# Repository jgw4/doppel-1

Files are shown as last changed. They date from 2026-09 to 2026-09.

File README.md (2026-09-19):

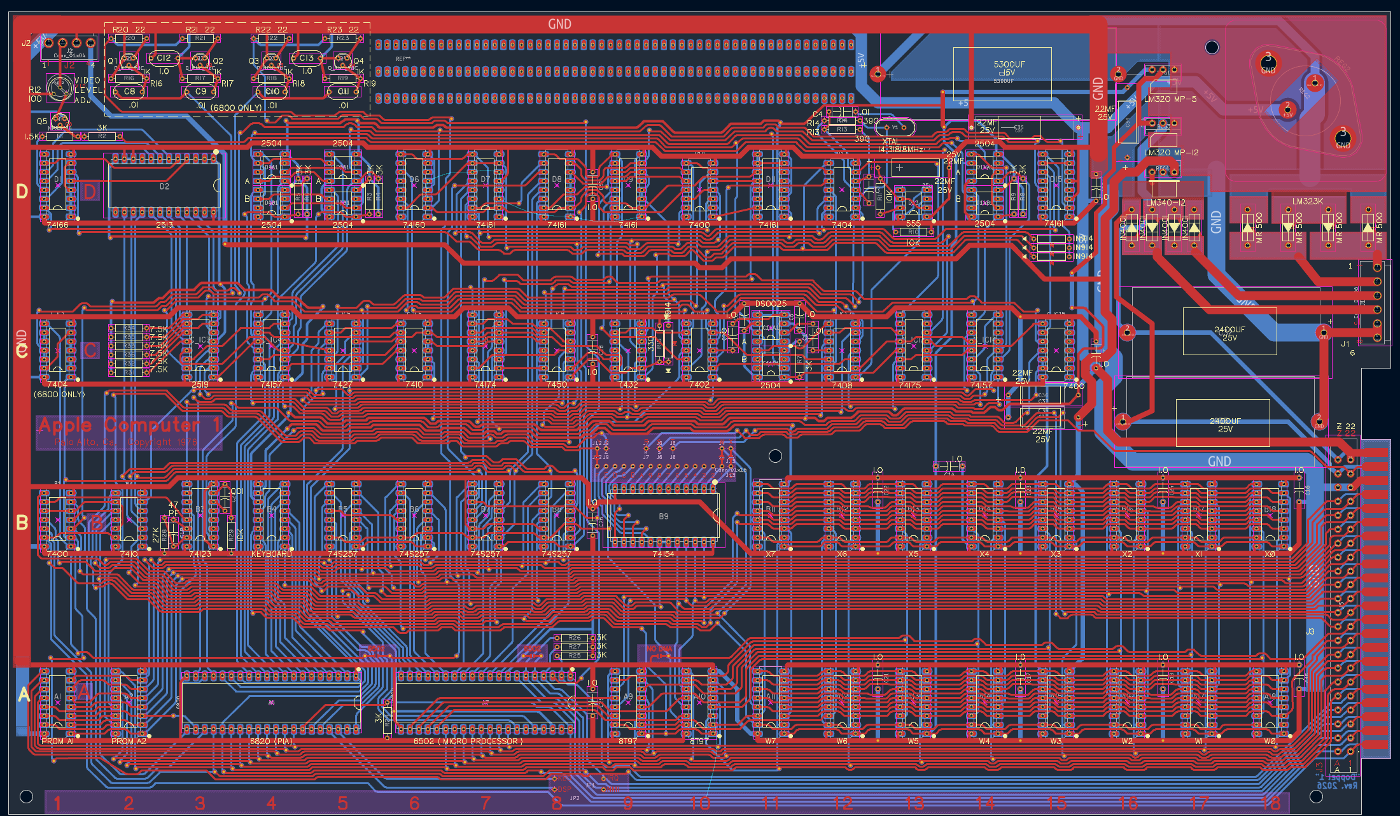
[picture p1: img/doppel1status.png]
Doppel-1 Current Status

Doppel-1 As of 2026/09/18

# About the "Doppel-1"
This repository contains the "Doppel-1", an Apple-1 Replica PCB. It is unique among clone boards in that the source design files are completely open-source, and It is built in standard EDA fashion, where each component on the board is linked to a symbol on a full schematic of the apple-1. This also allows for generating gerber files at the source, easy modification, and the ability to highlight trace sets on the board via the net selector. This makes it very useful when diagnosing build issues. It also features a near full set of 3d components, which allows an accurate step file to be exported.

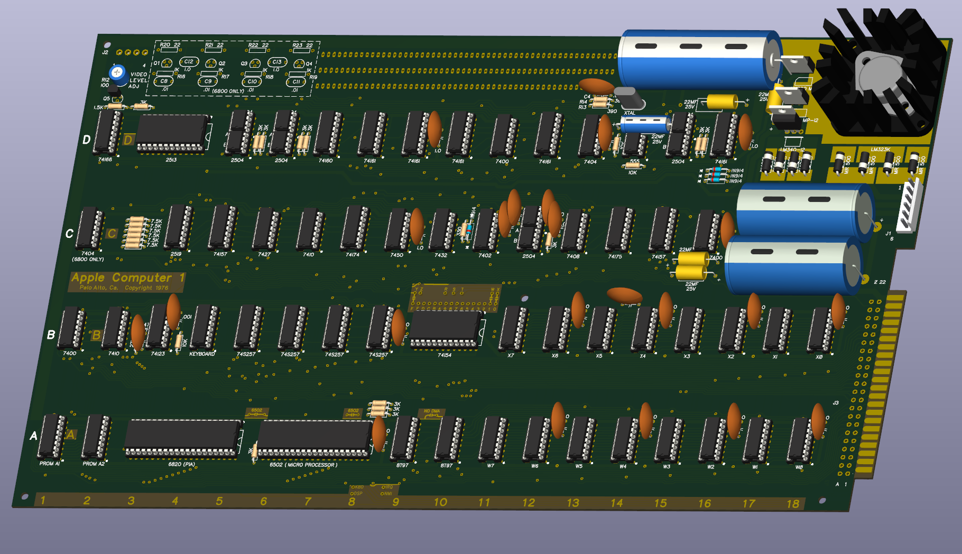
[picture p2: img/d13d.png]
Doppel-1 3D

Doppel-1 within KiCad 3D Viewer

Great care has been taken to create a custom library of footprints that match the original apple-1. In fact, every symbol on the board is custom. This preserves the aesthetics of the pads and silkscreens while allowing for pin-pin linkage from the schematic.

Clarifying remarks have been made to ensure that the PCB is being fabricated to make a reasonable replica. If you desire to make your own board from these files, please read the Manufacturing Notes below.

## History
This project started by importing the gerber files for the "PCB-11" replica that I found on [Applefritter Forums](https://www.applefritter.com/content/apple-1-replica-gerber-files), which were posted originally on a facebook group. It is the only clone board that I know of where the gerber files have been made publicly available. Little by little, I began replacing gerber features with native KiCad features, until there was almost nothing left of the original gerber (see "Open Issues..." Below). A theseus ship of sorts, but improved.

## Open Issues of the Doppel-1

* All board silkscreen text is contained within the top board layer. I have decided that there is no font matched well enough at this time to rely on a font alone. Only shapes have been redrawn at the footprint level.
* Need to fix issues with a few improper diode silkscreen arrow placements
* Proper widths and clearances still need assigned to all traces, ensuring proper spacing from all solder pads and enforcing a more rigorous Design Rules Check.
* I am still not entirely certain the board mounting holes are in the correct position. I had modified it slightly see point 7 below.
* a few remaining schematic parity errors.
* some footprints still don't have 3d models assigned. I think at this time only the molex 4-pin and 6-pin
* I would like to develop a custom font based off the text on this board, so it can be applied as text elements rather than drawn shapes.

## Design Notes And Changes
I have made some remarks about my observations so far:

1) The silkscreen text on the Apple-1 PCB is extremely difficult to reproduce. By all accounts it was hand-stenciled, and I have spent more time than I care to admit comparing uniform-stroke technical typefaces that are meant to replicate leroy lettering or other technical stencil packages that are freely available online, but none of them have quite matched what I have seen on the PCB-11 and on other clones. I have messed around with the font "Routed Gothic" and found it to be closest but kerning is not quite there, and it still does not match with the characters aforementioned. I can hack my way to passable kerning by adjusting the height-width ratio of the text boxes but it is not ideal. I believe Iwater GMaru Gothic Pro is a better match to the original, however that is a paid font that I am unwilling to obtain due to licensing. For any future work on a custom font for this computer, I have included a character "Proof Area" in the PCB file which contains every character on the board.

2) The solder pads on the DIP sockets and breadboard area on "PCB-11" are round on both front and back layers, while on original units, the solderpads were actually different on the back side vs the front. On the back they were a squashed oval (basically an obround but the end arcs share a center point with the rectangle's center point), and on the front they were smaller, tangent obrounds. This was most likely done to make it easy to solder while leaving room for trace paths on the front. This is something a lot of replicas miss.

3) The trace leading to the positive lead between B&C @16 has been adjusted to match the Mimeo-1

4) The trace between C&D @15 leeting to the via below IN914 diode at a 45 degree angle has been moved down slightly to match the Mimeo-1

5) silkscreen outlines for DIP sockets has been increased to a width of 10mils to match what is expected

6) In the original manual's schematics, as well as the ones made by Nicolas, there is an error in the pinouts listed for the TO-220 diodes (REG1,REG3,REG4/LM320 MP-5/LM320 MP-12/LM340 MP-12). LM320 has ground at pin 1, while in and out are pins 2&3, respectively.LM340 has ground at 2 and in/out at 1/3 like a more standard diode in this package. This was discovered by DRC error checking.

7) The top right mounting via has been moved right 100mils to match Mike Willegal's case dimension [here](https://www.willegal.net/appleii/apple1-enclosure.htm). My assumption is that these are truer than what were originally on the board

8) The original applefritter post had a user comment that noted the following issues. My comments are appended to the original marks:
- The original has a matte finish, this one has a sligtly brighter green - This is a fabrication preference/availability, not with the design of the board. see "Manufacturing Notes".
- The silkscreen doesn't cover the plated areas without soldermask.
- The DIP and breadboard solder pads should be wider although it only really matters in the breadboard area. - See point 2 above, much scrutiny went into the shape of the dip pads on this board.
- The video adjustment pot pads are  narrower by 0.025", making it difficult to insert the trimpot. - The 100 Ohm pot has been replaced with a standard footprint that should rectify the issue

9) the LM323 footprint has been moved slightly to the left, on the original and observed builds, the heatsink would hang slightly over the board.

## Manufacturing Notes:

If you are going to get your own replica board manufactured, read this first:

0) Boards are to be purchased at your own risk. I do not take responsibility for any defects, design or otherwise, contained within your finished boards.

1) Normally the green finish provided by PCB manufacturers is way too dark. It has become clear to me that it will be almost impossible to replicate near-exact finishes for small volume with any direct-to-customer fabricators. If the fabricator does allow for lighter green finishes and/or matte green, these colors should be selected instead of a "Standard" green.

2) Boards that are finished with an ENIG process (i.e. full-board gold plating) are unable to also accomodate silkscreening on top of non-soldermasked copper. This is extremely evident in the top-right corner of the board where diode markings are missing where the gold is plated over the copper. It is understandable to desire gold for the longevity of the board, but doing so will produce a poor replica. ENIG is also not sufficient for edge fingers; since ENIG is a softer finish, it will wear just as if it were plated like a standard PCB. Hard Gold plating (not ENIG) is best for edge fingers, and should be confined to the edge fingers only, with the rest done in HAL SnPb.

3) I request that anyone exporting their own gerbers to not remove the replica signifying text on the bottom right on the back of the board. This board contains "Doppel-1 Rev. 2026" on the back copper layer underneath a silkscreen, so it is very discrete. While I think that there are many people out there that can detect replica boards without an unambiguous stamp on the board, I request all reading to preserve the marking to avoid the perception or attempts at counterfeiting.

## Why?
I have had a strange fascination for the Apple-1 ever since I was a kid. Even though I am not a competent electronics hobbyist or electrical engineer, I've been drawn to the technical artistry of the board, and find the assembly process and case design around it a very cool method of self-expression. I suppose also there is a love of historical artifact that comes with people who love these computers too, and I am very much in that camp.

# Contributing
1) To properly view some of the pcb file's text elements, you may need to  download and install "Routed Gothic" font located in `/doc/`. This is the closest match I have found to the original PCB lettering in font form and is based on the Leroy stenciling system common with draftsman before computer fonts.

2) I have a near certain guess that the original apple-1 pcb was designed using mils. Thus, I would strongly encourage any user working on this board to set their units to mils and not mm. The original PCB-11 file was most likely not made by an American, as there are many metric dimensions scattered throughout the document. However building in nice round mil numbers should be the standard for this project

3) please submit a pull request listing in detail all changes you have made or would like to make, preferably with pictures. This can help avoid any duplicate work. I can infer many changes by inspecting the changed files as text, but a more human-readable explanation helps.

4) Issues can also be raised, which I also enthusiastically accept. If you spot issues with the design of the board, please post an issue to the repository.

5) I am looking also for some more specific input on trace clearance. Since resizing the dip solderpads, clearance has been the biggest DRC issue. I would like to know what spacing was used on the original board so I can preserve that. Current clearance is set at 5 mils.

# Other Things to check out

[Erik's Ponderings - Building an Apple-1](https://blog.bruchez.name/posts/apple-1-reproduction-part-1-components/) - Erik Bruchez documented his process of building an exceptional Apple-1 clone in great detail, including some great tips for power supply building, adding more decoupling capacitors, mechanical tips, and more. Really neat to check out, especially before you build one of your own

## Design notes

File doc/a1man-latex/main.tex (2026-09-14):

\documentclass[letterpaper]{article}

% Core packages
\usepackage[top=1in,bottom=1in,left=1in,right=1in]{geometry}
\usepackage{graphicx}
\usepackage{multicol}
\usepackage{fancyhdr}
\usepackage{eso-pic}
\usepackage[explicit]{titlesec}
\usepackage{varwidth}
\usepackage{parskip}
\usepackage{tgcursor}
\usepackage{fontspec}

% Font setup
\fontsize{10pt}{10pt}\selectfont
\setmainfont[
  Path=fonts/,
  Extension=.ttf
]{Typewriter-Executive}

% Graphics paths
\graphicspath{{pages/}}

% Page number settings
\pagestyle{fancy}
\fancyhf{}                    % Clear all headers and footers
\fancyfoot[C]{-\thepage-}     % Bottom center: -1-
\renewcommand{\headrulewidth}{0pt}
\renewcommand{\footrulewidth}{0pt}
\setlength{\footskip}{24pt}

% Body text settings
\parskip=8pt
\parindent=3em
\setcounter{secnumdepth}{0}
\setlength{\fboxsep}{6pt}

% Section styling
\titleformat{\section}[block]
  {\normalfont\large\bfseries\centering}
  {}
  {0pt}
  {\makebox[\linewidth][c]{\fbox{\begin{varwidth}{\linewidth}\centering #1\end{varwidth}}}}
\titlespacing*{\section}{0pt}{*2}{*1}
%%%%%%%%%%%%%%%%%%%%%%%%%%%%%%%%%%%%%%%%%%%%%
\begin{document}
\begin{titlepage}
\thispagestyle{empty}
\centering

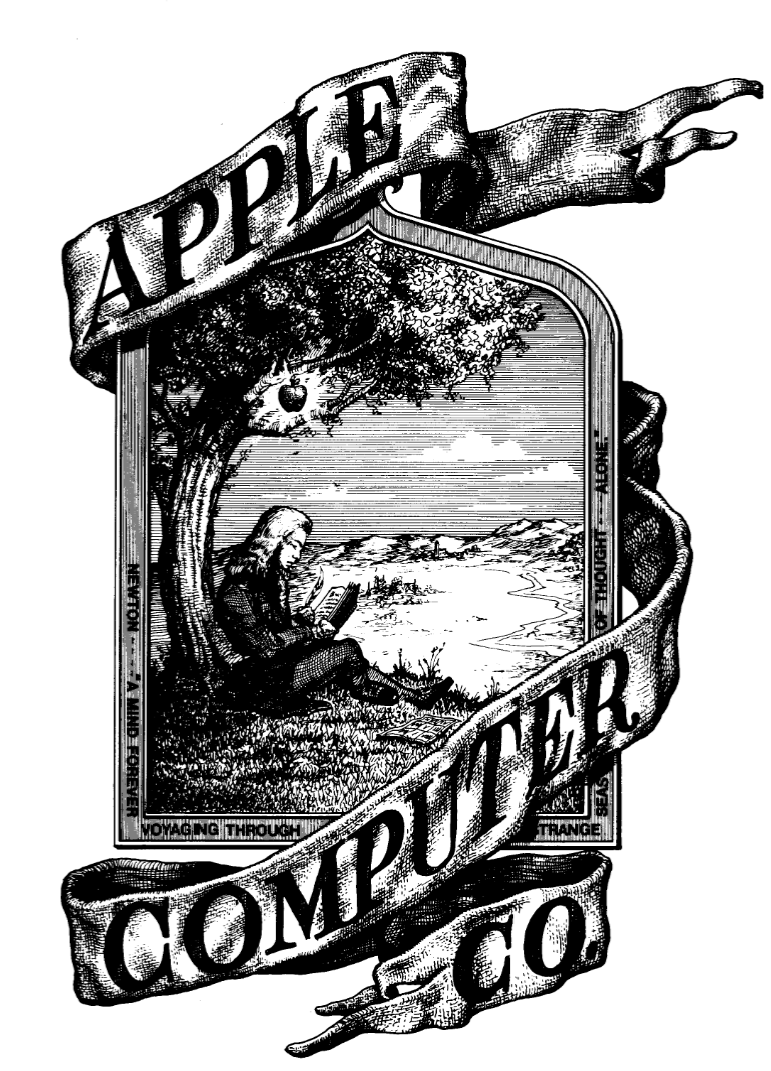
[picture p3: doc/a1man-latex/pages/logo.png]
\vspace{2.5cm}

{\bf \Huge
APPLE-1
\vspace{1cm}

OPERATION

MANUAL
}
\vspace{2cm}

{\fontspec{Helvetica}
APPLE COMPUTER COMPANY

770 Welch Road

Palo Alto, California 94304
}
\end{titlepage}
%%%%%%%%%%%%%%%%%%%%%%%%%%%%%%%%%%%%%%%%%%%%%
\begin{center}
  SPECIFICATIONS
\end{center}
\begin{tabular}{p{0.46\textwidth} p{0.46\textwidth}}
  
MICROPROCESSOR:&MOS Technology 6502\\

Microprocessor Clock Frequency:&1.023 MHz\\

Effective Cycle Frequency:&0.960 Mhz\\

(Including Refresh Waits)&\\

VIDEO OUTPUT:&Composite positive video, 75 ohms, level adjustable between zero and +5V pp.\\

Line Rate:&15734 Hz\\
Frame Rate:&60.06 Hz\\
Format&40 characters/line, 24 lines; with automatic scrolling\\
Display Memory:&Dynamic shift registers (1K x 7)\\
Character Matrix:&5 x 7\\
\end{tabular}
\clearpage
\setcounter{page}{1}
\newpage
\begin{center}
\section{INTRODUCTION}
\end{center}
\begin{multicols}{2}

The Apple Computer is a complete microprocessor system, consisting of a Mos Technology 6502 microprocessor and support hardware, integral video display electronics, dynamic memory and refresh hardware, and fully regulated power supplies. It contains resident system monitor software, enabling the user, via the keyboard and display, to write, examine, debug, and run programs efficiently; thus being an educational tool for the learning of microprocessor programming, and an aid in the development of software.

The integral video display section and the keyboard interface renders unnecessary the need for an external teletype. The display section contains its ownmemory, leaving all of RAM for user programs, and the output format is 40 characters/ line, 24 lines/page, with auto scrolling. Almost any ASCII encoded keyboard will interface directly with the Apple system.

The board has sockets for upto 8K bytes of the 16 pin, 4K type, RAM, and the system is fully expandable to 65K via the edge connector. The system uses dynamic memory (4K bytes supplied), although static memory may also be used. All refreshing of dynamic memory, including all "off-board'" expansion memory, is done automatically. The entire system timing, including the microprocessor clock and all video signals, originates in a single crystal oscillator.

Further, the printed circuit board contains a "breadboard area", in which the user can add additional "on-board" hardware (for example, extra PIA's, ACIA's, EROM's, and so on).

This manual is divided into three Sections:

\noindent Section I GETTING THE SYSTEM RUNNING

\noindent Section II USING THE SYSTEM MONITOR. (listing included)

\noindent Section III EXPANDING THE SYSTEM.

Please read Section I thoroughly, before attempting to "power-up" your system, and study Section III carefully before attempting to expand your system. In addition to this manual, Apple 'Tech Notes" are available which contain examples of expansion hardware and techniques.
\end{multicols}
\begin{center}
\section{SECTION I
\newline
GETTING THE SYSTEM RUNNING}   
\end{center}

\begin{multicols}{2}
The Apple Computer is fully assembled, tested, and burned in. The only external devices necessary for operation of the system are: An ASCII encoded keyboard, a video display monitor, and AC power sources of 8 to 10 Volts (RMS) @3 amps and 28Volts(RMS)@1 amp. The following three articles describe the attachment of these devices in detail.

\noindent Keyboard:

Any ASCII encoded keyboard, with positive DATA outputs, interfaces directly with the Apple system via a "DIP" connector, If your keyboard has negative logic DATA outputs (rare), you can install inverters (7404) in the breadboard area. The strobe can be either positive or negative, of long or short duration. The 'DIP" keyboard connector (B4) has inputs for seven DATA lines, one STROBE line, and two normally-open pushbutton switches, used for RESET (enter monitor), and CLEAR SCREEN (see schematic diagram, sheet 3 of 3, for exact circuitry). This keyboard connector also supplies three voltages, (45V, +12V, and-12V) of which one or more may be necessary to operate the keyboard. Pin 15 of the keyboard connector (B4) must be tied to +5V (pin 16) for normal operation,

\noindent NOTE: The system monitor accepts only uppercase alpha (A-F, R).

It is therefore convenient, though it's not essential, to have akeyboard equipped with uppercase alpha lock (usually in the electronics). Either of the following suggested circuits may be used to provide alpha lock capability, if needed, and can be built in the breadboard area.
\AddToShipoutPictureBG*{
  \AtPageLowerLeft{
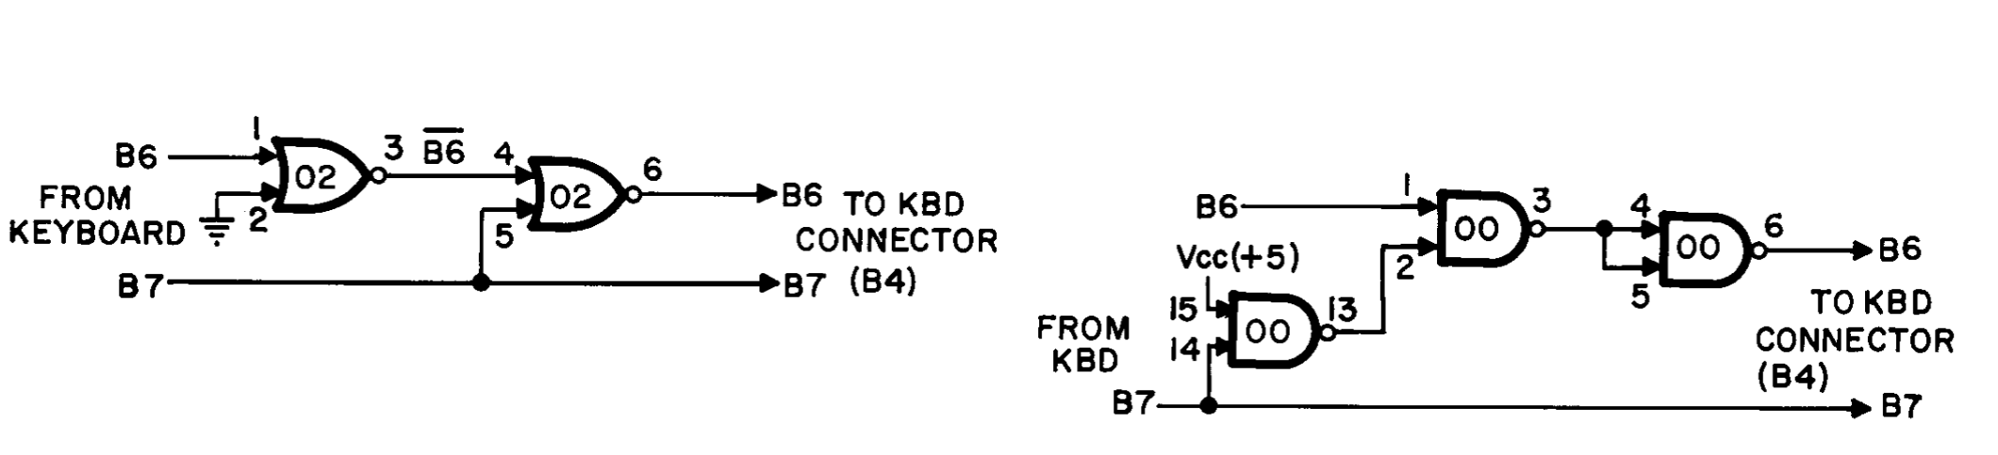
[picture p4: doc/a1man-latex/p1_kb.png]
    \makebox[\paperwidth][c]{}%
  }
}

\newpage
\noindent Display:

The Apple Computer outputs a composite video signal (composite of sync and video information) which can be applied to any standard raster-scan type video display monitor. The output level is adjustable with the potentiometer located near the video output Molex connector, J2. The additional two outside pins on the Molex connector supply +5and+l2 volts, to be used in future Apple accessories. The composite video signal can also be modulated atthe proper RF frequency, with an inexpensive commercially available device, and applied to the antenna terminals of a home television receiver. Since the character format is 40 characters /line, all television receivers will have the necessary bandwidth to display the entire 40 characters. Two large manufacturers of video display monitors, which connect directly with the Apple Computer, are Motorola and Ball. The mating four-pin Molex connector is provided.

\noindent AC Power Sources:

Two incoming AC power sources are required for operation: 8tol0 VAC (RMS) at 3 amps, and 28VAC(RMS) Center-Tapped at lamp. These AC supplies enter the system at the Molex connector, Jil. The 8tol0 volts AC provides the raw AC for the +5 volt supply, while the 28 VCT supplies the raw AC for the +12 and -12 volt supplies, and the -5V supply is derived from the -12V regulated output.

The board, as supplied, requires no more than 1.5 amps DC from the 45V supply, while the regulator is capable of supplying 3 amps. The remaining 1.5 amps DC from the 45V supply is available for user hardware expansion (provided suitable transformer ratings are employed).

A suitable source of the raw AC voltages required, are two commercially available trans— formers; Stancor P/N P-8380 or equivalent (8 to 10 volts at 3 amps), and Stancor P/N P-8667 or

equivalent (28VCT at 1 amp). Simply wire the secondaries tothe mating six~pin Molex connector supplied, and wire the primaries in parallel, as shown in the schematic diagram (power supply section, Dwg.No. 00101, sheet 3 of 3.

\noindent TEST PROGRAM

After attaching the keyboard, display, and AC power sources, you can try a simple program to test if your system and the attachments are functioning together properly. While it does not test many possible areas of the microprocessor system, the test program will test for the correct attachment of the keyboard, display, and power supplies.

FIRST:

Hit the RESET button to enter the system monitor. A backslash shouldbe displayed, andthecursor shoulddroptothe nextline,

SECOND:

Type- $\emptyset$:A9b$\emptyset$ bAAK2$\emptyset$bEFbDFF bd E8 b 8A b4C b2b$\emptyset$ (RET)

($\emptyset$ is a zero, NOT an alpha "''"O''; b means blank or space; and (RET) hit the ''return!" key on the keyboard)

THIRD:

Type- $\emptyset$.A(RET)

(This should print out, on the display, the program you have just entered,)

FOURTH: Type- R(RET) (R means run the program.)

THE PROGRAM SHOULD THEN PRINT OUT ON THE DISPLAY A CONTINUOUS STREAM OF ASCII CHARACTERS, TO STOP THE PROGRAM AND RETURNTOTHE SYSTEM MONITOR, HIT THE "RESET" BUTTON. TO RUN AGAIN, TYPE: R (RET).
\end{multicols}
\newpage
\begin{center}
\section{SECTION II
USING THE SYSTEM MONITOR}
\end{center}
\begin{multicols}{2}
The Hex Monitor is a PROM program in locations FF$\emptyset$$\emptyset$ to FFFF (hex) which uses the keyboardand display to perform the front panel functions of examining memory, and running programs. The monitor program is entered by hitting (RESET), which displays backslash-return. A backslash alone (cursor remains on same line as backslash) indicates bad page 0 RAM.

Commands are typed on a "line-at-a-time" basis with editing. Each line may consist of any number of commands (up to l28 characters). None are executed until (RETURN) is typed. The (SHIFT-0) (backarrow) backspaces and echos an underline. The (ESC) cnacels a line and echos backslash-return.

One or more hexadecimal digits (0-9, A-F) are used for address and data values. Addresses use the four least significant digits of a group, and data values, the two least significant digits. The following examples illustrate the variety of acceptable commands:
\begin{enumerate}
\item Opening a location (examining the contents of a single address).

USER TYPES/ 4F (RET)

MONITOR TYPES/ $\emptyset$$\emptyset$4F: $\emptyset$F (contents of 4F)

\item Examining a block; fromthe last examined location, to a specified one.

USER TYPES/ .5A (RET)

MONITOR TYPES/ $\emptyset$$\emptyset$5$\emptyset$: $\emptyset$$\emptyset$ $\emptyset$1 $\emptyset$2 $\emptyset$3 $\emptyset$4 $\emptyset$5 $\emptyset$6 $\emptyset$7 $\emptyset$$\emptyset$58: $\emptyset$8 $\emptyset$9 $\emptyset$A 

Note: 4F is still considered the most recently opened location.

\item Combining examples 1 and 2 to print a block of memory in a single command.

USER TYPES/ 4F,5A (RET)

MONITOR TYPES  $\emptyset$$\emptyset$5$\emptyset$: $\emptyset$$\emptyset$ $\emptyset$1 $\emptyset$2 $\emptyset$3 $\emptyset$4 $\emptyset$5 $\emptyset$6 $\emptyset$7 $\emptyset$$\emptyset$58: $\emptyset$8 $\emptyset$9 $\emptyset$A 

Note: Only the first location of the block (4F) is considered "opened!".

\item Examining several individual locations at once.

USER TYPES/ AF b 52 b 56 (RET)

MONITOR TYPES/ $\emptyset$$\emptyset$4F: $\emptyset$F $\emptyset$$\emptyset$52: $\emptyset$2 $\emptyset$$\emptyset$56: $\emptyset$6

Note:

56 is considered the most recently "opened" location. The 'b' is a blank or comma, and is a delimiter for separation purposes only. A string of delimiters has the same effect as a single one (bbb is as effective as b).

\item Examining several blocks of memory at once.

USER TYPES/ 4F. 52 b 56 b 58.5A (RET)

MONITOR TYPES/ $\emptyset$$\emptyset$4F: $\emptyset$F

$\emptyset$$\emptyset$52: $\emptyset$2

$\emptyset$$\emptyset$56: $\emptyset$6

$\emptyset$$\emptyset$58: $\emptyset$8 $\emptyset$9 $\emptyset$5A: $\emptyset$A

Note: 58is considered the most recently opened” location. Refer to example 2.

\item Examining successive blocks.

USER TYPES/ 4F.52 (RET)

MONITOR TYPES/ $\emptyset$$\emptyset$4F: $\emptyset$F $\emptyset$$\emptyset$5$\emptyset$: $\emptyset$$\emptyset$ $\emptyset$1 $\emptyset$2

USER TYPES/ .55 (RET)

MONITOR TYPES/ $\emptyset$$\emptyset$53: $\emptyset$3 $\emptyset$4 $\emptyset$5

USER TYPES/ .5A (RET)

MONITOR TYPES/ $\emptyset$$\emptyset$56: $\emptyset$6 $\emptyset$7

$\emptyset$$\emptyset$58: $\emptyset$8 $\emptyset$9 $\emptyset$A

\item Depositing data in a single location.

USER TYPES/ 3$\emptyset$: A$\emptyset$ (RET)

MONITOR TYPES/ $\emptyset$$\emptyset$3$\emptyset$: FF (prior contents)

Location 39 is considered opened and now contains 39.

\item Depositing data in successive locations from that last used in a deposit command.

USER TYPES/ : Al b A2 b A3 b A4

b A5 (RET)

(This deposits Al in location 31, A2 in 32, and so on.)

\item Combining examples 7 and 8 in a single command.

USER TYPES/ 3$\emptyset$: A$\emptyset$ b Al b A2 b

A3 b A4 b A5 (RET)

MONITOR TYPES/

$\emptyset$$\emptyset$3$\emptyset$: FF (prior contents of location 3$\emptyset$)

\item Depositing data in successive locations with separate commands.

USER TYPES/ 3$\emptyset$: A$\emptyset$ b A1 (RET)
MONITOR TYPES/ $\emptyset$$\emptyset$3$\emptyset$: FF
USER TYPES/ :A2 b A3 (RET)
USER TYPES/ :A4 b A5 (RET)
\newpage

Note: A colon in a command means "start depositing data from the most recently deposited location, or if none, then from the most recently opened one.

\item Examining a block, then depositing into it. 

USER TYPES/ 30.35 (RET)

MONITOR TYPES/ 

$\emptyset$$\emptyset$3$\emptyset$: A$\emptyset$ Al A2 A3 A4 A5 A6

USER TYPES/

:B0 b B1 b B2 b B3 b B4 b B5 (RET)

Note: New data deposited beginning at most recently opened location (39)

\item Run a program at a specified address.

USER TYPES/ 1$\emptyset$F$\emptyset$ R (RET)

MONITOR TYPES/ 1$\emptyset$F$\emptyset$: A9 (contents)

Note: The cursor is left immediately to the right of the 'A9"'; it is not returned to the next line.

\item Run atthe most recently examined location.

USER TYPES/ 1$\emptyset$F$\emptyset$ (RET)

MONITOR TYPES/ 1$\emptyset$F$\emptyset$: A9

USER TYPES/ R (RET)

\item Enter a program into memory and run it in one line.

USER TYPES/ 4$\emptyset$: A9 b $\emptyset$ b 2$\emptyset$ b EF b FF b 38 b 69 b

MONITOR TYPES/ 4$\emptyset$: FF (prior contents of 4$\emptyset$)
MONITOR TYPES/ 4$\emptyset$: FF (prior contents of 4$\emptyset$)

\item An "on line" error correction.

USER TYPES/

4$\emptyset$: Al b A2 b A3A4A5\underline{A6} b A7

 (data A6 will be loaded in location 42)
 
 USER TYPES/ 4$\emptyset$5$\emptyset$6$\emptyset$7$\emptyset$: AA

 (data AA will be loaded in location 6$\emptyset$7$\emptyset$)

 \item Useful routines in monitor which can be accessed by user programs.
 
 GETLINE: location FF1F:
 
 monitor entry point

(jumping to FF1F will enter monitor and echo carriage return. You can then examine memory locations with the monitor.)

ECHO: location FFEF:

prints one byte (ASCII)

(data from "A" (accumulator), contents of ''A'' not disturbed. Example:

2$\emptyset$ b EF b FF (JRS ECHO)).

PRBYTE: location FFDC:

prints one byte (HEX)

(data from "A", contents of "A" disturbed.) 

PRHEX: location FFES5:

rints one hex digit

(data from four least significant bits of "A", contents of "A" disturbed.)
\end{enumerate}
\end{multicols}
\begin{center}
NOTE: Capital letters enclosed in parenthesis represent single keystrokes.
Example: (RET) means hit the "return" key
\end{center}
\newpage
\begin{multicols}{2}

\end{multicols}
\begin{center}
NOTE: RAM locations $\emptyset$$\emptyset$24 to $\emptyset$$\emptyset$2B are used as index pointers by the monitor, and are invalid for user use, when using monitor. Also, locations $\emptyset$$\emptyset$2$\emptyset$ to $\emptyset$27F are used as input buffer storage, and are also invalid for user use when using the monitor.

\newpage

65$\emptyset$2 HEX MONITOR LISTING
\end{center}

\begin{tabbing}
FF$\emptyset\emptyset$\hspace{.18in}\=D8\hspace{.75in}\=RESET\hspace{.5in}\=CLD\hspace{1.25in}\={\rmfamily Clear Decimal arithmetic mode}\\
FF$\emptyset$1\>58\>\>CLI\>\\
FF$\emptyset$2\>A$\emptyset$ 7F\>\>LDY \#\$7F\>{\rmfamily Mask for DSP data direction register}\\
FF$\emptyset$4\>8C 12 D$\emptyset$ \> \>STY DSP \>{\rmfamily Set it up}\\
FF$\emptyset$7\>A9 A7\>\>LDA \#\$A7\>{\rmfamily KBD and DSP control register mask}\\
FF$\emptyset$9\>8D 11 D$\emptyset$\>\>STA KBD CR\>{\rmfamily Enable interrupts, set CA1, CB1, for}\\
FF$\emptyset$C\>8D 11 D$\emptyset$\>\>STA DSP CR\> {\rmfamily \hspace{.125in}positive edge sense/output mode}\\
FF$\emptyset$F\>8D 13 D$\emptyset$\>NOTOR\>CMP \#\$DF\>{\rmfamily "$\Leftarrow$"?}\\
FF11\>F$\emptyset$ 13\>\>BEQ BACKSPACE\>{\rmfamily Yes.}\\
FF13\>C9 9B\>\>CMP \#\$9B\>{\rmfamily ESC?}\\
FF15\>F$\emptyset$ 03\>\>BEQ ESCAPE\>{\rmfamily Yes.}\\
FF17\>C8\>\>INY\>{\rmfamily Advance text index.}\\
FF18\>1$\emptyset$ $\emptyset$F\>\>BPL NEXTCHAR\>{\rmfamily Auto ESC if > 127.}\\
FF1A\>A9 DC\>ESCAPE\>LDA \#\$DC\>{\rmfamily "$\backslash$".}\\
FF1C\>20 EF FF\>\>JSR ECHO\>{\rmfamily Output it.}\\
FF1F\>A9 8D\>GETLINE\>LDY \#\$$\emptyset$1\>{\rmfamily CR.}\\
FF21\>2$\emptyset$ EF FF\>\>JSR ECHO\>{\rmfamily Output it.}\\
FF24\>A$\emptyset$ $\emptyset$1\>\>LDY \#\$$\emptyset$1\>{\rmfamily Initialize text index.}\\
FF26\>88\>BACKSPACE\>DEY\>{\rmfamily Back up text index.}\\
FF27\>3$\emptyset$ F6\>\>BMI GETLINE\>{\rmfamily Beyond start of line, reinitialize.}\\
FF29\>AD 11 D$\emptyset$\>NEXTCHAR\>LDA KBD CR\>{\rmfamily Key ready?}\\
FF2C\>1$\emptyset$ FB\>\>BPL NEXTCHAR\>{\rmfamily Loop until ready.}\\
FF2E\>AD 1$\emptyset$ D$\emptyset$\>\>LDA KBD\>{\rmfamily Load Character. B7 should be '1'.}\\
FF31\>99 $\emptyset$$\emptyset$ $\emptyset$2\>\>STA IN, Y\>{\rmfamily Add to text buffer.}\\
FF34\>2$\emptyset$ EF FF\>\>JSR ECHO\>{\rmfamily Display character.}\\
FF37\>C9 8D\>\>CMP \#\$8D\>{\rmfamily CR?}\\
FF39\>D$\emptyset$ D4\>\>BNE NOTOR\>{\rmfamily No.}\\
FF3B\>A$\emptyset$ FF\>\>LDY \#\$FF\>{\rmfamily Reset text index.}\\
FF3D\>A$\emptyset$ FF\>\>LDA \#\$$\emptyset\emptyset$\>{\rmfamily For XAM mode.}\\
FF3F\>AA\>\>TAX\>{\rmfamily $\emptyset\rightarrow$ X}\\
FR4$\emptyset$\>$\emptyset$A\>SETSTOR\>ASL\>{\rmfamily Leaves \$7B if setting STOR mode.}\\
FF41\>85 2B\>SETMODE\>STA MODE\>{\rmfamily \$$\emptyset\emptyset$ = XAM, \$7B = STOR, \$AE = BLOK XAM.}\\
FF43\>C8\>BLSKIP\>INY\>{\rmfamily Advance text index.}\\
FR44\>B9 $\emptyset$$\emptyset$ $\emptyset$2\>NEXT ITEM\>LDA IN, Y\>{\rmfamily Get character.}\\
FF47\>C9 8D\>\>CMP \#\$8D\>{\rmfamily CR?}\\
FF49\>F$\emptyset$ D\>\>BEQ GETLINE\>{\rmfamily Yes, done this line.}\\
FF4B\>C9 AE\>\>CMP \#\$AE\>{\rmfamily "."?}\\
FF4D\>9$\emptyset$ F4\>\>BCC BLSKIP\>{\rmfamily Skip delimiter.}\\
FF4F\>F$\emptyset$ F$\emptyset$\>\>BEQ SETMODE\>{\rmfamily Set BLOCK XAM mode.}\\
FF51\>C9 BA\>\>CMP \#\$BA\>{\rmfamily ":"?}\\
FF53\>F$\emptyset$ EB\>\>BEQ SETSTOR\>{\rmfamily Yes, set STOR mode.}\\
FF55\>C9 D2\>\>CMP \#\$D2\>{\rmfamily "R"?}\\
FF57\>F$\emptyset$ 3B\>\>BEQ RUN\>{\rmfamily Yes, run user program.}\\
FF59\>86 28\>\>STX L\>{\rmfamily \$$\emptyset\emptyset\rightarrow$L.}\\
FF5B\>86 29\>\>STX H\>{\rmfamily \hspace{.125in}and H.}\\
FF5D\>84 2A\>\>STY YSAV\>{\rmfamily Save Y for comparison.}\\
FF5F\>B9 $\emptyset\emptyset$ $\emptyset$2\>NEXTHEX\>LDA IN, Y\>{\rmfamily Get character for hex test.}\\
FF62\>49 B$\emptyset$\>\>EOR \#\$B$\emptyset$\>{\rmfamily Map digits to \$$\emptyset$-9.}\\
FF64\>C9 0$\emptyset$\>\>CMP \#\$$\emptyset$A\>{\rmfamily Digit?}\\
FF66\>9$\emptyset$ $\emptyset$6\>\>BCC DIG\>{\rmfamily Yes.}\\
FF68\>69 88\>\>ADC \#\$88\>{\rmfamily Map letter "A"-"F" to \$FA-FF.}\\
FF6A\>C9 FA\>\>CMP \#\$FA\>{\rmfamily Hex letter?}\\
FF6C\>9$\emptyset$ 11\>\>BCC NOTHEX\>{\rmfamily No, character not hex.}\\
FF6E\>$\emptyset$A\>DIG\>ASL\>\\
FF6F\>$\emptyset$A\>\>ASL\>{\rmfamily Hex digit of MSD of A.}\\
FF7$\emptyset$\>$\emptyset$A\>\>ASL\>\\
FF71\>$\emptyset$A\>\>ASL\>\\
FF72\>A2 $\emptyset$4\>\>LDX \#\$$\emptyset$4\>{\rmfamily Shift count.}\\
FF74\>$\emptyset$A\>HEXSHIFT\>ASL\>{\rmfamily Hex digit left, MSB to carry}\\
FF75\>26 28\>\>ROL L\>{\rmfamily Rotate into LSD.}\\
FF77\>26 29\>\>ROL H\>{\rmfamily Rotate into MSD's.}\\
FF79\>CA\>\>DEX\>{\rmfamily Done 4 shifts?}\\
FF7A\>D$\emptyset$ F8\>\>BNE HEXSHIFT\>{\rmfamily No, loop.}\\
FF7C\>C8\>\>INY\>{\rmfamily Advance text index.}\\
FF7D\>D$\emptyset$ E$\emptyset$\>\>BNE NEXTHEX\>{\rmfamily Always taken. Check next character for hex.}\\
FF7F\>C4 2A\>NOTHEX\>CPY YSAV\>{\rmfamily Check if L, H empty (no hex digits).}\\
FF81\>F$\emptyset$ 97\>\>BEQ ESCAPE\>{\rmfamily Tes, generate ESC sequence.}\\
FF83\>24 2B\>\>BITMODE\>{\rmfamily Test MODE byte.}\\
FF85\>5$\emptyset$ 1$\emptyset$\>\>BVC NOTSTOR\>{\rmfamily B6 = $\emptyset$ for STOR, 1 for XAM and BLOCK XAM}\\
FF87\>A5 28\>\>LDA L\>{\rmfamily LSD's of hex data.}\\
FF89\>81 26\>\>STA (STL, X)\>{\rmfamily Store at current 'store index'.}\\
FF8B\>E6 26\>\>INC STL\>{\rmfamily Increment Store index.}\\
FF8D\>D$\emptyset$ B5\>\>BNE NEXTITEM\>{\rmfamily Get next item (no carry).}\\
FF8F\>E6 27\>\>INC STH\>{\rmfamily Add carry to 'store index' high order.}\\
FF91\>4C 44 FF\>TONEXTITEM\>JMP NEXTITEM\>{\rmfamily Get next command item.}\\
FF94\>6C 24 $\emptyset\emptyset$\>RUN\>JMP (XAML) \>{\rmfamily Run at current XAM index.}\\
FF97\>3$\emptyset$ 2B\>NOTSTOR\>BMI XAMNEXT\>{\rmfamily B7 = $\emptyset$ for XAM, 1 for BLOCK XAM.}\\
FF99\>A2 $\emptyset$2\>\>LDX \#\$$\emptyset$2\>{\rmfamily Byte count.}\\
FF9B\>B5 27\>SETADR\>LDA L-1, X\>{\rmfamily Copy hex data to}\\
FF9D\>95 25\>\>STA ST; -1, X\>{\rmfamily \hspace{.125in}'store index'.}\\
FF9F\>95 23\>\>STA XAML-1, X\>{\rmfamily And to 'XAM index'}\\
FFA1\>CA\>\>DEX\>{\rmfamily Next 2 bytes.}\\
FFA2\>D$\emptyset$ F7\>\>BNE SETADR\>{\rmfamily Loop unless X = $\emptyset$.}\\
FFA4\>D$\emptyset$ 14\>NXTPRNT\>BNE PRDATA\>{\rmfamily NE means no address to print.}\\
FFA6\>A9 8D\>\>LDA \#\$8D\>{\rmfamily CR.}\\
FFA8\>2$\emptyset$ EF FF\>\>JSR ECHO\>{\rmfamily Output it.}\\
FFAB\>A5 25\>\>LDA XAMH\>{\rmfamily 'Examine index' high-order byte.}\\
FFAD\>2$\emptyset$ DC FF\>\>JSR PRBYTE\>{\rmfamily Output it in hex format.}\\
FFB$\emptyset$\>A5 24\>\>LDA XAML\>{\rmfamily Low-order 'examine index' byte.}\\
FFB2\>2$\emptyset$ DC FF\>\>JSR PRBYTE\>{\rmfamily Output it in hex format.}\\
FFB5\>A9 BA\>\>LDA \#\$BA\>{\rmfamily ":".}\\
FFB7\>2$\emptyset$ EF FF\>\>JSR ECHO\>{\rmfamily Output it.}\\
FFBA\>A5 24\>PRDATA\>LDA \#\$A$\emptyset$\>{\rmfamily Blank.}\\
FFBC\>2$\emptyset$ EF FF\>\>JSR ECHO\>{\rmfamily Output it.}\\
FFBF\>A1 24\>\>LDA (XAML, X)\>{\rmfamily Get data byte at 'examine index'.}\\
FFC1\>2$\emptyset$ DC FF\>\>JSR PRBYTE\>{\rmfamily Output it in hex format.}\\
FFC4\>86 2B\>XAMNEXT\>STX MODE\>{\rmfamily $\emptyset\rightarrow$MODE (XAM mode).}\\
FFC7\>A5 24\>\>LDA XAML\>\\
FFC8\>C5 28\>\>CMP L\>{\rmfamily Compare 'examine index' to hex data.}\\
FFCA\>A5 25\>\>LDA XAMH\>\\
FFCC\>E5 29\>\>SBC H\>\\
FFCE\>B$\emptyset$ C1\>\>BCS TONEXTITEM\>{\rmfamily Not less, so no more data to output.}\\
FFD$\emptyset$\>E6 24\>\>INC XAML\>\\
FFD2\>D$\emptyset$ $\emptyset$2\>\>BNE MOD8CHK\>{\rmfamily Increment 'examine index'.}\\
FFD4\>E6 25\>\>INC XAMH\>\\
FFD6\>A5 24\>MOD8CHK\>LDA XAML\>{\rmfamily Check low-order 'examine index' byte}\\
FFD8\>29 $\emptyset$7\>\>AND \#\$$\emptyset$7\>{\rmfamily \hspace{.125in} For MOD 8= $\emptyset$}\\
FFDA\>1$\emptyset$ C8\>\>BPL NXTPRNT\>{\rmfamily Always taken.}\\
FFDC\>48\>PRBYTE\>PHA\>{\rmfamily Save A for LSD.}\\
FFDD\>4AA\>\>LSR\>\\
FFDE\>4A\>\>LSR\>\\
FFDF\>4A\>\>LSR\>{\rmfamily MSD to LSD position.}\\
FFE$\emptyset$\>4A\>\>LSR\>\\
FFE1\>2$\emptyset$ E5 FF\>\>JSR PRHEX\>{\rmfamily Output hex digit.}\\
FFE4\>68\>\>PLA\>{\rmfamily Restore A}\\
FFE5\>29 $\emptyset$F\>PRHEX\>AND \#\$$\emptyset$F\>{\rmfamily Mask LSD for hex print}\\
FFE7\>$\emptyset$9 B$\emptyset$\>\>ORA \#\$B$\emptyset$\>{\rmfamily add "$\emptyset$".}\\
FFE9\>C9 BA\>\>CMP \#\$BA\>{\rmfamily Digit?}\\
FFEB\>9$\emptyset$ $\emptyset$2\>\>BCC ECHO\>{\rmfamily Yes, output it.}\\
FFED\>69 $\emptyset$6\>\>ADC \#\$$\emptyset$6\>{\rmfamily Add offset for letter.}\\
FFEF\>2C 12 D$\emptyset$\>ECHO\>BIT DSP\>{\rmfamily DA bit (B7) cleared yet?}\\
FFF2\>3$\emptyset$ FB\>\>BMI ECHO\>{\rmfamily No, wait for display.}\\
FFF4\>8D 12 D$\emptyset$\>\>STA DSP\>{\rmfamily Ooutput character. Sets DA.}\\
FFF7\>6$\emptyset$\>\>RTS\>{\rmfamily Return}\\
FFF8\>$\emptyset\emptyset$ $\emptyset\emptyset$ (unused)\\
FFFA\>$\emptyset\emptyset$ $\emptyset$F (NMI)\\
FFFC\>$\emptyset\emptyset$ FF (RESET)\\
FFFE\>$\emptyset\emptyset$ $\emptyset\emptyset$ (IRQ)\\
\end{tabbing}

\end{document}

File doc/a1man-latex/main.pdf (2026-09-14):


# APPLE-1

# OPERATION MANUAL

### APPLE COMPUTER COMPANY

### 770 Welch Road

### Palo Alto, California 94304

SPECIFICATIONS

MICROPROCESSOR: | MOS Technology 6502
Microprocessor Clock Frequency: | 1.023 MHz
Effective Cycle Frequency: | 0.960 Mhz
(Including Refresh Waits)
VIDEO OUTPUT: | Composite positive video, 75 ohms, level adjustable be-
| tween zero and +5V pp.
Line Rate: | 15734 Hz
Frame Rate: | 60.06 Hz
Format | 40 characters/line, 24 lines; with automatic scrolling
Display Memory: | Dynamic shift registers (1K x 7)
Character Matrix: | 5 x 7

INTRODUCTION

The Apple Computer is a complete microprocessor system, consisting of a Mos Technology 6502 microprocessor and support hardware, integral video display electronics, dynamic memory and refresh hardware, and fully regulated power supplies. It contains resident system monitor software, enabling the user, via the keyboard and display, to write, examine, debug, and run programs efficiently; thus being an educational tool for the learning of microprocessor programming, and an aid in the development of software.

The integral video display section and the keyboard interface renders unnecessary the need for an external teletype. The display section contains its ownmemory, leaving all of RAM for user programs, and the output format is 40 characters/ line, 24 lines/page, with auto scrolling. Almost any ASCII encoded keyboard will interface directly with the Apple system.

The board has sockets for upto 8K bytes of the 16 pin, 4K type, RAM, and the system is fully expandable to 65K via the edge connector. The system uses dynamic memory (4K bytes supplied), although static memory may also be used. All refreshing of dynamic memory, including all ”off-board’” expansion memory, is done automatically. The entire system timing, including the microprocessor clock and all video signals, originates in a single crystal oscillator.

Further, the printed circuit board contains a ”breadboard area”, in which the user can add additional ”on-board” hardware (for example, extra PIA’s, ACIA’s, EROM’s, and so on).

This manual is divided into three Sections:

Section I GETTING THE SYSTEM RUNNING

Section II USING THE SYSTEM MONITOR. (listing included)

Section III EXPANDING THE SYSTEM.

Please read Section I thoroughly, before attempting to ”power-up” your system, and study Section III carefully before attempting to expand your system. In addition to this manual, Apple ’Tech Notes” are available which contain examples of expansion hardware and techniques.

SECTION I
GETTING THE SYSTEM RUNNING

The Apple Computer is fully assembled, tested, and burned in. The only external devices necessary for operation of the system are: An ASCII encoded keyboard, a video display monitor, and AC power sources of 8 to 10 Volts (RMS) @3 amps and 28Volts(RMS)@1 amp. The following three articles describe the attachment of these devices in detail.

Keyboard:

Any ASCII encoded keyboard, with positive DATA outputs, interfaces directly with the Apple system via a ”DIP” connector, If your keyboard has negative logic DATA outputs (rare), you can install inverters (7404) in the breadboard area. The strobe can be either positive or negative, of long or short duration. The ’DIP” keyboard connector (B4) has inputs for seven DATA lines, one STROBE line, and two normally-open pushbutton switches, used for RE-SET (enter monitor), and CLEAR SCREEN (see schematic diagram, sheet 3 of 3, for exact circuitry). This keyboard

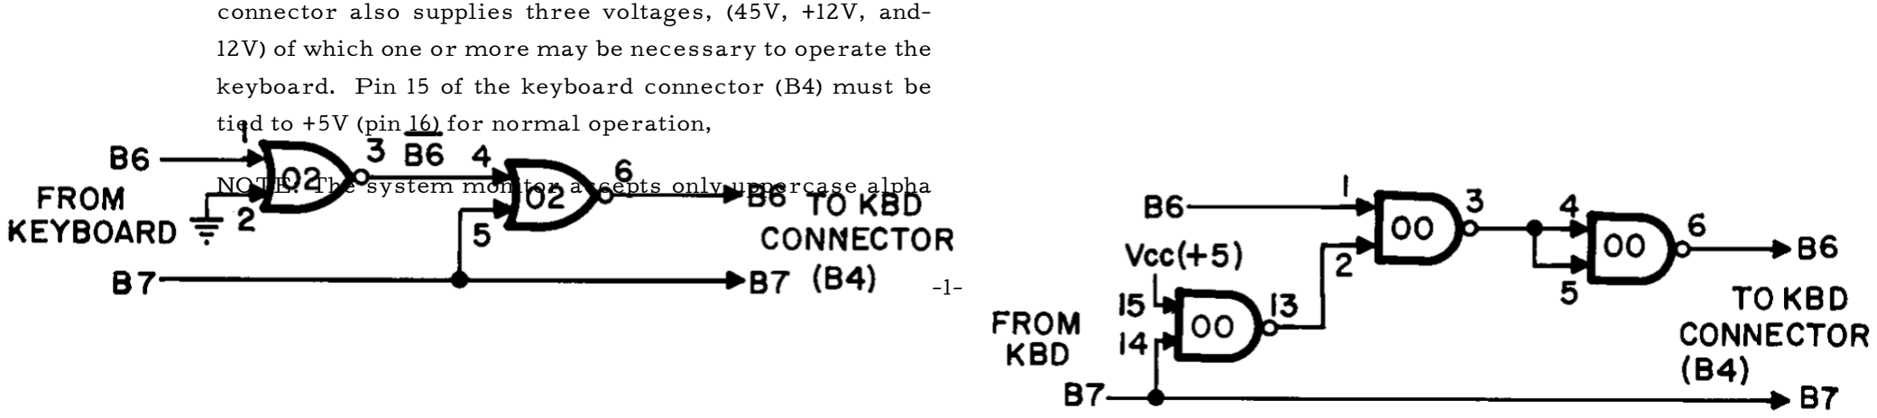
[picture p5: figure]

connector also supplies three voltages, (45V, +12V, and-12V) of which one or more may be necessary to operate the keyboard. Pin 15 of the keyboard connector (B4) must be tied to +5V (pin 16) for normal operation,

NOTE: The system monitor accepts only uppercase alpha

(A-F, R).

It is therefore convenient, though it’s not essential, to have akeyboard equipped with uppercase alpha lock (usually in the electronics). Either of the following suggested circuits may be used to provide alpha lock capability, if needed, and can be built in the breadboard area.

Display:

The Apple Computer outputs a composite video signal (composite of sync and video information) which can be applied to any standard raster-scan type video display monitor. The output level is adjustable with the potentiometer located near the video output Molex connector, J2. The additional two outside pins on the Molex connector supply +5and+l2 volts, to be used in future Apple accessories. The composite video signal can also be modulated atthe proper RF frequency, with an inexpensive commercially available device, and applied to the antenna terminals of a home television receiver. Since the character format is 40 characters /line, all television receivers will have the necessary bandwidth to display the entire 40 characters. Two large manufacturers of video display monitors, which connect directly with the Apple Computer, are Motorola and Ball. The mating four-pin Molex connector is provided.

AC Power Sources:

Two incoming AC power sources are required for operation: 8tol0 VAC (RMS) at 3 amps, and 28VAC(RMS) Center-Tapped at lamp. These AC supplies enter the system at the Molex connector, Jil. The 8tol0 volts AC provides the raw AC for the +5 volt supply, while the 28 VCT supplies the raw AC for the +12 and -12 volt supplies, and the -5V supply is derived from the -12V regulated output.

The board, as supplied, requires no more than 1.5 amps DC from the 45V supply, while the regulator is capable of supplying 3 amps. The remaining 1.5 amps DC from the 45V supply is available for user hardware expansion (provided suitable transformer ratings are employed).

A suitable source of the raw AC voltages required, are two commercially available trans— formers; Stancor P/N P-8380 or equivalent (8 to 10 volts at 3 amps), and Stancor P/N P-8667 or

equivalent (28VCT at 1 amp). Simply wire the secondaries tothe mating six pin Molex connector supplied, and wire the primaries in parallel, as shown in the schematic diagram (power supply section, Dwg.No. 00101, sheet 3 of 3.

TEST PROGRAM

After attaching the keyboard, display, and AC power sources, you can try a simple program to test if your system and the attachments are functioning together properly. While it does not test many possible areas of the microprocessor system, the test program will test for the correct attachment of the keyboard, display, and power supplies.

FIRST:

Hit the RESET button to enter the system monitor. A backslash shouldbe displayed, andthecursor shoulddroptothe nextline,

SECOND:

Type- ∅:A9b∅ bAAK2∅bEFbDFF bd E8 b 8A b4C b2b∅ (RET)

(∅ is a zero, NOT an alpha ”””O”; b means blank or

space; and (RET) hit the ”return!” key on the keyboard)

THIRD:

Type- ∅.A(RET)

(This should print out, on the display, the program you have just entered,)

FOURTH: Type- R(RET) (R means run the program.)

THE PROGRAM SHOULD THEN PRINT OUT ON THE DISPLAY A CONTINUOUS STREAM OF ASCII CHAR-ACTERS, TO STOP THE PROGRAM AND RETURNTOTHE SYSTEM MONITOR, HIT THE ”RESET” BUTTON. TO RUN AGAIN, TYPE: R (RET).

SECTION II USING THE SYSTEM MONITOR

The Hex Monitor is a PROM program in locations FF∅∅ to FFFF (hex) which uses the keyboardand display

to perform the front panel functions of examining memory, and running programs. The monitor program is entered by hitting (RESET), which displays backslash-return. A backslash alone (cursor remains on same line as backslash) indicates bad page 0 RAM.

Commands are typed on a ”line-at-a-time” basis with editing. Each line may consist of any number of commands (up to l28 characters). None are executed until (RE-TURN) is typed. The (SHIFT-0) (backarrow) backspaces and echos an underline. The (ESC) cnacels a line and echos backslash-return.

One or more hexadecimal digits (0-9, A-F) are used for address and data values. Addresses use the four least significant digits of a group, and data values, the two least significant digits. The following examples illustrate the variety of acceptable commands:

1. Opening a location (examining the contents of a single address).

USER TYPES/ 4F (RET)

MONITOR TYPES/ ∅∅4F: ∅F (contents of 4F)

2. Examining a block; fromthe last examined location, to a specified one.

USER TYPES/ .5A (RET)

MONITOR TYPES/ ∅∅5∅: ∅∅ ∅1 ∅2 ∅3 ∅4 ∅5 ∅6 ∅7 ∅∅58: ∅8 ∅9 ∅A

Note: 4F is still considered the most recently opened location.

3. Combining examples 1 and 2 to print a block of memory in a single command.

USER TYPES/ 4F,5A (RET)

MONITOR TYPES ∅∅5∅: ∅∅ ∅1 ∅2 ∅3 ∅4 ∅5 ∅6 ∅7 ∅∅58: ∅8 ∅9 ∅A

Note: Only the first location of the block (4F) is considered ”opened!”.

4. Examining several individual locations at once.

USER TYPES/ AF b 52 b 56 (RET)

MONITOR TYPES/ ∅∅4F: ∅F ∅∅52: ∅2 ∅∅56: ∅6

Note:

56 is considered the most recently ”opened” location. The ’b’ is a blank or comma, and is a delimiter for separation purposes only. A string of delimiters has the same effect as a single one (bbb is as effective as b).

5. Examining several blocks of memory at once.

USER TYPES/ 4F. 52 b 56 b 58.5A (RET)

MONITOR TYPES/ ∅∅4F: ∅F

∅∅52: ∅2

∅∅56: ∅6

∅∅58: ∅8 ∅9 ∅5A: ∅A

Note: 58is considered the most recently opened” location. Refer to example 2.

6. Examining successive blocks.

USER TYPES/ 4F.52 (RET)

MONITOR TYPES/ ∅∅4F: ∅F ∅∅5∅: ∅∅ ∅1 ∅2

USER TYPES/ .55 (RET)

MONITOR TYPES/ ∅∅53: ∅3 ∅4 ∅5

USER TYPES/ .5A (RET)

MONITOR TYPES/ ∅∅56: ∅6 ∅7

∅∅58: ∅8 ∅9 ∅A

7. Depositing data in a single location.

USER TYPES/ 3∅: A∅ (RET)

MONITOR TYPES/ ∅∅3∅: FF (prior contents)

Location 39 is considered opened and now contains 39.

8. Depositing data in successive locations from that last used in a deposit command.

USER TYPES/ : Al b A2 b A3 b A4

b A5 (RET)

(This deposits Al in location 31, A2 in 32, and so on.)

9. Combining examples 7 and 8 in a single command.

USER TYPES/ 3∅: A∅ b Al b A2 b

A3 b A4 b A5 (RET)

MONITOR TYPES/

∅∅3∅: FF (prior contents of location 3∅)

10. Depositing data in successive locations with separate commands.

USER TYPES/ 3∅: A∅ b A1 (RET) MONITOR TYPES/ ∅∅3∅: FF USER TYPES/ :A2 b A3 (RET) USER

TYPES/ :A4 b A5 (RET)

Note: A colon in a command means ”start depositing data from the most recently deposited location, or if none, then from the most recently opened one.

11. Examining a block, then depositing into it.

USER TYPES/ 30.35 (RET)

MONITOR TYPES/

∅∅3∅: A∅ Al A2 A3 A4 A5 A6

USER TYPES/

:B0 b B1 b B2 b B3 b B4 b B5 (RET)

Note: New data deposited beginning at most recently opened location (39)

12. Run a program at a specified address.

USER TYPES/ 1∅F∅ R (RET)

MONITOR TYPES/ 1∅F∅: A9 (contents)

Note: The cursor is left immediately to the right of the ’A9”’; it is not returned to the next line.

13. Run atthe most recently examined location.

USER TYPES/ 1∅F∅ (RET)

MONITOR TYPES/ 1∅F∅: A9

USER TYPES/ R (RET)

14. Enter a program into memory and run it in one line.

USER TYPES/ 4∅: A9 b ∅ b 2∅ b EF b FF b 38 b 69 b

MONITOR TYPES/ 4∅: FF (prior contents of 4∅) MONITOR TYPES/ 4∅: FF (prior contents of 4∅)

15. An ”on line” error correction.

USER TYPES/

4∅: Al b A2 b A3A4A5A6 b A7

(data A6 will be loaded in location 42)

USER TYPES/ 4∅5∅6∅7∅: AA

(data AA will be loaded in location 6∅7∅)

16. Useful routines in monitor which can be accessed by

user programs.

GETLINE: location FF1F:

monitor entry point

(jumping to FF1F will enter monitor and echo carriage return. You can then examine memory locations with the monitor.)

ECHO: location FFEF:

prints one byte (ASCII)

(data from ”A” (accumulator), contents of ”A” not disturbed. Example:

2∅ b EF b FF (JRS ECHO)).

PRBYTE: location FFDC:

prints one byte (HEX)

(data from ”A”, contents of ”A” disturbed.)

PRHEX: location FFES5:

rints one hex digit

(data from four least significant bits of ”A”, contents of ”A” disturbed.)

NOTE: Capital letters enclosed in parenthesis represent single keystrokes. Example: (RET) means hit the ”return” key

NOTE: RAM locations ∅∅24 to ∅∅2B are used as index pointers by the monitor, and are invalid for user use, when using monitor. Also, locations ∅∅2∅ to ∅27F are used as input buffer storage, and are also invalid for user use when using the

monitor.

65∅2 HEX MONITOR LISTING

FF∅∅ D8 | RESET | CLD | Clear Decimal arithmetic mode
FF∅1 | 58 | | CLI
FF∅2 | A∅ 7F | | LDY #$7F | Mask for DSP data direction register
FF∅4 | 8C 12 D∅ | | STY DSP | Set it up
FF∅7 | A9 A7 | | LDA #$A7 | KBD and DSP control register mask
FF∅9 | 8D 11 D∅ | | STA KBD CR | Enable interrupts, set CA1, CB1, for
FF∅C | 8D 11 D∅ | | STA DSP CR | positive edge sense/output mode
FF∅F | 8D 13 D∅ | NOTOR | CMP #$DF | ”⇐”?
FF11 | F∅ 13 | | BEQ BACKSPACE | Yes.
FF13 | C9 9B | | CMP #$9B | ESC?
FF15 | F∅ 03 | | BEQ ESCAPE | Yes.
FF17 | C8 | | INY | Advance text index.
FF18 | 1∅ ∅F | | BPL NEXTCHAR | Auto ESC if > 127.
FF1A | A9 DC | ESCAPE | LDA #$DC | ”\”.
FF1C | 20 EF FF | | JSR ECHO | Output it.
FF1F | A9 8D | GETLINE | LDY #$∅1 | CR.
FF21 | 2∅ EF FF | | JSR ECHO | Output it.
FF24 | A∅ ∅1 | | LDY #$∅1 | Initialize text index.
FF26 | 88 | BACKSPACE | DEY | Back up text index.
FF27 | 3∅ F6 | | BMI GETLINE | Beyond start of line, reinitialize.
FF29 | AD 11 D∅ | NEXTCHAR | LDA KBD CR | Key ready?
FF2C | 1∅ FB | | BPL NEXTCHAR | Loop until ready.
FF2E | AD 1∅ D∅ | | LDA KBD | Load Character. B7 should be ’1’.
FF31 | 99 ∅∅ ∅2 | | STA IN, Y | Add to text buffer.
FF34 | 2∅ EF FF | | JSR ECHO | Display character.
FF37 | C9 8D | | CMP #$8D | CR?
FF39 | D∅ D4 | | BNE NOTOR | No.
FF3B | A∅ FF | | LDY #$FF | Reset text index.
FF3D | A∅ FF | | LDA #$∅∅ | For XAM mode.
FF3F | AA | | TAX | ∅ → X
FR4∅ ∅A | SETSTOR | ASL | Leaves $7B if setting STOR mode.
FF41 | 85 2B | SETMODE | STA MODE | $∅∅ = XAM, $7B = STOR, $AE = BLOK XAM.
FF43 | C8 | BLSKIP | INY | Advance text index.
FR44 | B9 ∅∅ ∅2 | NEXT ITEM | LDA IN, Y | Get character.
FF47 | C9 8D | | CMP #$8D | CR?
FF49 | F∅ D | | BEQ GETLINE | Yes, done this line.
FF4B | C9 AE | | CMP #$AE | ”.”?
FF4D | 9∅ F4 | | BCC BLSKIP | Skip delimiter.
FF4F | F∅ F∅ | | BEQ SETMODE | Set BLOCK XAM mode.
FF51 | C9 BA | | CMP #$BA | ”:”?
FF53 | F∅ EB | | BEQ SETSTOR | Yes, set STOR mode.
FF55 | C9 D2 | | CMP #$D2 | ”R”?
FF57 | F∅ 3B | | BEQ RUN | Yes, run user program.
FF59 | 86 28 | | STX L | $∅∅ →L.
FF5B | 86 29 | | STX H | and H.
FF5D | 84 2A | | STY YSAV | Save Y for comparison.
FF5F | B9 ∅∅ ∅2 | NEXTHEX | LDA IN, Y | Get character for hex test.
FF62 | 49 B∅ | | EOR #$B∅ | Map digits to $∅-9.
FF64 | C9 0∅ | | CMP #$∅A | Digit?
FF66 | 9∅ ∅6 | | BCC DIG | Yes.
FF68 | 69 88 | | ADC #$88 | Map letter ”A”-”F” to $FA-FF.
FF6A | C9 FA | | CMP #$FA | Hex letter?

FF6C | 9∅ 11 | | BCC NOTHEX | No, character not hex.
FF6E | ∅A | DIG | ASL
FF6F | ∅A | | ASL | Hex digit of MSD of A.
FF7∅ ∅A | ASL
FF71 | ∅A | | ASL
FF72 | A2 ∅4 | | LDX #$∅4 | Shift count.
FF74 | ∅A | HEXSHIFT | ASL | Hex digit left, MSB to carry
FF75 | 26 28 | | ROL L | Rotate into LSD.
FF77 | 26 29 | | ROL H | Rotate into MSD’s.
FF79 | CA | | DEX | Done 4 shifts?
FF7A | D∅ F8 | | BNE HEXSHIFT | No, loop.
FF7C | C8 | | INY | Advance text index.
FF7D | D∅ E∅ | | BNE NEXTHEX | Always taken. Check next character for hex.
FF7F | C4 2A | NOTHEX | CPY YSAV | Check if L, H empty (no hex digits).
FF81 | F∅ 97 | | BEQ ESCAPE | Tes, generate ESC sequence.
FF83 | 24 2B | | BITMODE | Test MODE byte.
FF85 | 5∅ 1∅ | | BVC NOTSTOR | B6 = ∅ for STOR, 1 for XAM and BLOCK XAM
FF87 | A5 28 | | LDA L | LSD’s of hex data.
FF89 | 81 26 | | STA (STL, X) | Store at current ’store index’.
FF8B | E6 26 | | INC STL | Increment Store index.
FF8D | D∅ B5 | | BNE NEXTITEM | Get next item (no carry).
FF8F | E6 27 | | INC STH | Add carry to ’store index’ high order.
FF91 | 4C 44 FF | TONEXTITEM JMP NEXTITEM | Get next command item.
FF94 | 6C 24 ∅∅ | RUN | JMP (XAML) | Run at current XAM index.
FF97 | 3∅ 2B | NOTSTOR | BMI XAMNEXT | B7 = ∅ for XAM, 1 for BLOCK XAM.
FF99 | A2 ∅2 | | LDX #$∅2 | Byte count.
FF9B | B5 27 | SETADR | LDA L-1, X | Copy hex data to
FF9D | 95 25 | | STA ST; -1, X | ’store index’.
FF9F | 95 23 | | STA XAML-1, X | And to ’XAM index’
FFA1 | CA | | DEX | Next 2 bytes.
FFA2 | D∅ F7 | | BNE SETADR | Loop unless X = ∅.
FFA4 | D∅ 14 | NXTPRNT | BNE PRDATA | NE means no address to print.
FFA6 | A9 8D | | LDA #$8D | CR.
FFA8 | 2∅ EF FF | | JSR ECHO | Output it.
FFAB | A5 25 | | LDA XAMH | ’Examine index’ high-order byte.
FFAD | 2∅ DC FF | | JSR PRBYTE | Output it in hex format.
FFB∅ A5 24 | LDA XAML | Low-order ’examine index’ byte.
FFB2 | 2∅ DC FF | | JSR PRBYTE | Output it in hex format.
FFB5 | A9 BA | | LDA #$BA | ”:”.
FFB7 | 2∅ EF FF | | JSR ECHO | Output it.
FFBA | A5 24 | PRDATA | LDA #$A∅ | Blank.
FFBC | 2∅ EF FF | | JSR ECHO | Output it.
FFBF | A1 24 | | LDA (XAML, X) | Get data byte at ’examine index’.
FFC1 | 2∅ DC FF | | JSR PRBYTE | Output it in hex format.
FFC4 | 86 2B | XAMNEXT | STX MODE | ∅ →MODE (XAM mode).
FFC7 | A5 24 | | LDA XAML
FFC8 | C5 28 | | CMP L | Compare ’examine index’ to hex data.
FFCA | A5 25 | | LDA XAMH
FFCC | E5 29 | | SBC H
FFCE | B∅ C1 | | BCS TONEXTITEM | Not less, so no more data to output.
FFD∅ E6 24 | INC XAML
FFD2 | D∅ ∅2 | | BNE MOD8CHK | Increment ’examine index’.
FFD4 | E6 25 | | INC XAMH
FFD6 | A5 24 | MOD8CHK | LDA XAML | Check low-order ’examine index’ byte

FFD8 | 29 ∅7 | | AND #$∅7 | For MOD 8= ∅
FFDA | 1∅ C8 | | BPL NXTPRNT | Always taken.
FFDC | 48 | PRBYTE | PHA | Save A for LSD.
FFDD | 4AA | | LSR
FFDE | 4A | | LSR
FFDF | 4A | | LSR | MSD to LSD position.
FFE∅ 4A | LSR
FFE1 | 2∅ E5 FF | | JSR PRHEX | Output hex digit.
FFE4 | 68 | | PLA | Restore A
FFE5 | 29 ∅F | PRHEX | AND #$∅F | Mask LSD for hex print
FFE7 | ∅9 B∅ | | ORA #$B∅ | add ”∅”.
FFE9 | C9 BA | | CMP #$BA | Digit?
FFEB | 9∅ ∅2 | | BCC ECHO | Yes, output it.
FFED | 69 ∅6 | | ADC #$∅6 | Add offset for letter.
FFEF | 2C 12 D∅ | ECHO | BIT DSP | DA bit (B7) cleared yet?
FFF2 | 3∅ FB | | BMI ECHO | No, wait for display.
FFF4 | 8D 12 D∅ | | STA DSP | Ooutput character. Sets DA.
FFF7 | 6∅ | | RTS | Return
FFF8 | ∅∅ ∅∅ (unused)
FFFA | ∅∅ ∅F (NMI)
FFFC | ∅∅ FF (RESET)
FFFE | ∅∅ ∅∅ (IRQ)

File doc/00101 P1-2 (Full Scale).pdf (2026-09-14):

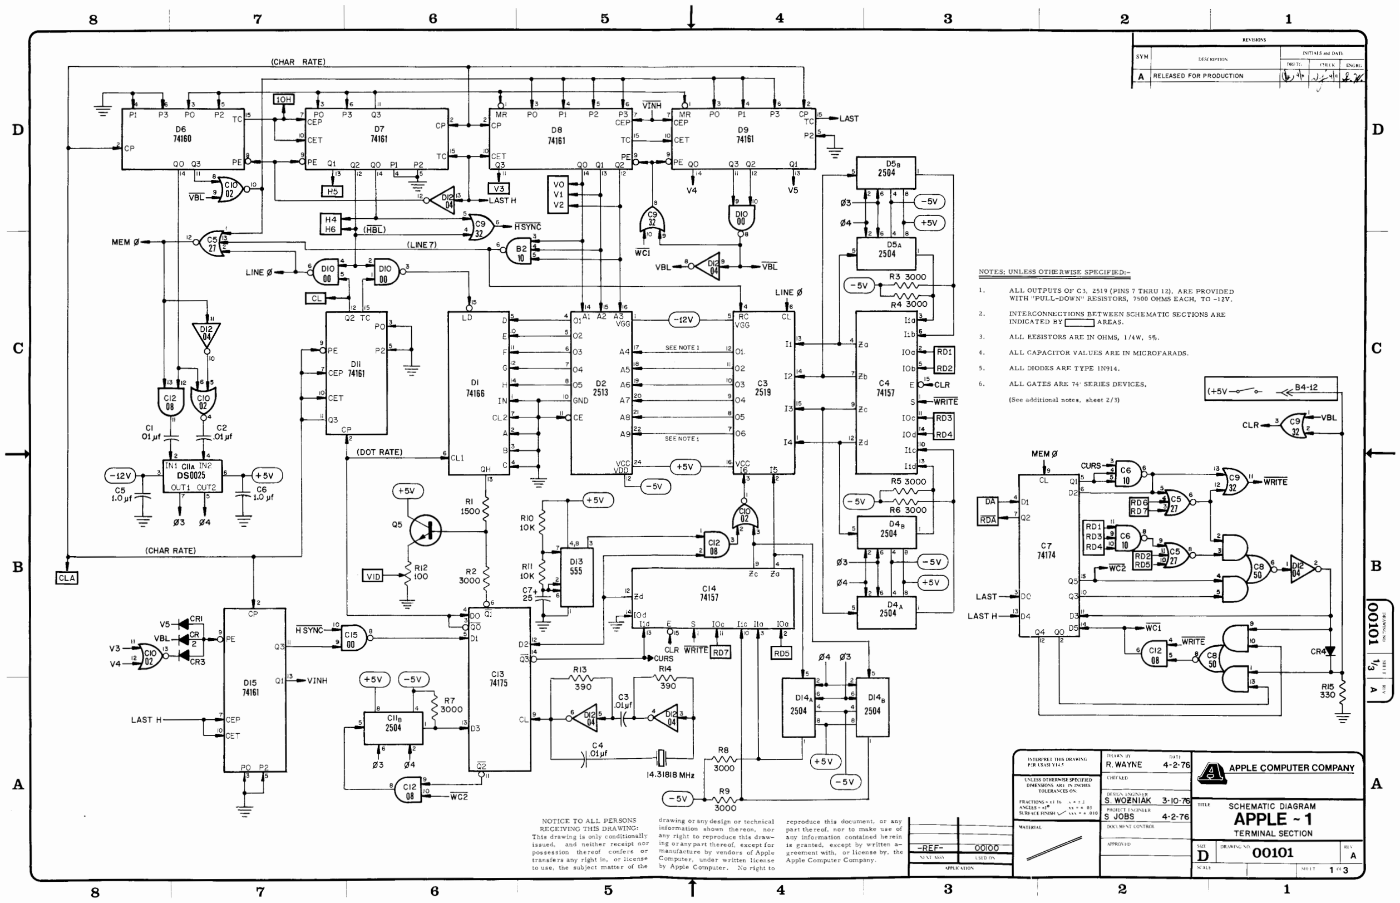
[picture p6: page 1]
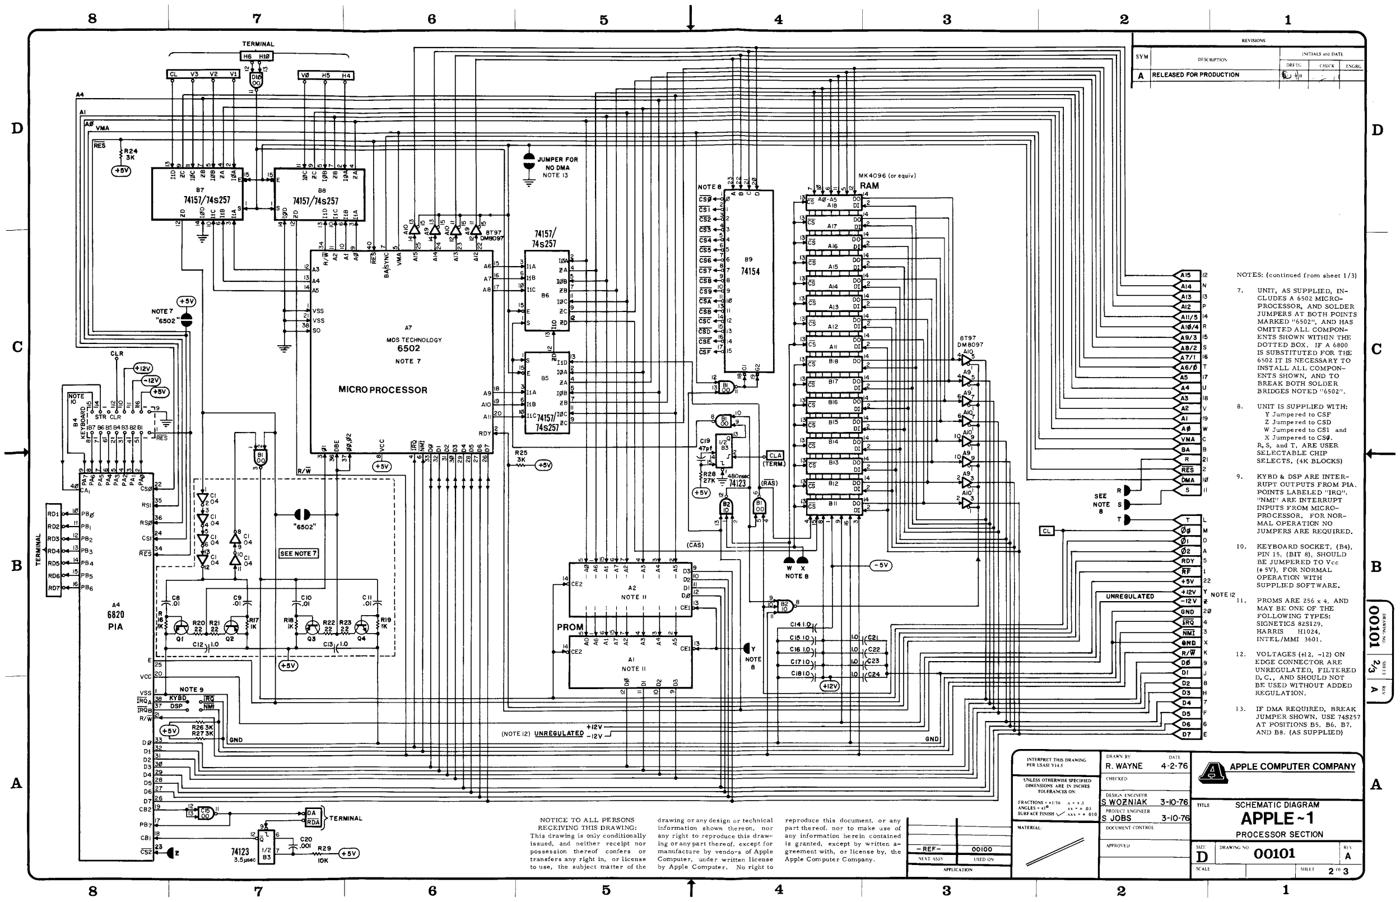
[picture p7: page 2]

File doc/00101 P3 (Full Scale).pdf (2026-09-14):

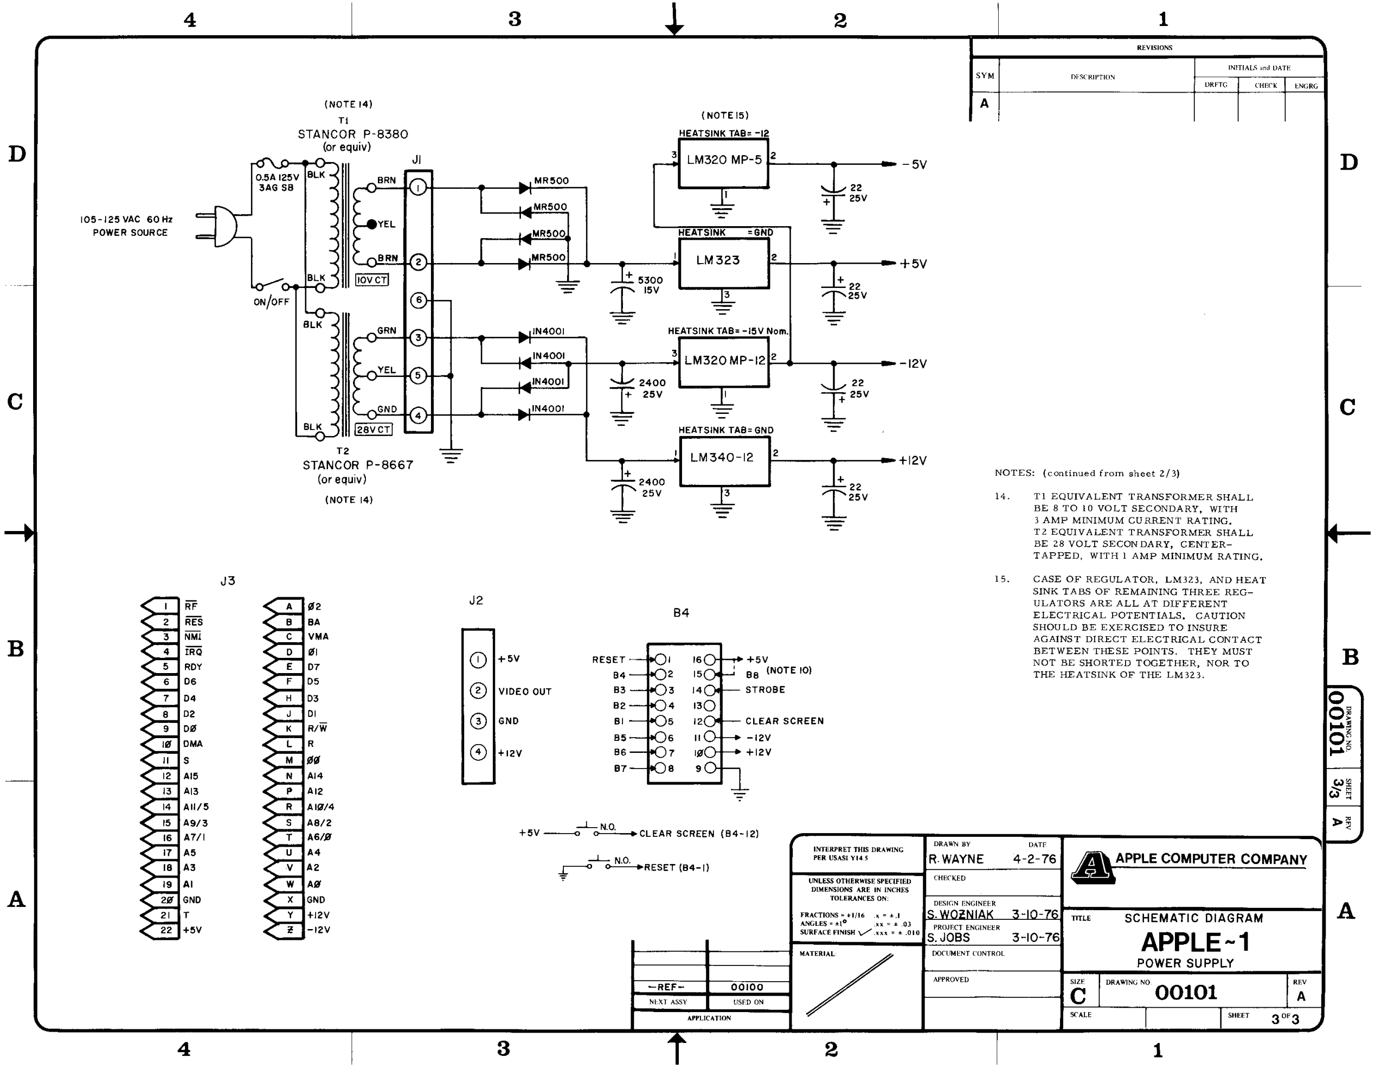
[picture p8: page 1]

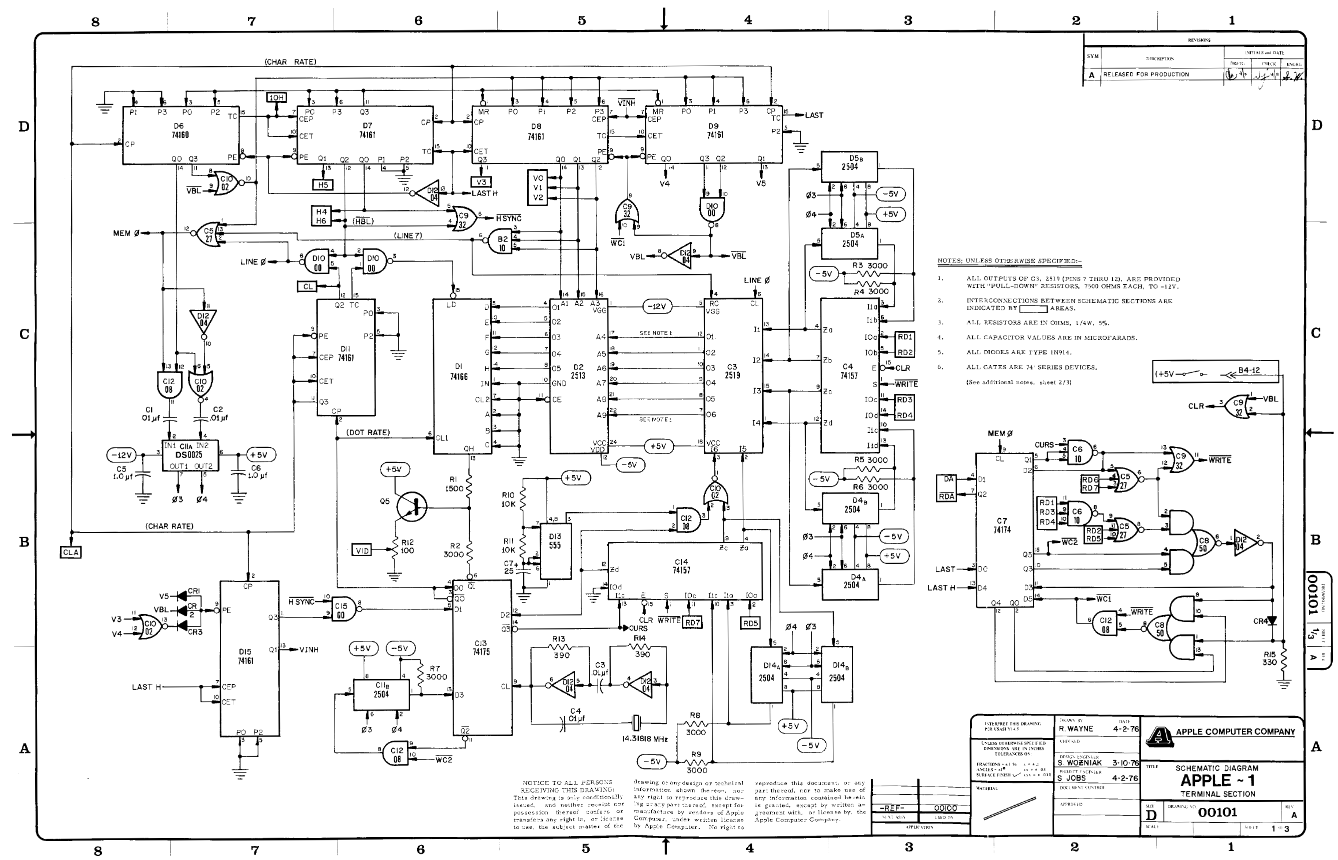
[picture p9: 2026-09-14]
img/00101P3.png

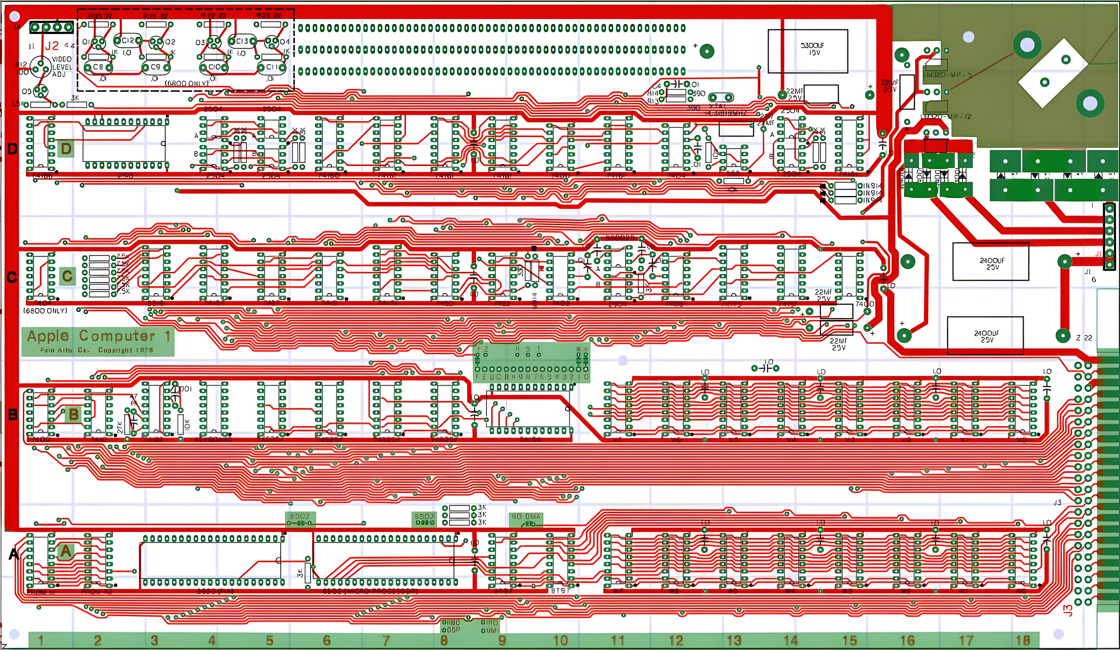
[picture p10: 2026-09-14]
img/mimieo-prepro-overlay-upscaled.png

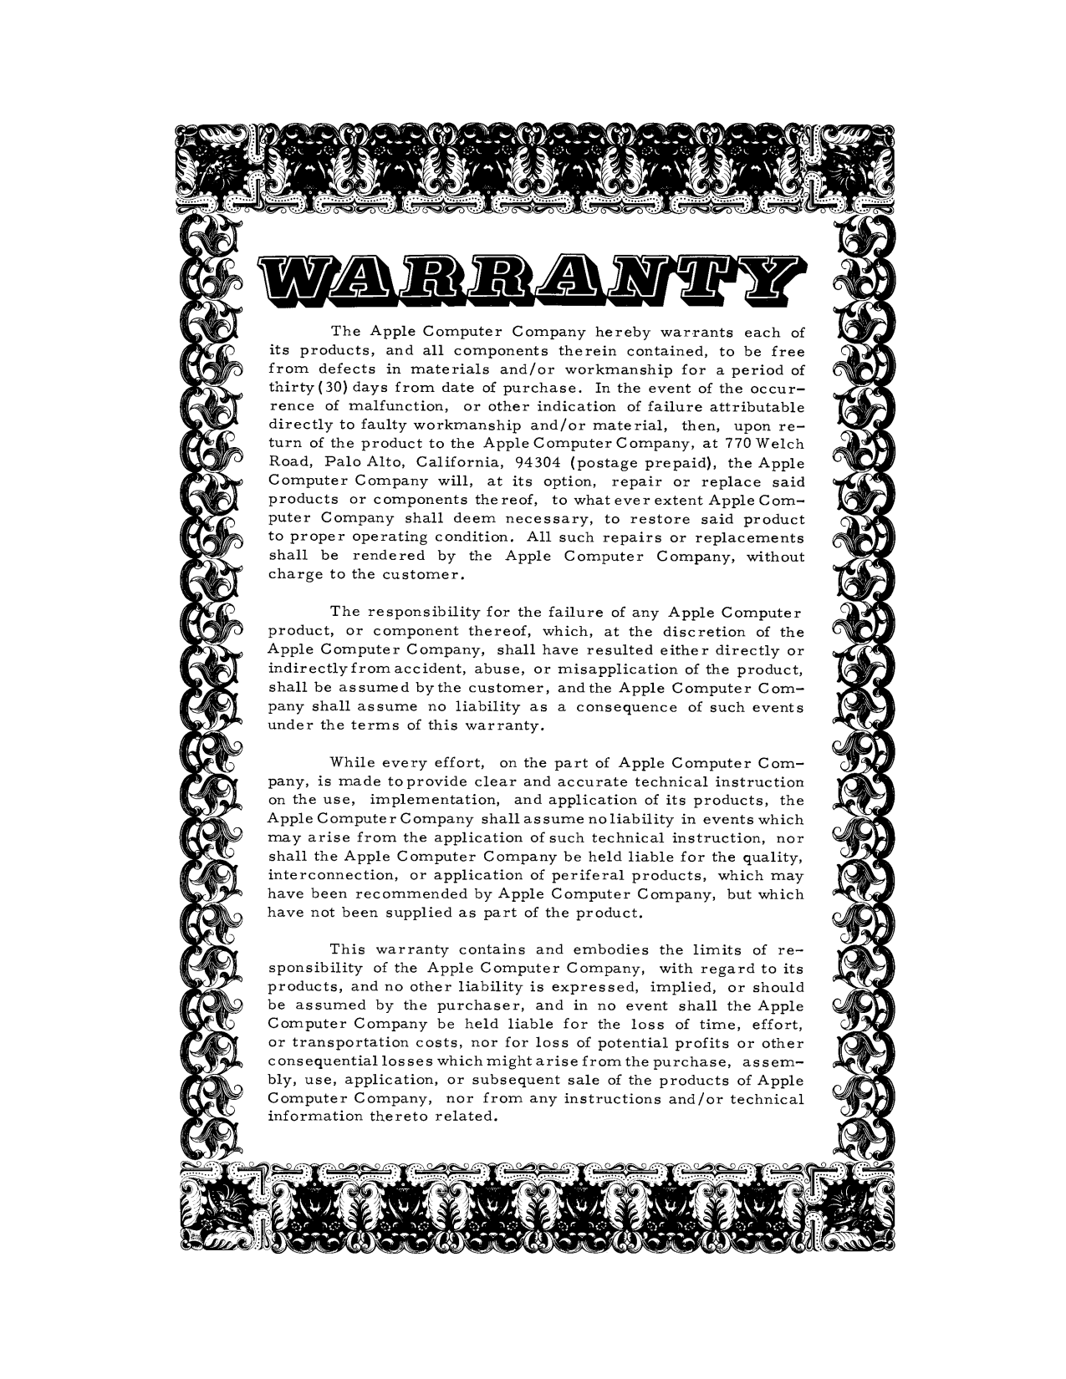
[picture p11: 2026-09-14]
doc/a1man-latex/pages/a1man_pages-13.png

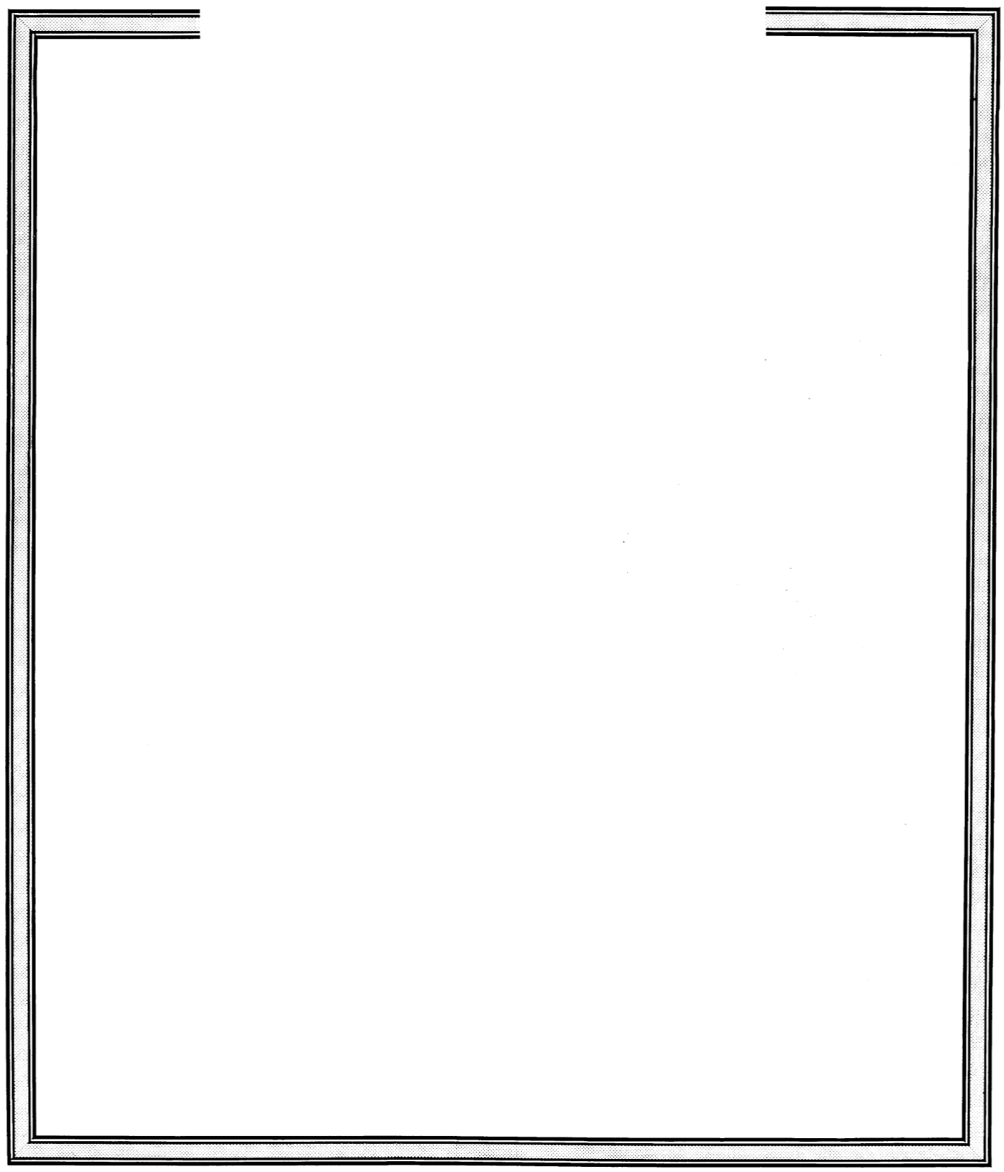
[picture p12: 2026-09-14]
doc/a1man-latex/pages/titleborder.png

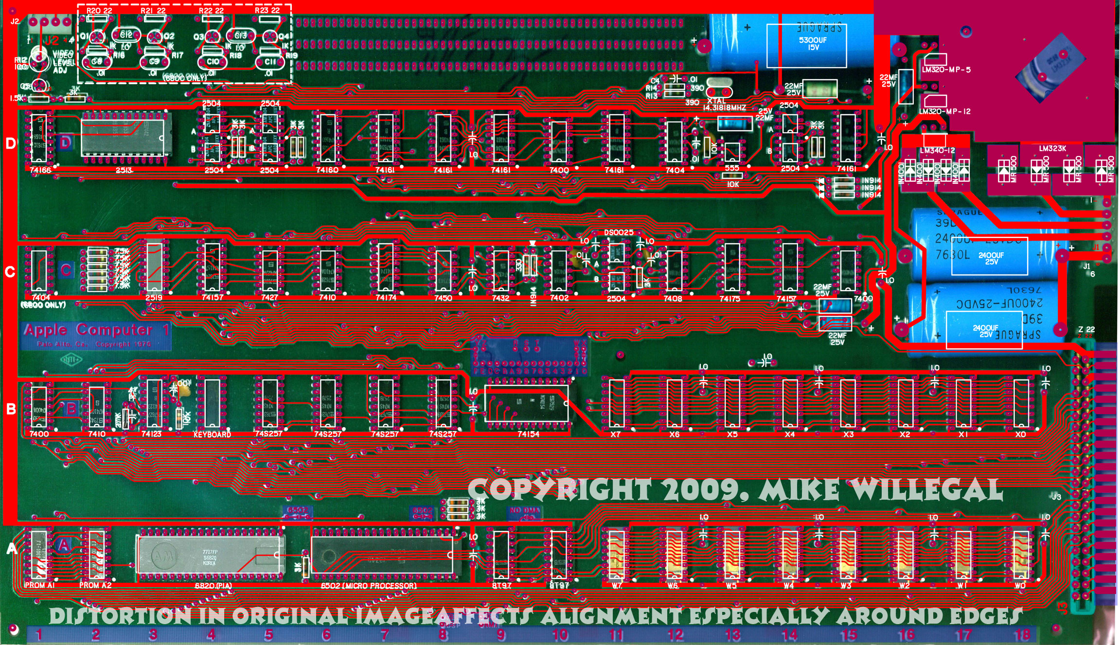
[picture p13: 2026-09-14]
img/mimeo-overlay.jpg

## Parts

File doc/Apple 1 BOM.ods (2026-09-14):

Ref | Part | Part | Qty | Alt. Part | Remarks
NA | Transformer | Stancor P-8667 | 1 | Triad F40-X
NA | Transformer | Stancor P-8380 | 1 | Triad F31-X
NA | power connector |  | 1
NA | Heatsink | Wakefield 680-125A | 1 |  | Mouser
NA | +5V voltage regulator (3AMP) | LM323K | 1 | PSU5 | Mouser
NA | LM323 mounting kit |  | 1
NA | DIP-8 Socket |  | 1 | 3M 4008-3004-CP | Mouser
NA | DIP-16 Socket |  | 42 | 3M 4816-3004-CP | Mouser
NA | DIP-14 Socket |  | 12 | 3M 4814-3004-CP | Mouser
NA | DIP-24 Socket |  | 2 | 3M 4824-6004-CP | Mouser
NA | DIP-40 Socket |  | 2 | 3M 4840-6004-CP | Mouser
NA | keyboard |  | 1
NA | video connector |  | 1
 | -5V Voltage Regulator | LM320MP-5.0 | 1 | LM7905CT/NOPB | Mouser
 | -12V Voltage Regulator | LM320MP-12.0 | 1 | LM7912CT/NOPB | Mouser
 | +12V Voltage Regulator | LM340MP-12.0 | 1 | LM7812CT/NOPB | Mouser
 | Timer | NE555P | 1 |  | Mouser
 | Transistor | MPS3704 PBFREE | 1 |  | Mouser
 | Diode | 1N4001 | 4 |  | Mouser
 | Diode | 1N914 | 4 |  | Mouser
 | Diode | MR500 DO-27 package | 4 | A14F
 | 8T97 |  | 2
A1,A2 | Intel/MMI 3601 256x4 prom |  | 2
 | Character Generator | Signetcs 2513 | 1 |  | Hard to find
 | Shift Register | Signetics 2504V | 7 | National Semiconductor MM1404 | Hard to find
 | Shift Register | Signetics 2519B | 1 |  | Hard to find
A4 | Moto 6820 |  | 1 | 6520
 | Two Phase MOS Clock Driver | DS0025C | 1
 | CPU | Mostek 6502 | 1
C15,B1 | Logic Gates Quad 2-Input | TTL 7400 | 3 | SN7400N | Mouser
C10 | Logic Gates Quad 2-Input Positive-NOR Gates | TTL 7402 | 1 | SN7402N | Mouser
C1,D12 | Hex Inverter | TTL 7404 | 1 | SN7404N | Mouser
C12 | Logic Gates Quad 2-Input | TTL 7408 | 1 | SN74LS08N | Mouser
B2,B6 | Logic Gates Triple 3-Input | TTL 7410 | 2 | SN74LS10N | Mouser
B3 | Monostable Multivibrator Dual retrig | TTL 74123 | 1 | SN74123N | Mouser
B9 | Bus Receivers Quad Line Receiver/L | TTL 74154 | 1 | SN74154N | Mouser
B5,B6,B7,B8 | Quad Data Multiplexer | TTL 74157 | 2 | SN74LS157N | Mouser
D6 | Synchronous presettable 4-bit decade counter, asynchronous clear | TTL 74160 | 1 | SN74LS160A
D7,D8,D9,D11,D15 | Counter ICs 4-Bit Synch Binary | TTL 74161 | 5 | SN74LS161AN | Mouser
D1 | Counter Shift Registers Serial-out | TTL74166 | 1 | SN74LS166AN | Mouser
C7 | Flip Flops Hex | TTL74174 | 1 | SN74LS174N | Mouser
C13 | Flip Flops Quad | TTL 74175 | 1 | SN74LS175N | Mouser
C5 | Logic Gates Triple 3-input Positive-NOR gates | TTL 7427 | 1 | SN74LS27N | Mouser
C9 | Logic Gates Quad 2-input Positive-OR gates | TTL 7432 | 1 | SN7432N | Mouser
C8 | Dual 2-2-input AND-OR-Invert gate, one gate expandable | TTL 7450 | 1 | SN7450N
 | Quad 2-to-1 Data Slc t/Mltpx W/3St Otp | TTL 74S257 | 4 | SN74F257N | Mouser
A11,A12,A13,A14,A15,A16,A17,A18,B11,B12,B13,B14,B15,B16,B17,B18 | DRAM, 4Kx1 | MK4096-11 | 16 | mk4027 200ns | Hard to find
 | Capacitor, .001uF Ceramic Disc p=.3" |  | 1 | BC2354-ND
CAP8,CAP9,CAP10,CAP11 | Capacitor, .01uF Ceramic Disc p=.3" |  | 4 | BC2361-ND
 | Capacitor, .1uF Ceramic Disc p=.3" (Marked 1.0 on board) |  | 17
CAP19 | Capacitor, 47pF mica p=.3" |  | 1
 | Capacitor, 22uF 25V Axial p=.3" |  | 5
 | Capacitor, 2400uF 25V Axial | 39D248G025JL6 | 2 |  | Mouser
 | Capacitor, 5300uF 15V Axial | 39D538G015JP6 | 1 |  | Mouser
 | Resistor, 1/4 watt 10k ohms, p=.4in |  | 3
 | Resistor, 1/4 watt 1500 ohms, p=.4in |  | 1
R3,R4,R5,R6,R7,R8,R9,R24,R25,R26,R27 | Resistor, 1/4 watt 3000 ohms, p=.4in |  | 12
 | Resistor, 1/4 watt 330 ohms, p=.4in |  | 1
 | Resistor, 1/4 watt 390 ohms, p=.4in |  | 2
 | Resistor, 1/4 watt 7.5 K, p=.4in |  | 6
R28 | Resistor, 1/4 watt 27k ohms, p=.4in |  | 1
 | Potentiometer, 100 Ohm | Spectrol 62-1-1/2-101 | 1 |  | Hard to find
J3 | Connector, Card Edge 44Px.156"x.140" |  | 1 | EDAC 304-044-520-201 | Mouser
 | Crystal -14.3181 Mhz HC49/U |  | 1 | Abracon AB-14.31818MHZ-B2 | Mouser

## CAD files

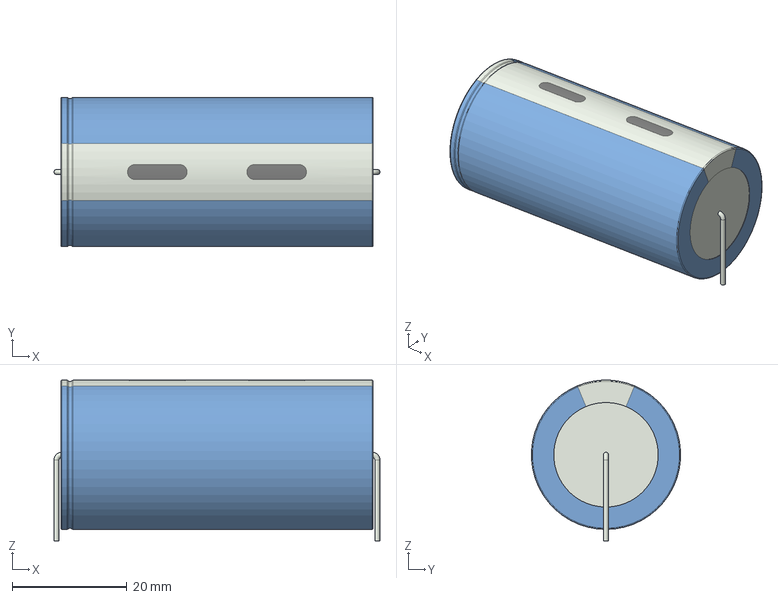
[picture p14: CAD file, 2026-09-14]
3d/CP_Axial_L54.4mm_D26.0mm_P55.88mm_Horizontal.stp
56.8 x 26.0 x 28.0 mm

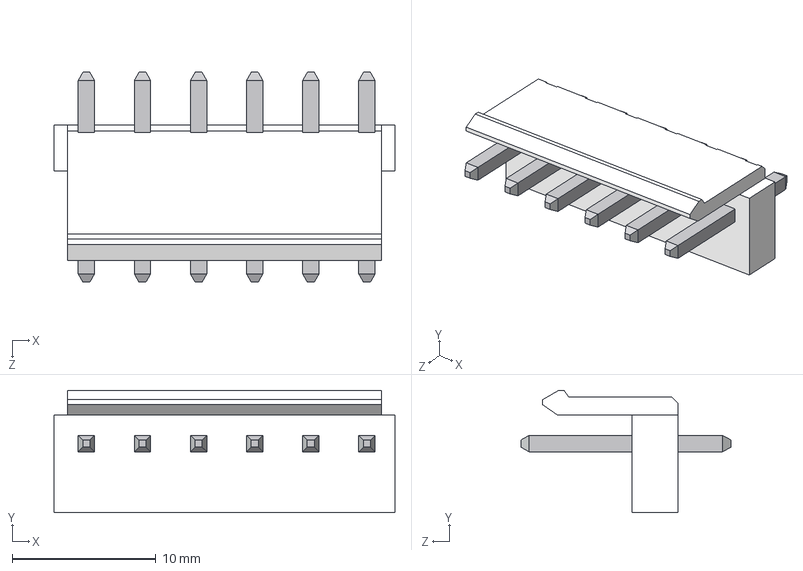
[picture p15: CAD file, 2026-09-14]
3d/JST_VH_B6P-VH_1x06_P3.96mm_Vertical.stp
23.7 x 8.50 x 14.6 mm

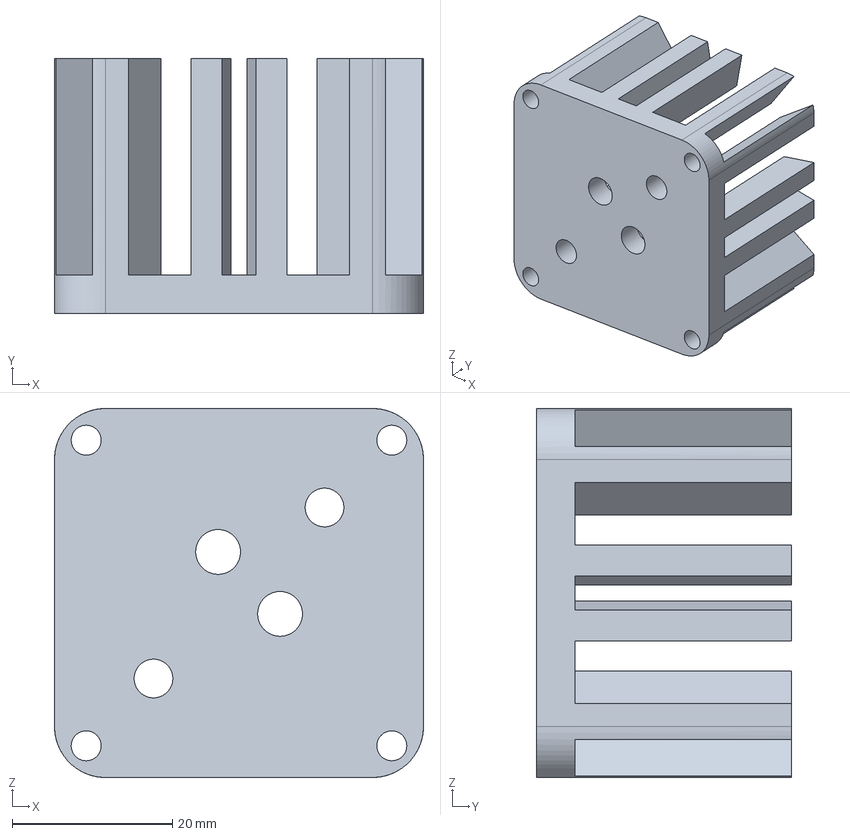
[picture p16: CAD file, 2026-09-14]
3d/680-125K.stp
46.0 x 31.8 x 46.0 mm

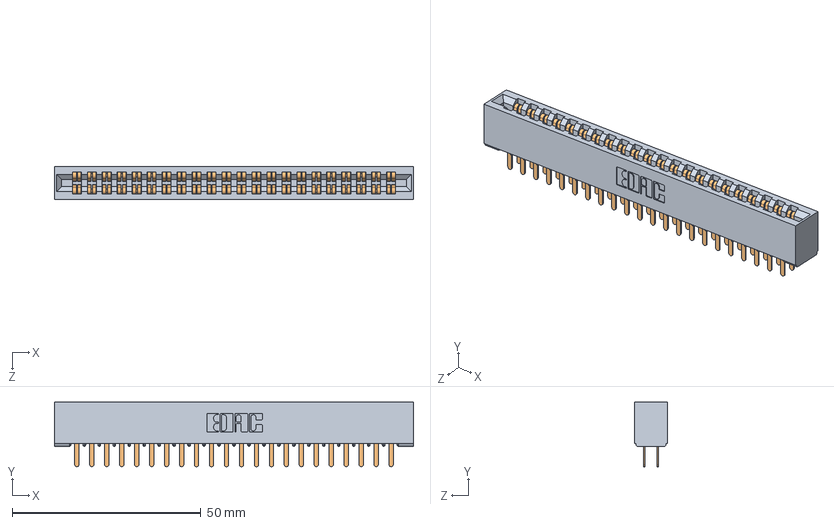
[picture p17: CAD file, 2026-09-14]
3d/305-044-520-201 - EDAC Card Edge Connector.STEP
95.0 x 17.1 x 8.71 mm
305 Part_No Mounting

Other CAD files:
d1.step
3d/680-125K.ipt
3d/CP_Axial_L54.4mm_D26.0mm_P55.88mm_Horizontal.ipt

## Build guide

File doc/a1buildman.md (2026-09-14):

# Apple 1 Clone Computer Assembly and Startup Guide

By Mike Willegal (www.willegal.net)

Compiled from revision 1.1

with Remarks from "Uncle Bernie"

Reformatted in Markdown and Edited for general projects by jgw4

## Preface

This document in large part was written long before me by Mike Willegal, and most of the instructions in this document are his and his alone. My contributions to this document include the addition of installation tips that are also not of my origination. Mostly Uncle Bernie is the source of these additions. I have also added section to the document that includes enhancements, mainly a transcription, in text form, of the locations of the extra decoupling capacitors and terminating resistors noted by hobbyists such as Uncle Bernie and others. I just want to be clear that there is not much at all in the way of original work in this document, but rather it can be considered a compilation work, giving starting hobbyists a central document to understand the length and breadth of the task set out for them.

## Safety
> [!CAUTION]
> This computer was designed by a hobbyist for hobbyists in the burgeoning new hobby of personal computing in 1976. Safety standards were nonexistent or ignored. The designer assumed that the purchaser had either electronics knowledge or a access to a group of friends that could provide this knowledge and guidance. It is strongly advised to not attempt this project if you have neither electronics knowledge or friends that can help you. Connection of the transformers to your house wiring is left to you. There are rudimentary instructions in the Apple-1 Operation Manual. If you don’t feel comfortable with this task, assume that you don’t have the qualifications to build this kit and either find some help, or return your parts.
> 
> There are many new old stock components on the market that may fail prematurely and unexpectedly. Failure modes are unpredictable and may result in sparks and fire. Do not leave this computer running without someone present to monitor operation.

## Table of Contents
- [Forward](#forward)
- [Chapter 1: Assemble Components, Tools, and Equipment](#chapter-1-assemble-components-tools-and-equipment)
  - [1. Recommended Tools and Equipment](#1-recommended-tools-and-equipment)
  - [2. Additional Components (not included)](#2-additional-components-not-included)
  - [3. Read and Understand the Apple 1 Operations Manual.](#3-read-and-understand-the-apple-1-operations-manual)
  - [4. Expansion Options (not included)](#4-expansion-options-not-included)
  - [5. Compare Components With Parts List](#5-compare-components-with-parts-list)
    - [Main Inventory](#main-inventory)
    - [Board and connectors](#board-and-connectors)
    - [Passive parts and hardware](#passive-parts-and-hardware)
- [Chapter 2: Solder In Sockets and Components](#chapter-2-solder-in-sockets-and-components)
  - [1. Remove Card Edge Connector](#1-remove-card-edge-connector)
  - [2. Check for Power and Ground Shorts](#2-check-for-power-and-ground-shorts)
  - [3. Sockets](#3-sockets)
  - [4. Solder the Two 40-Pin Sockets](#4-solder-the-two-40-pin-sockets)
  - [5. Solder the Two 24-Pin Sockets](#5-solder-the-two-24-pin-sockets)
  - [6. Solder the Forty-Two 16-Pin Sockets](#6-solder-the-forty-two-16-pin-sockets)
  - [7. Solder the Twelve 14-Pin Sockets](#7-solder-the-twelve-14-pin-sockets)
  - [8. Solder In the 8 Pin Socket](#8-solder-in-the-8-pin-socket)
  - [9. Repeat Check for Power and Ground Shorts](#9-repeat-check-for-power-and-ground-shorts)
  - [10. Solder In the 17 Decoupling Capacitors](#10-solder-in-the-17-decoupling-capacitors)
  - [11. Solder In the Remaining 6 Small Capacitors](#11-solder-in-the-remaining-6-small-capacitors)
  - [12. Repeat Check for Power and Ground Shorts](#12-repeat-check-for-power-and-ground-shorts)
  - [13. Solder In Resistors](#13-solder-in-resistors)
  - [14. Solder In Diodes](#14-solder-in-diodes)
  - [15. Solder In Medium Electrolytic Caps and Transistor](#15-solder-in-medium-electrolytic-caps-and-transistor)
  - [16. Repeat Check for Power and Ground Shorts](#16-repeat-check-for-power-and-ground-shorts)
  - [17. Solder In Power and Video Connectors](#17-solder-in-power-and-video-connectors)
  - [18. Solder In Small Voltage Regulators](#18-solder-in-small-voltage-regulators)
  - [19. Solder In Large Power-Smoothing Capacitors](#19-solder-in-large-power-smoothing-capacitors)
  - [20. Repeat Check for Power and Ground Shorts](#20-repeat-check-for-power-and-ground-shorts)
  - [21. Attach Large +5 Volt Regulator and Heat Sink](#21-attach-large-5-volt-regulator-and-heat-sink)
  - [22. Repeat Check for Power and Ground Shorts](#22-repeat-check-for-power-and-ground-shorts)
  - [23. Clean PCB of Rosin and By-products of Soldering](#23-clean-pcb-of-rosin-and-by-products-of-soldering)
  - [24. Check Board for Solder Bridges and Cold Solder Joints](#24-check-board-for-solder-bridges-and-cold-solder-joints)
- [Chapter 3: Initial Power Up](#chapter-3-initial-power-up)
  - [1. Build the Power Entry Module (PEM)](#1-build-the-power-entry-module-pem)
  - [2. Connect Power Supply and Power Up](#2-connect-power-supply-and-power-up)
  - [3. Check Voltages](#3-check-voltages)
- [Chapter 4: Bring Up The Video Section](#chapter-4-bring-up-the-video-section)
  - [1. Populate the Video Section](#1-populate-the-video-section)
  - [2. Connect a Video Display](#2-connect-a-video-display)
  - [3. Checkout Video Section](#3-checkout-video-section)
- [Chapter 5: Populate and Check out the Computer Section](#chapter-5-populate-and-check-out-the-computer-section)
  - [1. Populate the Computer Section](#1-populate-the-computer-section)
  - [2. Solder Motherboard Jumpers](#2-solder-motherboard-jumpers)
  - [3. Power Up](#3-power-up)
  - [4. Connect a Keyboard and You Should be Operational](#4-connect-a-keyboard-and-you-should-be-operational)
- [Chapter 6: Mount Card Edge Connector](#chapter-6-mount-card-edge-connector)
  - [1. Cut Off Mounting Ears (optional)](#1-cut-off-mounting-ears-optional)
  - [2. Test Fit](#2-test-fit)
  - [3. Solder Card Edge Connector](#3-solder-card-edge-connector)
  - [4. Clean PCB](#4-clean-pcb)
  - [5. Power Up and Retest the Computer](#5-power-up-and-retest-the-computer)
- [Chapter 7: Troubleshooting and Help](#chapter-7-troubleshooting-and-help)
- [Chapter 8: Enhancements to the System](#chapter-8-enhancements-to-the-system)
  - [1. Extra Decoupling Capacitors](#1-extra-decoupling-capacitors)
  - [2. Termination Resistors](#2-termination-resistors)

## Forward
When completed, your Apple 1 computer kit will become an accurate reproduction of one of the most famous computers in the short history of digital computing. The Apple 1 was the first product built and marketed by Apple Computer. The circuitry was designed and prototyped built by Steve Wozniak, prior to the creation of Apple Computer. As Apple was formed, the circuitry designed by Steve Wozniak was turned into a PCB layout by Atari employee, Howard Cantin.

Approximately 200 originals were sold by Apple, and it is unknown how many still exist. Some people think that the number may be as few as 20. Because of the historical significance and rarity, they are very valuable. An original example, recently sold for over $945,000. Extensive research and effort has been extended in order to make reproduction projects like the Mimeo as close to the original in as many respects as possible. Mike Willegal, builder of the Mimeo, has consulted with owners of original Apple 1s, as well as the builders of several replicas in the quest to make his computer as faithful to the original as possible. Currently, there is no data available on the exact routes of traces under chips and certain portions of the silk screen that lies beneath components. Understandably, owners of original systems could not be encouraged to X-ray or dismantle their units in order to uncover this information. The routes and silk screen in these areas are placed based on common sense and the Mimeo Team's experience with the Apple II rev 0, which was also laid out by Howard Cantin.

Some components that you may find are new, old stock parts that are as old or older than the original Apple 1s. Some parts may be new production parts made by the original vendors. Most parts lie somewhere in between these extremes. All digital parts are of the same logic family that was originally specified. Note that the original Apple 1 was most likely made in two batches, with some parts coming from different sources in the different batches, with some overlap as stocks of existing inventories were used up, before transitioning to new stock. Often parts on original Apple 1s were replaced after failures or during modifications.

There is a registry dedicated to documenting known original Apple 1s and plan to provide web pages in which you can compare the parts on your computer to the original. If you are interested in this, see https://www.apple1registry.com/.

## Chapter 1: Assemble Components, Tools, and Equipment

### 1. Recommended Tools and Equipment
- Quality soldering station - Mike Willegal uses a Weller WES51. Whatever you use, it is reccomended to have some kind of temperature controlled tip. jgw4 also reccomends a station with a heat gun attached for soldering onto the large ground planes. These both will help prevent damage to the PCB when soldering
- Solder - use quality solder - thinner solder is vastly easier to work with than fat solder. The fat stuff sold at hardware stores is not suitable for these sort of electronics projects
- Wire cutters – for trimming component leads
- Razor saw – for trimming ears off of edge connectors (if purchasing one with ears).
- Your favorite PCB cleaning agent - Isopropyl Alcohol will dissolve many kinds of soldering resin. Windex will also help with cleaning PCBs
- Ohm meter - to check for good connections and shorts
- Logic probe or oscilloscope – handy if you are having trouble with bring up.
- Apple 1 Operations Manual – PDF copy of original is available in the repository at [`/doc/a1man.pdf`](./a1man.pdf)
- Apple 1 schematics – The Apple-1 Operation Manual schematics are close to actual layout, but there are several  mistakes and differences between the operation manual and actual board. consult the kicad_sch files in the mainboard folder.

### 2. Additional Components (not included)
- ASCII keyboard - currently the only reliable source is from surplus Apple IIplus systems found on eBay. There may exist PS/2 keyboard to ASCII interface converters out there, around on the internet. Otherwise, this repository contains project files to aid you increating a replica Datanetics rev B keyboard from scratch.
- Locate a TV or monitor that supports video composite input and an appropriate video cable.
- You will need to provide connectors, fuse and wiring between the transformers and house wiring. The original Apple-1 Operation Manual has some basic information.

### 3. Read and Understand the Apple 1 Operations Manual.
- This is available in the repository at [`/doc/a1man.pdf`](./a1man.pdf)

### 4. Expansion Options (not included)
- Cassette interface adaptor - project files for creating your own are located in the repository at [`/aci/`](./aci/)
- Cassette recorder and tapes --OR-- MP3 Player with 3.5mm male-male cable – for saving and loading programs through the cassette interface board
- CFFA-1 – Compact flash adaptor - an excellent mass storage for your Apple 1

### 5. Compare Components With Parts List
Examine and identify all parts you have purchased. Confirm any alternative parts are indeed acceptable substitutes indicated in the "PART" column. The first part is the original part number used by Apple.

#### Main Inventory

| Part | Description | Quantity |
| --- | --- | ---: |
| 2513 | char ROM | 1 |
| 8T97 | bus driver | 2 |
| MMI 3601 | 256x4 PROM (1 part labeled LSB, 1 part labeled MSB) | 2 |
| 2504v | shift register | 7 |
| 2519b | shift register | 1 |
| 6820 | parallel interface adapter | 1 |
| DS0025C | clock driver | 1 |
| 6502 | processor | 1 |
| 7400 | quad NAND gate | 3 |
| 7402 | quad NOR gate | 1 |
| 7404 | hex inverter | 1 |
| 7408 | quad and gate | 1 |
| 7410 | three input nand | 2 |
| 74123 | dual one-shot | 1 |
| 74154 | 4:16 demux | 1 |
| 74157 | 2:1 selector | 2 |
| 74160 | 4 bit counter | 1 |
| 74161 (74161A) | 4 bit counter | 5 |
| 74166 | shift register | 1 |
| 74174 | hex flip flop | 1 |
| 74175 | quad flip flop | 1 |
| 7427 | triple 3 input nor gates | 1 |
| 7432 | quad or gate | 1 |
| 7450 | 2 input and gate | 1 |
| 74S257 | 2:1 selector | 4 |
| MK4096 | 4kx1 DRAM | 16 |
| NE555 | cursor timer | 1 |
| Parts (socketed) |  | 61 |
| Types (socketed) |  | 27 |

#### Board and connectors

| Part | Description | Quantity |
| --- | --- | ---: |
| PCB | motherboard | 1 |
| Expansion Connector | 44 pin connector | 1 |
| Power Connector | 6 pin connector | 1 |
| Video Connector | 4 pin connector | 1 |
| Connector Terminals | for 18-24 AWG wire | 10 |
| Power header | 6 pin header | 1 |
| Video header | 4 pin header | 1 |
| Stancor P-8667 | transformer for +12, -12, -5 | 1 |
| Stancor P-8380 | transformer for +5 | 1 |
| Fuse | 0.5A Slow Blow |1|

#### Passive parts and hardware

| Part | Description | Quantity |
| --- | --- | ---: |
| 100 $\Omega$ pot | video adjust | 1 |
| 330 $\Omega$ | orange-orange-brown | 1 |
| 390 $\Omega$ | orange-white-brown | 2 |
| 1500 $\Omega$ | brown-green-red | 1 |
| 3000 $\Omega$ | orange-black-red | 12 |
| 7.5K $\Omega$ | voilet-green-red | 6 |
| 10K $\Omega$ | brown-black-orange | 3 |
| 27K $\Omega$ | red-violet-orange | 1 |
| .001 $\mu$ F capacitor | 102 | 1 |
| .01 $\mu$ F capacitor | 103 | 4 |
| .1 $\mu$ F capacitor | 104 decoupling caps | 17 |
| 47pF cap | video - mica | 1 |
| 22 $\mu$ F | power supply caps - blue | 5 |
| 2400 $\mu$ F cap | +12, -12 power supplies | 2 |
| 5300 $\mu$ F cap | +5 power supply | 1 |
| 1n914 diode | pseudo or gate | 4 |
| 1N4001 diode | rectifier +12, -12 volts | 4 |
| MR500/A14F | (either A14F or MR500 were used used) rectifier +5 volts | 4 |
| MPS3704 | video output transistor | 1 |
| Crystal | clock source | 1 |
| LM323K | +5 volt regulator | 1 |
| LM340 MP-12 (LM7812) | +12 volt regulator | 1 |
| LM320 MP-12 (LM7912) | -12 volt regulator | 1 |
| LM320 MP-5 (LM7905) | -5 volt regulator | 1 |
| heatsink | for LM323K | 1 |
| screws | for LM323K | 2 |
| nuts | for LM323K | 2 |
| heatsink grease | for LM323K | 1 |
| 16 pin socket |  | 42 |
| 14 pin socket |  | 12 |
| 8 pin socket |  | 1 |
| 24 pin socket |  | 2 |
| 40 pin socket |  | 2 |
| Types (soldered) |  | 42 |
| Parts (soldered) |  | 160 |
| Types (total) |  | 69 |
| Parts (total) |  | 221 |
| .1UF | Additional axial decoupling capacitors (see chapter 8)|24|

## Chapter 2: Solder In Sockets and Components

### 1. Remove Card Edge Connector
This connector may have been mounted on the board during shipment to prevent damage to the pins during shipping. You can carefully remove the connector for now, as it will be easier to solder in the sockets without the connector present. Set the connector in a safe place where the pins will not be damaged. The connector will be soldered in later on.
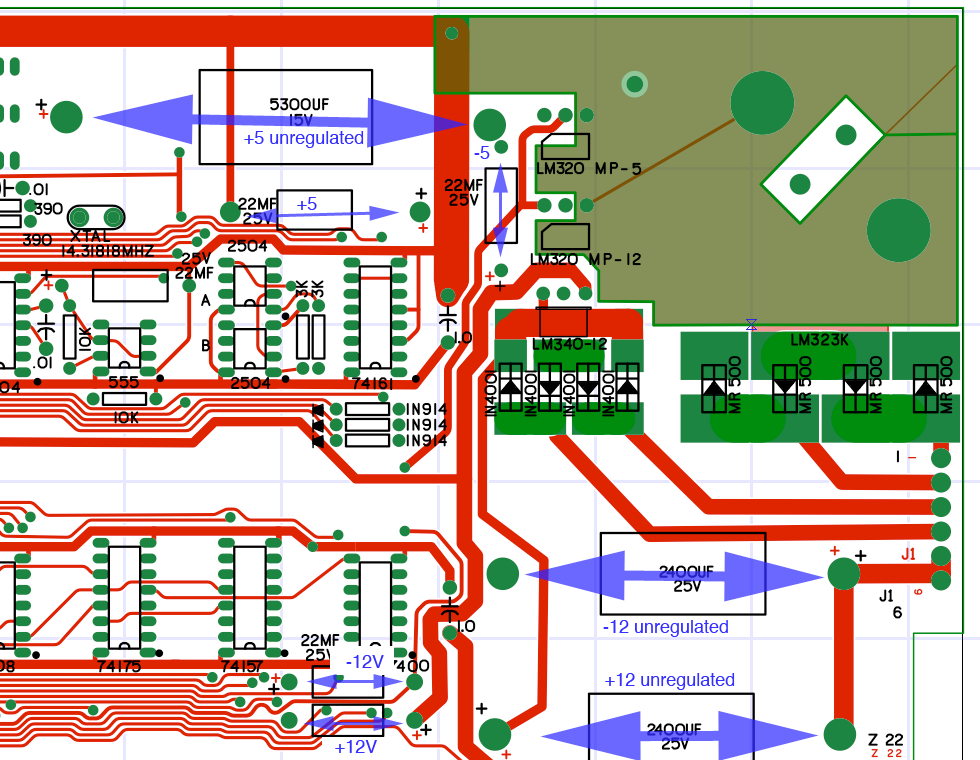
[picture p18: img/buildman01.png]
overview


### 2. Check for Power and Ground Shorts
The easiest way to do this is to use an ohm-meter to make sure that there is no connection between power and ground in any of the power supply nets. Start with the unregulated power supply nets, +5V, +12V and -12V. There is no unregulated -5V net, as input to the -5V regulator is from the -12V regulated supply. The easiest way to check for shorts is by checking for shorts between pads of large capacitors. This is shown in the image above by the large double ended arrows.

Next, check for shorts in the regulated power supply nets, +5V, -5v, +12v and -12v. The pads of smaller capacitors can be used for this. These indicated in the image, above, by the smaller double ended arrows.

### 3. Sockets
The key thing here is to check orientation and make sure that you don’t put a 14 pin socket in a location for a 16 pin socket. Start with the biggest sockets, since you can’t put a big socket in a location for a smaller one. Make sure that the socket is oriented correctly with pin 1 of the socket near to the white dot on the PCB.

Make sure the sockets are fully seated. I accomplish this by resting the socket upside down on a small object with the board on top. The weight of the board should keep the socket completely seated. Then tack down a couple of corner pins and recheck orientation and seating. Then finish soldering the rest of the pins.

Don’t try to do too much in one sitting. Soldering a couple of dozen sockets in an evening is plenty.

### 4. Solder the Two 40-Pin Sockets
Pin 1 is to the right; make sure you orient the sockets correctly.

| Part | Location | Description |
| --- | --- | --- |
| 40 pin socket | A-4 | PIA - pin 1 to right |
| 40 pin socket | A-7 | processor - pin 1 to right |

### 5. Solder the Two 24-Pin Sockets
Pin 1 is to the right; make sure you orient the sockets correctly with pin 1 toward the right of the board.

| Part | Location | Description |
| --- | --- | --- |
| 24 pin socket | B-9 | 74154 - pin1 to right |
| 24 pin socket | D-2 | 2513 - pin 1 to right |

### 6. Solder the Forty-Two 16-Pin Sockets
It's not advised attempt to do this many sockets in one sitting. After a couple of rows or when you get tired, take a break. Check orientation and solder corner pins. Before soldering remaining pins, double check seating and orientation.

| Part | Location | Description |
| --- | --- | --- |
| 16 pin sockets | A-1, A-2 | PROMS |
| 16 pin sockets | A-9, A-10 | Data Bus Drivers |
| 16 pin sockets | A-11 to A-18 | DRAM bank W (8 sockets) |
| 16 pin sockets | B-3 | 74123 |
| 16 pin sockets | B-4 | Keyboard Connector |
| 16 pin socket | B-5 to B-8 | 72257 (4 sockets) |
| 16 pin socket | B-11 to B-18 | DRAM Bank X (8 sockets) |
| 16 pin socket | C-3 | 2519 |
| 16 pin socket | C-4 | 74157 |
| 16 pin sockets | C-7 | 74174 |
| 16 pin socket | C-11(a&b) | 2504 & DS00025 (2 chips in 1 socket) |
| 16 pin socket | C-13 | 74175 |
| 16 pin sockets | C-14 | 74157 |
| 16 pin sockets | D-1 | 74166 |
| 16 pin socket | D4 (a&b), D5 (a&b) | 2504 (4 chips in 2 socket) |
| 16 pin sockets | D-6 | 74160 |
| 16 pin sockets | D-7 to D9 | 74161 (3 sockets) |
| 16 pin socket | D-11 | 74161 |
| 16 pin socket | D14 (a&b) | 2504 (2 chips in 1 socket) |
| 16 pin sockets | D-15 | 74161 |

### 7. Solder the Twelve 14-Pin Sockets
Make sure that all 16 pin sockets are in place before starting this group. This will prevent you from inadvertently inserting a 14 pin socket into a location that needs a 16 pin socket.

| Part | Location | Description |
| --- | --- | --- |
| 14 pin socket | B-1 | 7400 |
| 14 pin socket | B-2 | 7410 |
| 14 pin socket | C-1 | 7404 (6800 only) |
| 14 pin socket | C-5 | 7427 |
| 14 pin socket | C-6 | 7410 |
| 14 pin socket | C-8 | 7450 |
| 14 pin socket | C-9 | 7432 |
| 14 pin socket | C-10 | 7402 |
| 14 pin socket | C-12 | 7408 |
| 14 pin socket | C-15 | 7400 |
| 14 pin socket | D-10 | 7400 |
| 14 pin socket | D-12 | 7404 |

### 8. Solder In the 8 Pin Socket
Make sure that all 16 and 14 pin sockets are in place before starting this group. This will prevent you from inadvertently inserting an 8 pin socket in a location that needs a larger socket.

| Part | Location | Description |
| --- | --- | --- |
| 8 pin socket | D-13 | 555 timer |

### 9. Repeat Check for Power and Ground Shorts

### 10. Solder In the 17 Decoupling Capacitors
These capacitors are labeled at 1.0 on the silk screen, but actual Apple 1 computers used .1 $\mu$ F capacitors in these locations. The easiest way to solder discrete components is to find a way hold the board vertically in a fixture. Place the component in the hole, and bend out the leads slightly, which will hold the component in place. Then, solder on one leg and check to make sure that the component is fully seated before soldering on the other leg. Once soldered in, check your work, and then trim the leads using a small wire cutter. Locations for the decoupling capacitors have a capacitor symbol printed on the circuit board between the two holes. Don’t mistake vias for component mounting holes. Vias have smaller diameter holes and are not connected to a mate with a capacitor symbol on the silk screen. Locations are approximate.

| Part | Location | Description |
| --- | --- | --- |
| .1 $\mu$ F Capacitor | A-8 | right of processor (+5V) |
| .1 $\mu$ F Capacitor | A-12, A-14, A-16, A-18 | between ram sockets (+12V) |
| .1 $\mu$ F Capacitor | B-8 | left of 74154 (+5V) |
| .1 $\mu$ F Capacitor | B-12, B-14, B-16, B18 | between ram sockets (+12V) |
| .1 $\mu$ F Capacitor | B-13 | above and to the right of this location (-5V) |
| .1 $\mu$ F Capacitor | C-8 | between chips (+5V) |
| .1 $\mu$ F Capacitor | C-11, C-11 | don’t confuse location with .001 $\mu$ F capacitors -slightly above and on each side of DS0025 (+5V, -12V) |
| .1 $\mu$ F Capacitor | C-15 | right of 7400 (+5V) |
| .1 $\mu$ F Capacitor | D-8 | between chips (+5V) |
| .1 $\mu$ F Capacitor | D-15 | right of 74161 (+5V) |

### 11. Solder In the Remaining 6 Small Capacitors
These capacitors are labeled labelled correctly on the silk screen. Use same technique as with decoupling ca-
pacitors. Locations are approximate.

| Part | Location | Description |
| --- | --- | --- |
| 47 pF Capacitor | B-3 | mica - left of 74123 |
| .001 $\mu$ F Capactor | B-3 | right of 74123 |
| .01 $\mu$ F Capacitor | C-11, C-11 | left and right of DS0025 - don’t confuse with decoupling capacitors (previous step) |
| .01 $\mu$ F Capacitor | D-12, D-12 | one well above (don’t put in resistor location), one to right of 7404 |

### 12. Repeat Check for Power and Ground Shorts

### 13. Solder In Resistors
Use same process as used for capacitors when soldering. For extra good looks, align all the horizontally oriented resistors the same way (with the gold tolerance bar on the same end). Same thing with vertically oriented
resistors.

| Part | Location | Description |
| --- | --- | --- |
| 3000 $\Omega$ | A-5 | orange-black-red |
| 3000 $\Omega$ (3) | A-8 (all three) | orange-black-red |
| 27K $\Omega$ | B-3 | red-violet-orange |
| 10K $\Omega$ | B-3 | brown-black-orange |
| 7.5K $\Omega$ (6) | C-2 (all six) | voilet-green-red |
| 330 $\Omega$ | C-9 | orange-orange-brown |
| 3000 $\Omega$ | C-11 | orange-black-red |
| 1500 $\Omega$ | D-1 | brown-green-red |
| 100 $\Omega$ pot | D-1 | video adjust, orient so that center tap is towards top of board (connected to video out header) |
| 3000 $\Omega$ | D-2 | orange-black-red |
| 3000 $\Omega$ (2) | D-4 (both) | orange-black-red |
| 3000 $\Omega$ (2) | D-5 (both) | orange-black-red |
| 390 $\Omega$ (2) | D-12 (both) | orange-white-brown |
| 10K $\Omega$ (2) | D-13 (both) | brown-black-orange |
| 3000 $\Omega$ (2) | inbetween D-14/15 (both) | orange-black-red |

>[!TIP]
>After installing the resistors, Uncle Bernie suggests measuring all of them and replacing any that have had their resistance values deviated or are completely open after soldering. Let the joints cool down before measuring.

### 14. Solder In Diodes
>[!NOTE]
>At this point you will be doing a lot of soldering on the ground planes and other large copper areas. Soldering these components is quite more difficult than the previous components. I reccomend using the largest iron tip you have.  If you struggle with these next components like I have, my recommendation is to use a heat gun to heat up the area around the joint, melt a blob of solder onto it, then pass over it again with the iron and heat gun until you see the solder melt and cave in. This method I have found to be much quicker and easier (and potentially safer for the components) than dumping heat into the large copper pads with just an iron tip. -jgw4

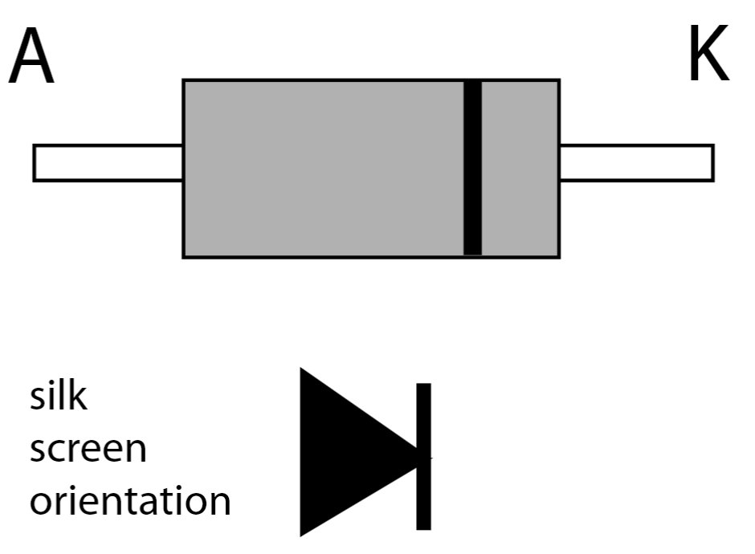
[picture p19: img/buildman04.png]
diode


Diodes must be oriented correctly. There are two ends, anode and cathode. The sure that orientation matches silkscreen. Once oriented correctly, use same soldering process as used for resistors and capacitors when soldering.

| Part | Location | Description |
| --- | --- | --- |
| 1n914 | C-9 | Orient correctly (pseudo or gate) |
| 1n914 (3) | D-15 (all three) | Orient correctly (pseudo or gate) |
| 1N4001 (4) | D-16 | power rectifiers (+12V, -12V, -5V), take careful note of orientation, 2 are reversed, compared to the other 2 |
| MR500/A14F (4) | D-18 | power rectifiers (+5V), take careful note of orientation, 2 are reversed, compared to the other 2. The unit pictured on the cover is MR500 type. If you have MR500 type, these diodes are too long to fit nicely between the holes. You will have to bend the leads under a bit and the diodes will be raised above the surface of the board. The A14F type are small round beads, but also have a line on the cathode end that should be used for orientation. |

### 15. Solder In Medium Electrolytic Caps and Transistor

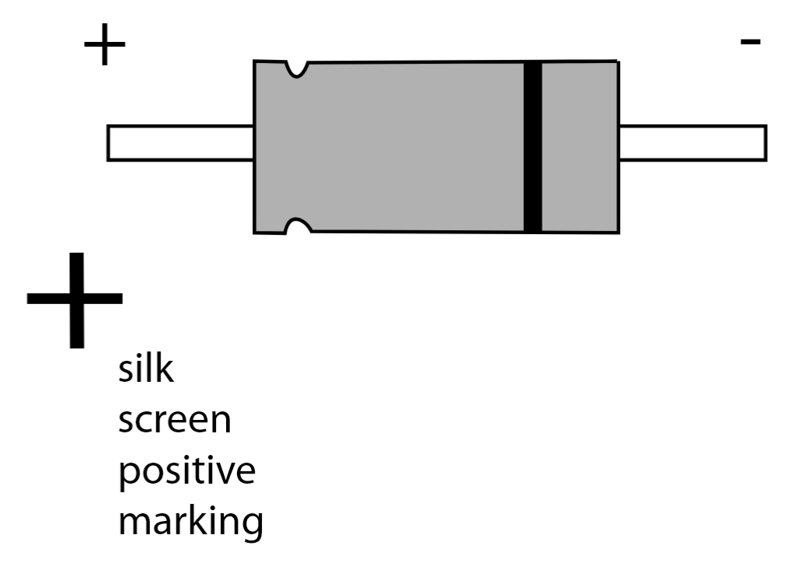
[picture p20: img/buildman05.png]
cap


The electrolytic caps must be oriented correctly. There are two ends, positive and negative. Make sure that orientation is such that the positive end is at the small plus sign printed on the silk screen. Don’t be confused, two of these caps are connected to a negative voltage rail. The plus side of these caps are actually connected to ground, which is correct. Failure to connect properly will likely result in premature failure. Failure of these types of caps, often results in explosions and fires, which can cause serious injury.

| Part | Location | Description |
| --- | --- | --- |
| 22 $\mu$ F capacitor (2) | C-15 | orient correctly, (one in each direction). -12V & +12V |
| 22 $\mu$ F capacitor | D-13 | orient correctly. Cursor timer |
| 22 $\mu$ F capacitor | D-15 | orient correctly. -5V |
| 22 $\mu$ F capacitor | D-15 | orient correctly. cursor flasher |
| MPS3704 Transistor | D-1 | orient correctly - base connects to the two resistors, just below it. See photograph in `/img/` |
| 14MHZ crystal | D-13 | orientation not important |

### 16. Repeat Check for Power and Ground Shorts

### 17. Solder In Power and Video Connectors

Be careful that the power and video connectors are oriented correctly or you will not be able to properly insert the power plug. Refer to the photograph in `/img/`, for reference.

| Part | Location | Description |
| --- | --- | --- |
| Video | D-1 | 4 pin header - shroud toward edge of board (see photograph in `/img/`) |
| Power | C-18 | 6 pin header - shroud toward edge of board (see photograph in `/img/`) |

### 18. Solder In Small Voltage Regulators

The voltage regulators must be oriented correctly. Two of the three are oriented in one direction and the other
in the opposite. Pay attention to the photograph in `/img/`. Once regulators are installed you will no longer
have a completely open connection between power and ground planes.

| Part | Location | Description |
| --- | --- | --- |
| LM340-12 (LM7812) | D-16 | orient correctly with the heat sink towards the top of the board, +12V. |
| LM320 MP-12 (LM7912) | D-16 | orient correctly, with heat sink towards bottom of board (opposite of LM340-12). -12V |
| LM320 MP-5 (LM7905) | D-16 | orient correctly, with heat sink towards bottom of board (like LM320 MP12) |

### 19. Solder In Large Power-Smoothing Capacitors

The electrolytic caps must be oriented correctly. There are two ends, positive and negative. The positive end is clearly marked with a plus sign. Make sure that orientation is such that the positive end is at the small plus sign printed on the silk screen. Failure to connect properly will likely result in premature failure, Failure of these types of caps, often results in an explosion and/or fire, which can cause serious injury.

| Part | Location | Description |
| --- | --- | --- |
| 5300 $\mu$ F | D-1 | orient correctly, unregulated +5v |
| 2400 $\mu$ F(2) | C-17 (both) | orient correctly, (one in each direction). Unregulated -12V & +12V |

>[!TIP]
> Place a piece of 3M double-sided tape on the PCB where the large capacitors are to be soldered. This helps with mechanical stability and soldering.

### 20. Repeat Check for Power and Ground Shorts

### 21. Attach Large +5 Volt Regulator and Heat Sink

The +5 volt regulator sits in the large heat sink and is bolted to the heat sink and board. You can use some of the provided thermal grease to increase heat transfer between the heat sink and the regulator by smearing a small amount of grease on the joint between them. Carefully bolt the regulator and heatsink to the board. Do no overtighten, or you could crush the board. Before soldering the pins of the regulator to the board, make sure that there is no short between those two pins and the ground plane (which is connected to the heat sink). Once regulators are installed you will no longer have a completely open connection between power and ground
planes.
| Part | Location | Description |
| --- | --- | --- |
| LM340-12 (LM7812) | D-16 | orient correctly with the heat sink towards the top of the board, +12V. |
| LM320 MP-12 (LM7912) | D-16 | orient correctly, with heat sink towards bottom of board (opposite of LM340-12). -12V |
| LM320 MP-5 (LM7905) | D-16 | orient correctly, with heat sink towards bottom of board (like LM320 MP12) |

| Part | Location | Description |
| --- | --- | --- |
| heatsink, bolts, nuts, +5 volt regulator | D-18 | make sure unregulated and regulated +5 are not shorted to ground or each other. |

### 22. Repeat Check for Power and Ground Shorts
Congratulations! Except for the expansion connector, you have finished soldering. You will no longer have completely open circuits between power and ground planes, but make sure that there are no “dead” shorts with little to no resistance.

### 23. Clean PCB of Rosin and By-products of Soldering
Clean the back of PCB of excess flux and rosin. 90% or higher isopropyl alcohol. IPA will dissolve soldering resin. Spray it on the back of the board and lightly scrub with a very soft brush that will not scratch the surface of the PCB. Soak up the IPA and contaminates with a clean soft cloth before it evaporates in order to remove the by products of soldering. Let dry overnight. Position a fan to blow over the board to make sure that all remaining moisture evaporates.

“Windex” window cleaner can help remove the by-products from the soldering job. Removing contaminates is important as many kinds of rosins are corrosive.

### 24. Check Board for Solder Bridges and Cold Solder Joints
While the board is drying, you should carefully check your work for bad solder joints and solder bridges.

## Chapter 3: Initial Power Up

### 1. Build the Power Entry Module (PEM)

Instructions can be found in the Apple 1 Operations Manual that can be located in [`/doc/a1man.pdf`](./a1man.pdf). The only recommendation beyond what is in the manual, is that both fuse and switch should go on the “hot” side of the 110V AC input. I strongly recommend that the transformer and 110V AC wiring be placed in some kind of well ventilated enclosure. This is to make sure that no stray body parts touches any part of the 110V AC wiring. It must be well ventilated or fire could result from excessive heat build up.

### 2. Connect Power Supply and Power Up

Because this is a linear power supply, you can power up without populating the board with chips. Connect the power supply and power up. Check for any excessively hot components, especially in the power supply area. If any component is so hot that touching it results in immediate pain, power down and check for shorts

### 3. Check Voltages

Check voltages on the board. The easiest places would be on the various power-smoothing capacitors.

| Voltage | Location | Actual Value |
| --- | --- | --- |
| +5 volt unregulated | 5300 $\mu$ F capacitor at D-15 | Roughly +10 Volts |
| +12 volts unregulated | lower 2400 $\mu$ F capacitor at C-17 | Roughly +20 Volts |
| +12 volts unregulated- | Upper 2400 $\mu$ F capacitor at C-17 | Roughly +20 Volts |
| +5 Volts | horizontal 22 $\mu$ F capacitor at D-15 | +5 Volts |
| -5 Volts | vertical 22 $\mu$ F capacitor at D-16 | -5 Volts |
| +12 Volts | lower 22 $\mu$ F capacitor at C-15 | +12 volts |
| -12 Volts | upper 22 $\mu$ F capacitor at C-15 | -12 Volts |

After checking out voltages, power off the computer.

## Chapter 4: Bring Up The Video Section

Power off the computer before proceeding

### 1. Populate the Video Section
The Apple 1 computer is essentially two complete systems, a microcomputer and a video display system. Because they are largely independent, a large part of the video system can be brought up, prior to bringing up the microcomputer. Populate the ICs needed for the video section (all the ICs in rows C and D, plus the chip in location B-2).

All 8, 14 and 16 pin IC’s are placed with pin one toward the bottom right of the board. The 24 and 40 pin ICs have pin one to the right. When reading the labeling on a chip, pin one is almost always on the bottom left corner. Refer to parts list, list of socket locations, and the KiCad PCB file if you are unsure about placement and orientation of components.

Some manufacturers don’t make parts with legs spaced correctly. These ICs will be easier to insert if the legs are bent to an angle that precisely aligns with the sockets. To do this, place the IC on it’s side on a hard flat surface. One set of pins will be on the surface and pointed towards you. Keeping the IC’s legs held firmly down, carefully roll the chip toward you to slightly bend the chip leads just a bit and then repeat with the process with the chip flipped to its other side. Check for fit against socket and repeat accordingly.

When stuffing chips into sockets, be careful that pins are not inadvertently bent underneath the chip instead of going into the socket. If you do bend a pin, they can be usually be straightened with a small pliers, if you do it carefully. Pins will usually break, right where they connect with the chip case, so do not bend the pin any more
than necessary, especially at the joint, where it mates with the case.

| Part | Description | Location | Quantity |
| --- | --- | --- | ---: |
| 2513 | char ROM | D-2 | 1 |
| 2504v | shift register | D-4a, D-4b, D-5a, D-5b, D-14a, D-14b, C-11b | 7 |
| 2519b | shift register | C-3 | 1 |
| DS0025C | clock driver | C-11a | 1 |
| 7400 | quad NAND gate | C-15, D-10 | 2 |
| 7402 | quad NOR gate | C-10 | 1 |
| 7404 | hex inverter | D-12 | 1 |
| 7408 | quad and gate | C-12 | 1 |
| 7410 | three input nand | B-2, C-6 | 2 |
| 74157 | 2:1 selector | C-4, C-14 | 2 |
| 74160 | 4 bit counter | D-6 | 1 |
| 74161 (74161A) | 4 bit counter | D-7, D-9, D-11, D-15 | 4 |
| 74161* | 4 bit counter | D-8 | 1 |
| 74166 | shift register | D-1 | 1 |
| 74174 | hex flip flop | C-7 | 1 |
| 74175 | quad flip flop | C-13 | 1 |
| 7427 | triple 3 input nor gates | C-5 | 1 |
| 7432 | quad or gate | C-9 | 1 |
| 7450 | 2 input and gate | C-8 | 1 |
| NE555 | curser timer | D-13 | 1 |
| ICs (video section) |  |  | 32 |

*Using a 74161A part in location D-8 may result in intermittent operation

### 2. Connect a Video Display
The Apple 1 outputs a monochrome composite video signal. Any TV or receiver that has composite video input should work as a display device. However note that the composite video signal is digitally generated and some modern displays that digitally process the incoming video signal may have trouble locking into the Apple 1 video signal. Usually an older display without digital processing will perform well. 

Connect the video display device to the video header. You only need to connect pin 2 to the center conductor of a cable with a RCA jack on one end and pin 3 (ground) to the cable shield.

### 3. Checkout Video Section
Power on the computer. Check for any excessively hot components. If any component is so hot, that touching it results in pain, power down and check for shorts or other problems.

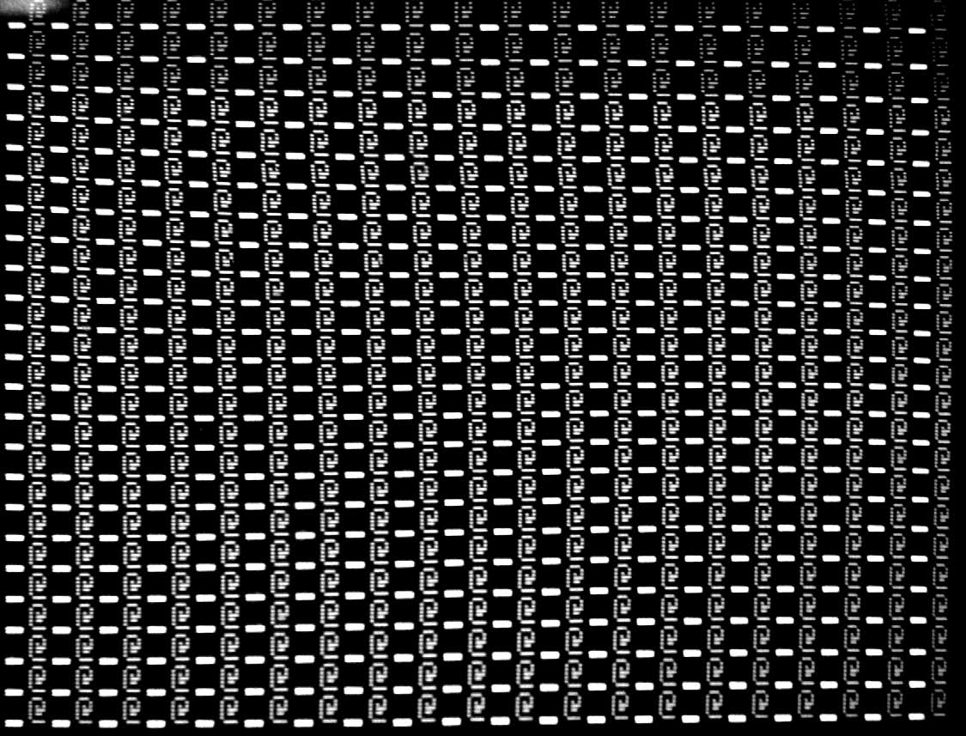
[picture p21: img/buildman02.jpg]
display


At this point, if all is well, you should see a stable display with characters displayed on the screen as shown in this image. Briefly short pin 12 (clear screen) of the keyboard socket to +5v and the screen should become clear. If the display is not working, then you must determine the fault through debugging techniques. See the chapter on debugging for some hints.

## Chapter 5: Populate and Check out the Computer Section

Power off the computer before proceeding

### 1. Populate the Computer Section
Once the video section is basically working, you can bring up the computer section. To start with you only need
to populate one bank of DRAM. Populate the processor section ICs using the same method as used for bring-
ing up the video section.

| Part | Description | Location | Quantity |
| --- | --- | --- | ---: |
| 8T97 | bus driver | A-9, A-10 | 2 |
| MMI 3601 (LSB) | 256x4 PROM, LSB (least significant nibble) | A-1 | 1 |
| MMI 3601 (MSB) | 256x4 PROM MSB (most significant nibble) | A-2 | 1 |
| 6820 | parallel interface adapter | A-4 | 1 |
| 6502 | processor | A-7 | 1 |
| 7400 | quad NAND gate | B-1 | 1 |
| 74123 | dual one-shot | B-3 | 1 |
| 74154 | 4:16 demux | B-9 | 1 |
| 74S257 | 2:1 selector | B-5, B-6, B-7, B-8 | 4 |
| MK4096 | 4kx1 DRAM bank "X" | B-11 through B-18 | 8 |
| ICs (processor section) |  |  | 21 |

At this point, all IC locations should be populated, except DRAM row “W” and the 6800 only location at C1.

### 2. Solder Motherboard Jumpers

| Jumper | Location | Description |
| --- | --- | --- |
| 6502 | A-5 | Use a blob of solder to connect the two traces |
| 6502 | A-8 | Use a blob of solder to connect the two traces |
| NO DMA | A-10 | Use a blob of solder to connect the two traces. If you add an expansion card that controls the DMA line, then you should remove this solder jumper |
| DRAM | B-9 | For initial bring up, DRAM bank X is jumpered by adding a blob of solder to connect address select "0" to bank "X". Later on when bank "W" is added, it will normally be jumpered to bank "E" to enable running BASIC |
| PROM | B-9 | Use a blob of solder to short address "F" to "Y" |
| PIA | B-9 | Use a short jumper wire to short address "D" to "Z" |

### 3. Power Up

Power up and you should see the same display as when you brought up the video section. Check for any excessively hot components. If any component is so hot, that touching it results in pain, power down and check for shorts or other problems.

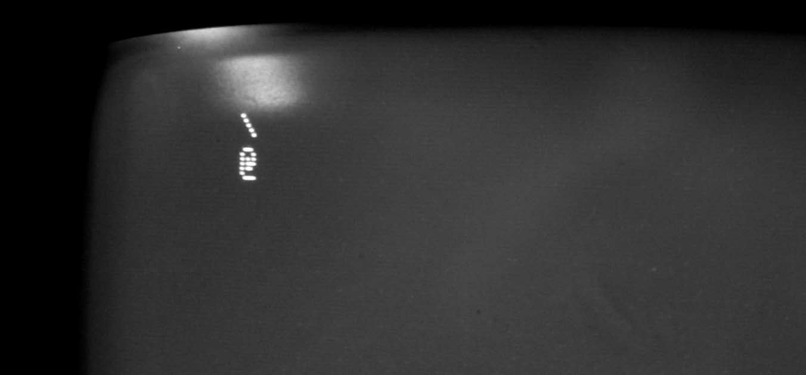
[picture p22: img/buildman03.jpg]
start


After both clear and reset, you have a backslash and prompt at the top left corner of the screen.

Briefly short pin 12 (clear screen) of the keyboard socket to +5v and the screen should become clear. At this point you should be able to reset the processor section and see a prompt be displayed. To reset the system and get a prompt, use a temporary jumper to short pin 1 of the keyboard connector to a nearby ground pin (pin 9 of keyboard connector).

Note that without a keyboard attached, random characters may be input. This is because the keyboard strobe input to the PIA is floating. To stop this you can use a temporarily jumper to short pin 40 of the 6840 to pin 1 of the 6502.

### 4. Connect a Keyboard and You Should be Operational
Refer to the Apple 1 Operations Manual for keyboard interface specification. Apple II and II plus keyboards have different pinouts, but may be adapted to the Apple 1 keyboard interface through simple rewiring. Miswiring has a good possibility of damaging components on both the Apple 1 and the keyboard, so go slow and double or triple check your work before powering up. There is a good description of an Apple II keyboard adaptor at John Calende’s blog http://apple1computer.blogspot.com/.

## Chapter 6: Mount Card Edge Connector

### 1. Cut Off Mounting Ears (optional)
You may have purchased an edge connector with mounting ears. Original Apple 1s had edge connectors without ears. Using a razor saw (available at any hobby store), you can carefully cut off the ears to more closely mimic the look of the edge connector of an original Apple 1. Polishing the cut surface will remove any rough surfaces. A polishing bit in a rotary tool can be used for this purpose.

### 2. Test Fit
This connector may fit somewhat tightly into the holes on the PCB. If it doesn’t seat correctly, check for bent pins on the connectors. Straighten any bent pins and carefully insert the connector into the PCB.

### 3. Solder Card Edge Connector
Tack down a couple of pins on each end of the connector and check for good seating of the connector in the
PCB. Then proceed to solder the remaining pins.

| Part | Location | Description |
| --- | --- | --- |
| Card edge connector | J-3 | expansion slot |

### 4. Clean PCB

### 5. Power Up and Retest the Computer

## Chapter 7: Troubleshooting and Help
The complexity of the processor and video systems can make troubleshooting an Apple I a bit involved. A good job of soldering the components into place should eliminate most if not all trouble. First step, in case of trouble, should be to check for bad solder joints or bridges. Secondly, check for bad or incorrect coponents or substitute components

Refer to my Apple II repair page at www.willegal.net for some general troubleshooting hints. Note, that with a
properly constructed replica, you should have no trouble with intermittent sockets that are constant issues with
vintage Apple computers.

## Chapter 8: Enhancements to the System

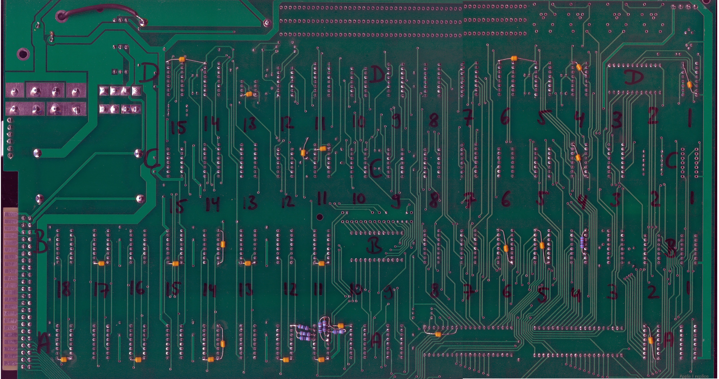
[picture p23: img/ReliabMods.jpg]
Uncle Bernie's Capacitors


### 1. Extra Decoupling Capacitors
It has been well noted among enthusiasts that the Apple-1  does not have enough decoupling capacitors. It has been advised to add additional .1UF decoupling capacitors to the board to make the computer more reliable, on top of the ones that are traditionally populated on the board. This can be done in a few different ways, but most commonly axial capacitors are soldered between the spacer portions of the IC socket pins needed to hide them, soldered to the back side of the board using the back solder pads of the sockets, or they can be jumped to from capacitors mounted in the breadboard area. Whatever solution you choose, it is strongly suggested to do this if you will be using the computer frequently. To preserve aesthetics, many choose to find small axial MLCCs that can be hidden under IC sockets or behind the board.

An industry rule of thumb I have read is that 1 of every 2 chips needs a decoupling cap, so not every socket needs a capacitor. There are 24 needed in total, and a value of .1UF is advised.

Locations and quantity of the extra decoupling capacitors needed are as follows:
* 1 between pins 8 and 16 of PROM A2
* 1 between pins 1 and 8 of the 6502 or between pins 1 and 20 of the 6820 (spanning this is difficult, the 6502 is the easier and shorter option)
* 8 between pins 1 and 16 of RAM chips W0 (A18), W2(A16), W6(A12), W7 (A11), X1 (B17), X3(B15), X5(B13), and X7 (B11).
* 4 (2 per ram chip) on chips W4 and W7. 1 capacitor should bridge pin 9 (+5V) and pin 16 (GND), and the other capacitor should join pin 1 and pin 16
* 1 between pins 9 and 16 of X4 (B14)
* 2 Between pins 8 and 16 of 2 of the 4 74S257 located at B5-B6
* 1 between pins 3 and 6 of DS0025 (C11A)
* 1 between pins 8 and 16 of 74157 (C4)
* 1 between pins 1 and 8 of the 555 timer at D13
* 1 between pins 4 and 8 of a 2504 at D4 or D5
* 1 between pins 8 and 16 of 74166 at D1

The decoupling locations below span chips and cannot be hidden within a socket
* 1 between pin 8 of 8T97 (A10) and pin 9 of W7 (A11)
* 1 between pin 4 of 2504 at D5A and pin 8 of 74160 at D6
* 1 between pin 4 of 2504 at D14A and pin 8 of 74161 at D15
* 1 in the space between chip locations C11 and C12, there is a 3k resistor with a pad connected to pin 4 of the C11B 2504 (this can be observed on the back copper trace), and a capcitor marked 1.0 with a pad connected to the large ground rail above the chip (this can be observed on the front copper trace). These two pads should be joined with a decoupling capacitor on the back of the board.

### 2. Termination Resistors

there are 6 390 Ohm termination resistors advised in the following locations

* 3 between pin 9 (ground) of W6 (A12) and pins 5,6, and 7 of W7 (A11). 
* 3 between pin 9 and pins 10, 11, and 12 of W7 (A11)

1 additional 20k Ohm resistor is advised for the keyboard connector. Uncle Bernie says: "[This] allows to [sic] unplug the keyboard cable while the Apple-1 runs, without spurious phantom key entries being provoked."

* B4, between pins 9 and 14 (keyboard connector)

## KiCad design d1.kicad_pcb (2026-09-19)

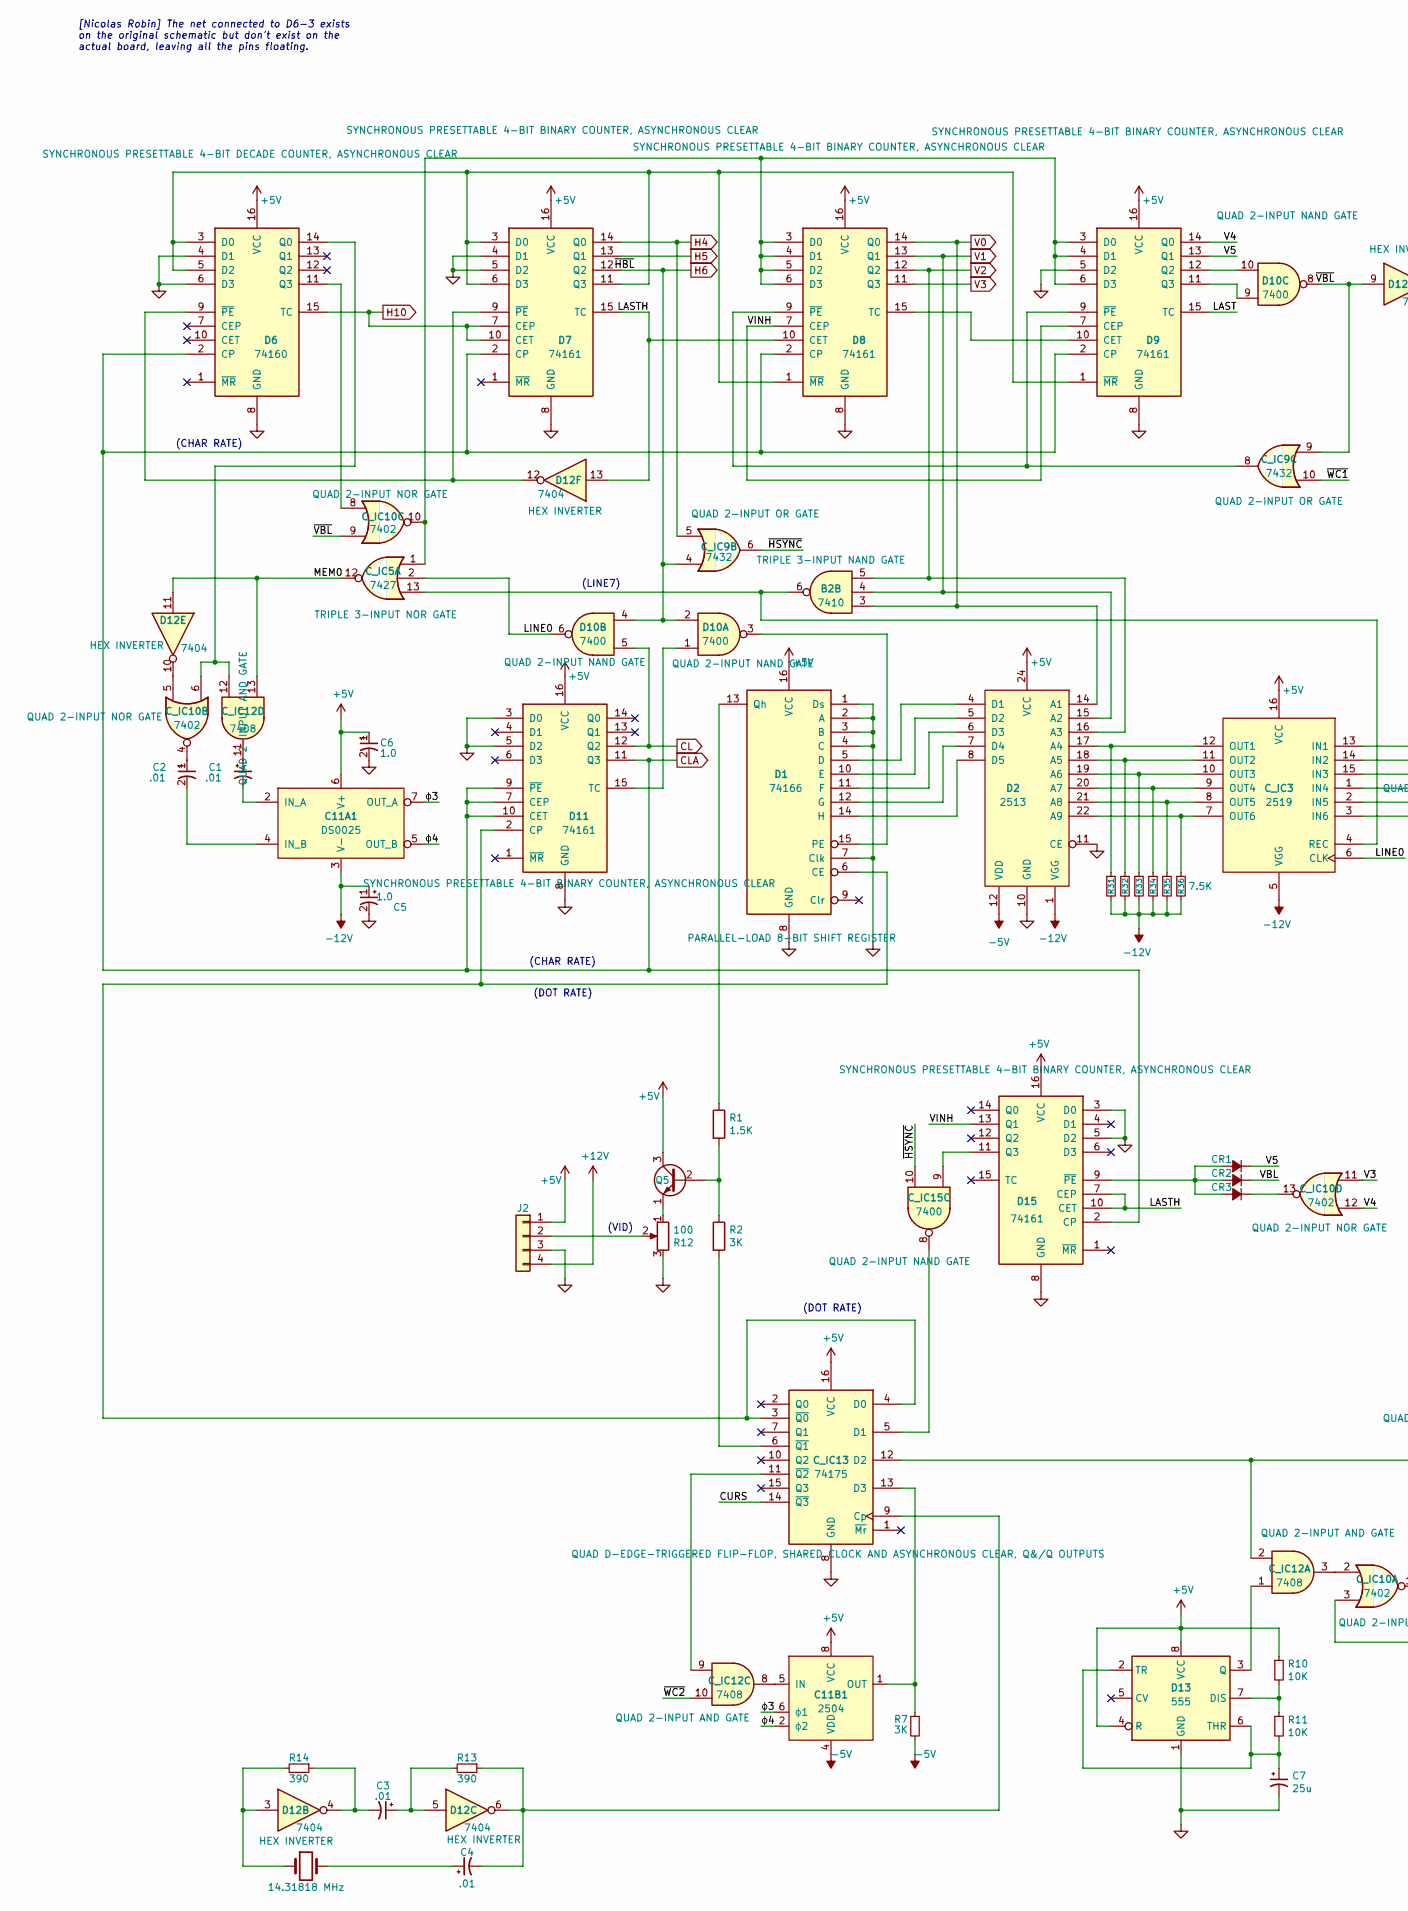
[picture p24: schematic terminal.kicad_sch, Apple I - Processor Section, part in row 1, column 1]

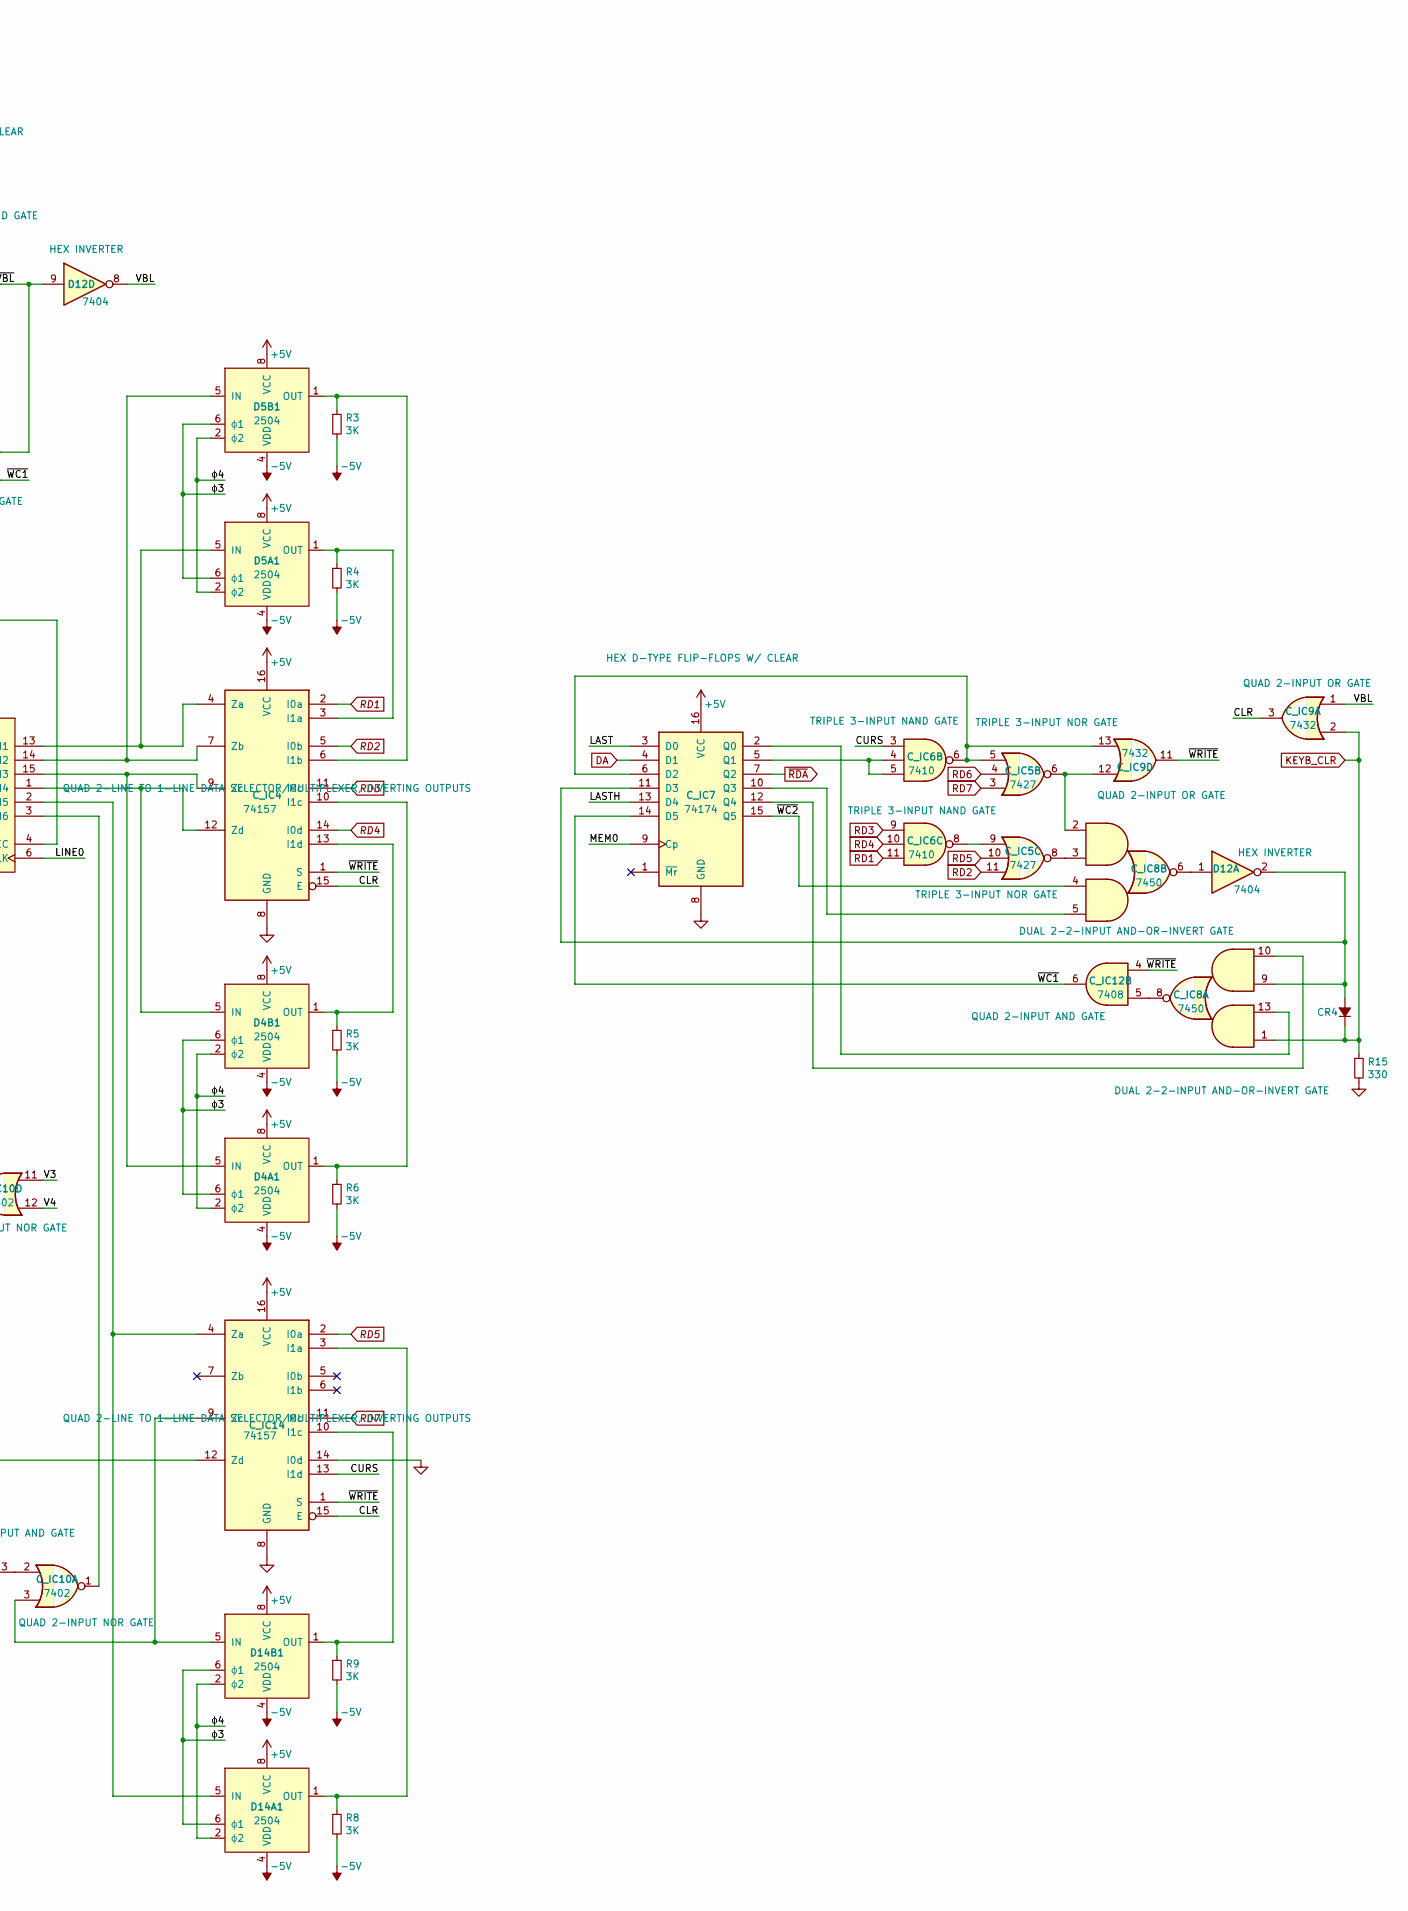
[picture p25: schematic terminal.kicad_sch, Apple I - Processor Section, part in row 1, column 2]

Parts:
B2: 7410; apple-1_DIP-14_W7.62mm
C1, C2, C3, C4: .01; apple-1_C_Disc_D16.0mm_W5.0mm_P7.50mm
C5, C6: 1.0; apple-1_C_Disc_D16.0mm_W5.0mm_P7.50mm
C7: 25u; CP_Axial_25u
C11A1: DS0025; apple-1_DIP-8_W7.62mm
C11B1: 2504; apple-1_DIP-8_W7.62mm
CR1, CR2, CR3, CR4: 1N914; apple-1_D_DO-35_SOD27_P10.16mm_Horizontal_altarrow
C_IC3: 2519; apple-1_DIP-16_W7.62mm
C_IC4, C_IC14: 74157; apple-1_DIP-16_W7.62mm
C_IC5: 7427; apple-1_DIP-14_W7.62mm
C_IC6: 7410; apple-1_DIP-14_W7.62mm
C_IC7: 74174; apple-1_DIP-16_W7.62mm
C_IC8: 7450; apple-1_DIP-14_W7.62mm
C_IC9: 7432; apple-1_DIP-14_W7.62mm
C_IC10: 7402; apple-1_DIP-14_W7.62mm
C_IC12: 7408; apple-1_DIP-14_W7.62mm
C_IC13: 74175; apple-1_DIP-16_W7.62mm
C_IC15: 7400; apple-1_DIP-14_W7.62mm
D1: 74166; apple-1_DIP-16_W7.62mm
D2: 2513; apple-1_DIP-24_18.0mmx34.29mm_W15.24mm
D4A1, D4B1, D5A1, D5B1, D14A1, D14B1: 2504; apple-1_DIP-8_W7.62mm
D6: 74160; apple-1_DIP-16_W7.62mm
D7, D8, D9, D11, D15: 74161; apple-1_DIP-16_W7.62mm
D10: 7400; apple-1_DIP-14_W7.62mm
D12: 7404; apple-1_DIP-14_W7.62mm
D13: 555; apple-1_DIP-8_W7.62mm
J2: Conn_01x04; apple-1_JST_VH_B4P-VH_1x04_P3.96mm_Vertical
Q5: MPS3704; apple-1_TO-92_HandSolder
R1: 1.5K; apple-1_R_Axial_DIN0207_L6.3mm_D2.5mm_P10.16mm_Horizontal
R2, R3, R4, R5, R6, R7, R8, R9: 3K; apple-1_R_Axial_DIN0207_L6.3mm_D2.5mm_P10.16mm_Horizontal
R10, R11: 10K; apple-1_R_Axial_DIN0207_L6.3mm_D2.5mm_P10.16mm_Horizontal
R12: 100; apple-1_Potentiometer_Bourns_3329H_Vertical
R13, R14: 390; apple-1_R_Axial_DIN0207_L6.3mm_D2.5mm_P10.16mm_Horizontal
R15: 330; apple-1_R_Axial_DIN0207_L6.3mm_D2.5mm_P10.16mm_Horizontal
R31, R32, R33, R34, R35, R36: 7.5K; apple-1_R_Axial_DIN0207_L6.3mm_D2.5mm_P10.16mm_Horizontal
Y1: 14.31818 MHz; apple-1_Crystal_HC49-U_Vertical

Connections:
+5V: C6.1, C11A1.6 (V+), C11B1.8 (VCC), C_IC3.16 (VCC), C_IC4.16 (VCC), C_IC7.16 (VCC), C_IC13.16 (VCC), C_IC14.16 (VCC), D1.16 (VCC), D2.24 (VCC), D4A1.8 (VCC), D4B1.8 (VCC), D5A1.8 (VCC), D5B1.8 (VCC), D6.16 (VCC), D7.16 (VCC), D8.16 (VCC), D9.16 (VCC), D11.16 (VCC), D13.4 (R), D13.8 (VCC), D14A1.8 (VCC), D14B1.8 (VCC), D15.16 (VCC), J2.1, Q5.3 (C), R10.1; also elsewhere on the board
+12V: J2.4; also elsewhere on the board
-5V: C11B1.4 (VDD), D2.12 (VDD), D4A1.4 (VDD), D4B1.4 (VDD), D5A1.4 (VDD), D5B1.4 (VDD), D14A1.4 (VDD), D14B1.4 (VDD), R3.2, R4.2, R5.2, R6.2, R7.2, R8.2, R9.2; also elsewhere on the board
-12V: C5.1, C11A1.3 (V-), C_IC3.5 (VGG), D2.1 (VGG), R31.2, R32.2, R33.2, R34.2, R35.2, R36.2; also elsewhere on the board
/Terminal Section/CLR: C_IC4.15 (E), C_IC9.3, C_IC14.15 (E)
/Terminal Section/CURS: C_IC6.3, C_IC13.14 (~Q3), C_IC14.13 (I1d)
/Terminal Section/LAST: C_IC7.3 (D0), D9.15 (TC)
/Terminal Section/LASTH: C_IC7.13 (D4), D7.15 (TC), D8.10 (CET), D12.13, D15.7 (CEP), D15.10 (CET)
/Terminal Section/LINE0: C_IC3.6 (CLK), C_IC5.2, D10.6
/Terminal Section/MEM0: C_IC5.12, C_IC7.9 (Cp), C_IC12.13, D12.11
/Terminal Section/V4: C_IC10.12, D9.14 (Q0)
/Terminal Section/V5: CR1.1 (K), D9.13 (Q1)
/Terminal Section/VBL: CR2.1 (K), C_IC9.1, D12.8
/Terminal Section/VINH: D8.7 (CEP), D9.7 (CEP), D15.13 (Q1)
/Terminal Section/~HSYNC: C_IC9.6, C_IC15.10
/Terminal Section/~VBL: C_IC9.9, C_IC10.9, D10.8, D12.9
/Terminal Section/~WC1: C_IC7.14 (D5), C_IC9.10, C_IC12.6
/Terminal Section/~WC2: C_IC7.15 (Q5), C_IC8.4, C_IC12.10
/Terminal Section/~WRITE: C_IC4.1 (S), C_IC9.11, C_IC12.4, C_IC14.1 (S)
/Terminal Section/ɸ3: C11A1.7 (OUT_A), C11B1.6 (ɸ1), D4A1.6 (ɸ1), D4B1.6 (ɸ1), D5A1.6 (ɸ1), D5B1.6 (ɸ1), D14A1.6 (ɸ1), D14B1.6 (ɸ1)
/Terminal Section/ɸ4: C11A1.5 (OUT_B), C11B1.2 (ɸ2), D4A1.2 (ɸ2), D4B1.2 (ɸ2), D5A1.2 (ɸ2), D5B1.2 (ɸ2), D14A1.2 (ɸ2), D14B1.2 (ɸ2)
CL: D10.5, D11.12 (Q2); also elsewhere on the board
CLA: D6.2 (CP), D7.2 (CP), D8.2 (CP), D9.2 (CP), D11.7 (CEP), D11.9 (~PE), D11.10 (CET), D11.11 (Q3), D15.2 (CP); also elsewhere on the board
DA: C_IC7.4 (D1); also elsewhere on the board
H4: C_IC9.5, D7.14 (Q0); also elsewhere on the board
H5: D7.13 (Q1); also elsewhere on the board
H6: C_IC9.4, D7.12 (Q2), D10.2, D10.4; also elsewhere on the board
H10: D6.15 (TC), D7.7 (CEP), D7.10 (CET); also elsewhere on the board
KEYB_CLR: CR4.1 (K), C_IC8.1, C_IC9.2, R15.1; also elsewhere on the board
unnamed: C1.1, C_IC12.11
unnamed: C2.1, C_IC10.4
unnamed: C3.1, D12.5, R13.2
unnamed: C3.2, D12.4, R14.1
unnamed: C4.1, Y1.2
unnamed: C1.2, C11A1.2 (IN_A)
unnamed: C2.2, C11A1.4 (IN_B)
unnamed: C11B1.5 (IN), C_IC12.8
unnamed: C11B1.1 (OUT), C_IC13.13 (D3), R7.1
unnamed: CR1.2 (A), CR2.2 (A), CR3.2 (A), D15.9 (~PE)
unnamed: CR3.1 (K), C_IC10.13
unnamed: CR4.2 (A), C_IC7.11 (D3), C_IC8.9, D12.2
unnamed: C_IC3.13 (IN1), C_IC4.4 (Za), D5A1.5 (IN)
unnamed: C_IC3.14 (IN2), C_IC4.7 (Zb), D5B1.5 (IN)
unnamed: C_IC3.15 (IN3), C_IC4.9 (Zc), D4A1.5 (IN)
unnamed: C_IC3.1 (IN4), C_IC4.12 (Zd), D4B1.5 (IN)
unnamed: C_IC3.3 (IN6), C_IC10.1
unnamed: C_IC3.12 (OUT1), D2.17 (A4), R31.1
unnamed: C_IC3.11 (OUT2), D2.18 (A5), R32.1
unnamed: C_IC3.10 (OUT3), D2.19 (A6), R33.1
unnamed: C_IC3.9 (OUT4), D2.20 (A7), R34.1
unnamed: C_IC3.8 (OUT5), D2.21 (A8), R35.1
unnamed: C_IC3.7 (OUT6), D2.22 (A9), R36.1
unnamed: B2.6, C_IC3.4 (REC), C_IC5.13
unnamed: C_IC4.3 (I1a), D5A1.1 (OUT), R4.1
unnamed: C_IC4.6 (I1b), D5B1.1 (OUT), R3.1
unnamed: C_IC4.10 (I1c), D4A1.1 (OUT), R6.1
unnamed: C_IC4.13 (I1d), D4B1.1 (OUT), R5.1
unnamed: C_IC5.6, C_IC8.2, C_IC9.12
unnamed: C_IC5.8, C_IC8.3
unnamed: C_IC5.9, C_IC6.8
unnamed: C_IC5.5, C_IC6.6, C_IC7.6 (D2), C_IC9.13
unnamed: C_IC7.2 (Q0), C_IC8.13
unnamed: C_IC6.4, C_IC6.5, C_IC7.5 (Q1)
unnamed: C_IC7.10 (Q3), C_IC8.5
unnamed: C_IC7.12 (Q4), C_IC8.10
unnamed: C_IC8.6, D12.1
unnamed: C_IC10.2, C_IC12.3
unnamed: C_IC10.5, D12.10
unnamed: C_IC8.8, C_IC12.5
unnamed: C4.2, C_IC13.9 (Cp), D12.6, R13.1
unnamed: C_IC13.3 (~Q0), C_IC13.4 (D0), D1.6 (CE), D11.2 (CP)
unnamed: C_IC13.5 (D1), C_IC15.8
unnamed: C_IC12.2, C_IC13.12 (D2), C_IC14.12 (Zd)
unnamed: C_IC13.6 (~Q1), R2.2
unnamed: C_IC12.9, C_IC13.11 (~Q2)
unnamed: C_IC14.3 (I1a), D14A1.1 (OUT), R8.1
unnamed: C_IC14.10 (I1c), D14B1.1 (OUT), R9.1
unnamed: C_IC3.2 (IN5), C_IC14.4 (Za), D14A1.5 (IN)
unnamed: C_IC10.3, C_IC14.9 (Zc), D14B1.5 (IN)
unnamed: D1.5 (D), D2.4 (D1)
unnamed: D1.10 (E), D2.5 (D2)
unnamed: D1.11 (F), D2.6 (D3)
unnamed: D1.12 (G), D2.7 (D4)
unnamed: D1.14 (H), D2.8 (D5)
unnamed: D1.15 (PE), D10.3
unnamed: D1.13 (Qh), R1.1
unnamed: D6.3 (D0), D6.5 (D2), D7.3 (D0), D7.6 (D3), D7.11 (Q3), D8.1 (~MR), D9.1 (~MR)
unnamed: C_IC10.6, C_IC12.12, D6.14 (Q0)
unnamed: C_IC10.8, D6.11 (Q3)
unnamed: D6.9 (~PE), D7.9 (~PE), D12.12
unnamed: C_IC5.1, C_IC10.10, D8.3 (D0), D8.4 (D1), D8.5 (D2), D8.6 (D3), D9.3 (D0), D9.4 (D1), D9.6 (D3)
unnamed: D8.15 (TC), D9.10 (CET)
unnamed: C_IC9.8, D8.9 (~PE), D9.9 (~PE)
unnamed: D9.12 (Q2), D10.10
unnamed: D9.11 (Q3), D10.9
unnamed: D10.1, D11.15 (TC)
unnamed: D12.3, R14.2, Y1.1
unnamed: D13.7 (DIS), R10.2, R11.1
unnamed: C_IC12.1, D13.3 (Q)
unnamed: C7.1, D13.2 (TR), D13.6 (THR), R11.2
unnamed: C_IC15.9, D15.11 (Q3)
unnamed: J2.2, R12.2
unnamed: Q5.2 (B), R1.2, R2.1
unnamed: Q5.1 (E), R12.1
RD1: C_IC4.2 (I0a), C_IC6.11; also elsewhere on the board
RD2: C_IC4.5 (I0b), C_IC5.11; also elsewhere on the board
RD3: C_IC4.11 (I0c), C_IC6.9; also elsewhere on the board
RD4: C_IC4.14 (I0d), C_IC6.10; also elsewhere on the board
RD5: C_IC5.10, C_IC14.2 (I0a); also elsewhere on the board
RD6: C_IC5.4; also elsewhere on the board
RD7: C_IC5.3, C_IC14.11 (I0c); also elsewhere on the board
V0: B2.3, D2.14 (A1), D8.14 (Q0); also elsewhere on the board
V1: B2.4, D2.15 (A2), D8.13 (Q1); also elsewhere on the board
V2: B2.5, D2.16 (A3), D8.12 (Q2); also elsewhere on the board
V3: C_IC10.11, D8.11 (Q3); also elsewhere on the board
~RDA: C_IC7.7 (Q2); also elsewhere on the board

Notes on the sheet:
(LINE7)
(CHAR RATE)
[Nicolas Robin] The net connected to D6-3 exists on the original schematic but don't exist on the actual board, leaving all the pins floating.
(DOT RATE)
(VID)

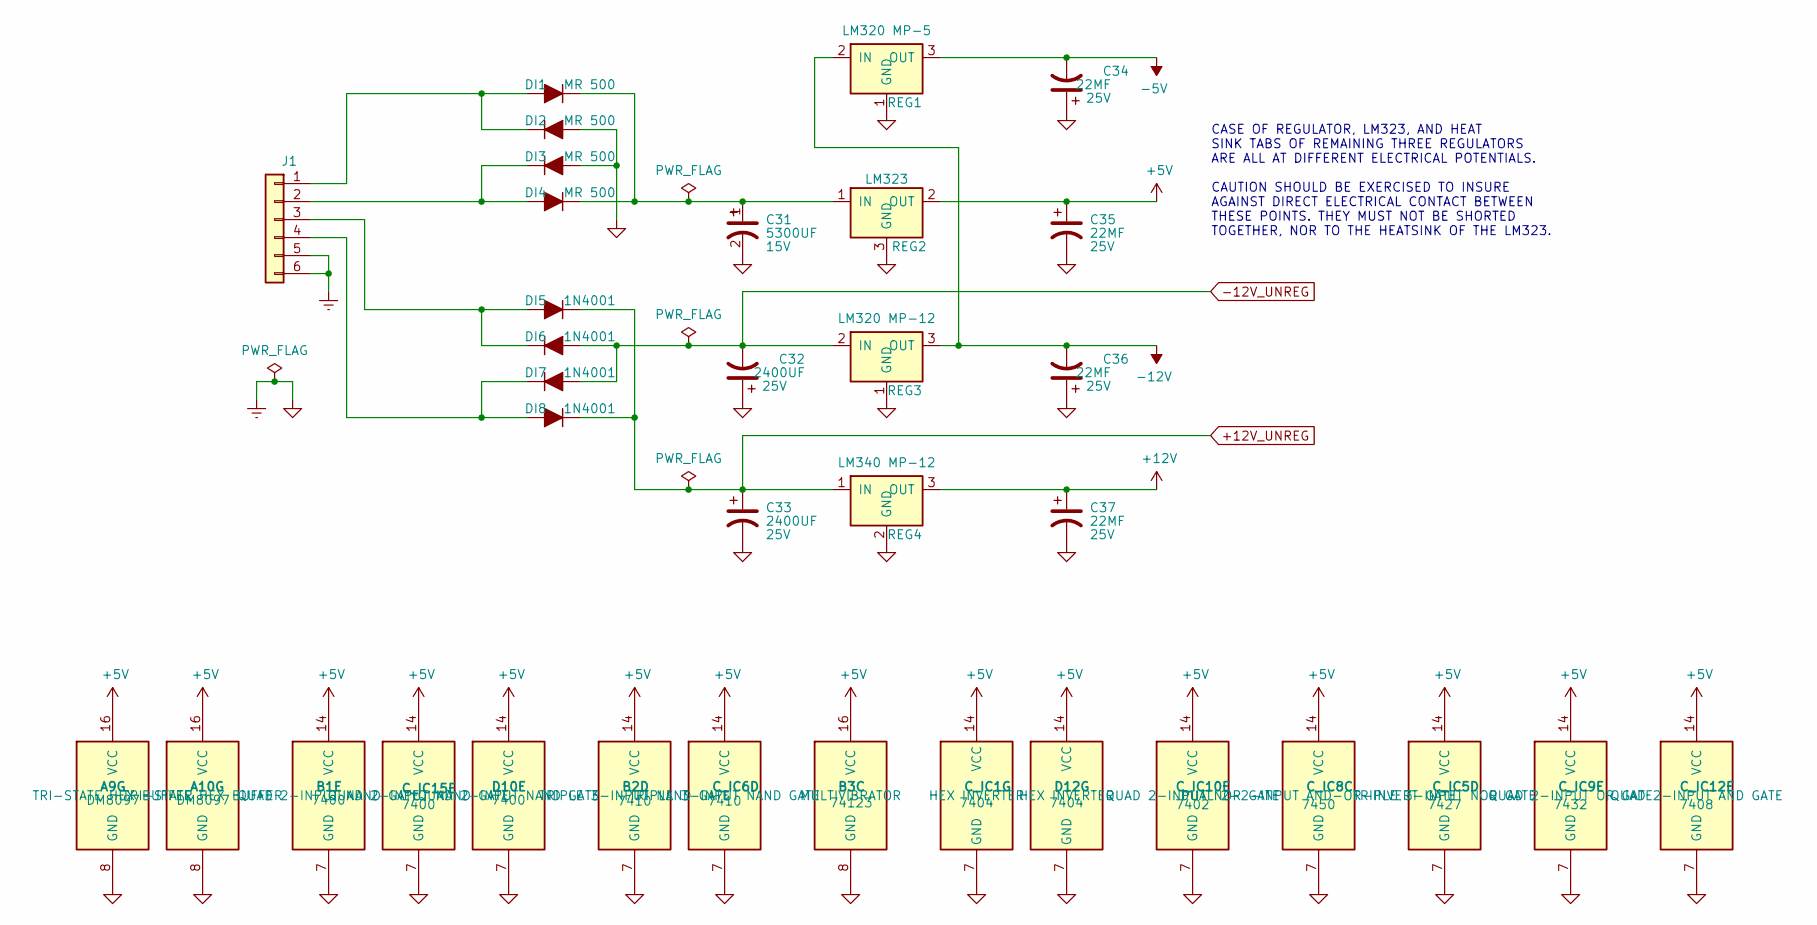
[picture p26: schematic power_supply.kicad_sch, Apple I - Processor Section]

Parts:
A9, A10: DM8097; apple-1_DIP-16_W7.62mm
B1: 7400; apple-1_DIP-14_W7.62mm
B2: 7410; apple-1_DIP-14_W7.62mm
B3: 74123; apple-1_DIP-16_W7.62mm
C31: 5300UF; CP_Axial_5300uF; Voltage 15V
C32, C33: 2400UF; apple-1_CP_2400UF_25V_-+; Voltage 25V
C34, C36, C37: 22MF; apple-1_C_Axial_L12.0mm_D6.5mm_P20.00mm_Horizontal; Voltage 25V
C35: 22MF; apple-1_C_Axial_22MF_25V_P1200mils_Horizontal; Voltage 25V
C_IC1: 7404; apple-1_DIP-14_W7.62mm
C_IC5: 7427; apple-1_DIP-14_W7.62mm
C_IC6: 7410; apple-1_DIP-14_W7.62mm
C_IC8: 7450; apple-1_DIP-14_W7.62mm
C_IC9: 7432; apple-1_DIP-14_W7.62mm
C_IC10: 7402; apple-1_DIP-14_W7.62mm
C_IC12: 7408; apple-1_DIP-14_W7.62mm
C_IC15: 7400; apple-1_DIP-14_W7.62mm
D10: 7400; apple-1_DIP-14_W7.62mm
D12: 7404; apple-1_DIP-14_W7.62mm
DI1, DI2, DI3, DI4: MR 500; apple-1_D_5W_P10.16mm_Horizontal
DI5, DI6, DI7, DI8: 1N4001; apple-1_D_5W_P10.16mm_Horizontal
J1: Conn_01x06; apple-1_JST_VH_B6P-VH_1x06_P3.96mm_Vertical
REG1: LM320 MP-5; LM320 MP-5 (TO-220-3_Vertical_SpacedPins)
REG2: LM323; TO-3
REG3: LM320 MP-12; LM320 MP-12 (TO-220-3_Vertical_SpacedPins)
REG4: LM340 MP-12; LM340-12 (TO-220-3_Vertical_SpacedPins)

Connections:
+5V: A9.16 (VCC), A10.16 (VCC), B1.14 (VCC), B2.14 (VCC), B3.16 (VCC), C35.1, C_IC1.14 (VCC), C_IC5.14 (VCC), C_IC6.14 (VCC), C_IC8.14 (VCC), C_IC9.14 (VCC), C_IC10.14 (VCC), C_IC12.14 (VCC), C_IC15.14 (VCC), D10.14 (VCC), D12.14 (VCC), REG2.2 (OUT); also elsewhere on the board
+12V: C37.1, REG4.3 (OUT); also elsewhere on the board
+12V_UNREG: C33.1, DI5.1 (K), DI8.1 (K), REG4.1 (IN); also elsewhere on the board
-5V: C34.2, REG1.3 (OUT); also elsewhere on the board
-12V: C36.2, REG1.2 (IN), REG3.3 (OUT); also elsewhere on the board
-12V_UNREG: C32.2, DI6.2 (A), DI7.2 (A), REG3.2 (IN); also elsewhere on the board
unnamed 216: DI1.2 (A), DI2.1 (K), J1.1; also elsewhere on the board
unnamed: C31.1, DI1.1 (K), DI4.1 (K), REG2.1 (IN)
unnamed 218: DI3.1 (K), DI4.2 (A), J1.2; also elsewhere on the board
unnamed 219: DI5.2 (A), DI6.1 (K), J1.3; also elsewhere on the board
unnamed 220: DI7.1 (K), DI8.2 (A), J1.4; also elsewhere on the board

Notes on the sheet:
CASE OF REGULATOR, LM323, AND HEAT SINK TABS OF REMAINING THREE REGULATORS ARE ALL AT DIFFERENT ELECTRICAL POTENTIALS. CAUTION SHOULD BE EXERCISED TO INSURE AGAINST DIRECT ELECTRICAL CONTACT BETWEEN THESE POINTS. THEY MUST NOT BE SHORTED TOGETHER, NOR TO THE HEATSINK OF THE LM323.

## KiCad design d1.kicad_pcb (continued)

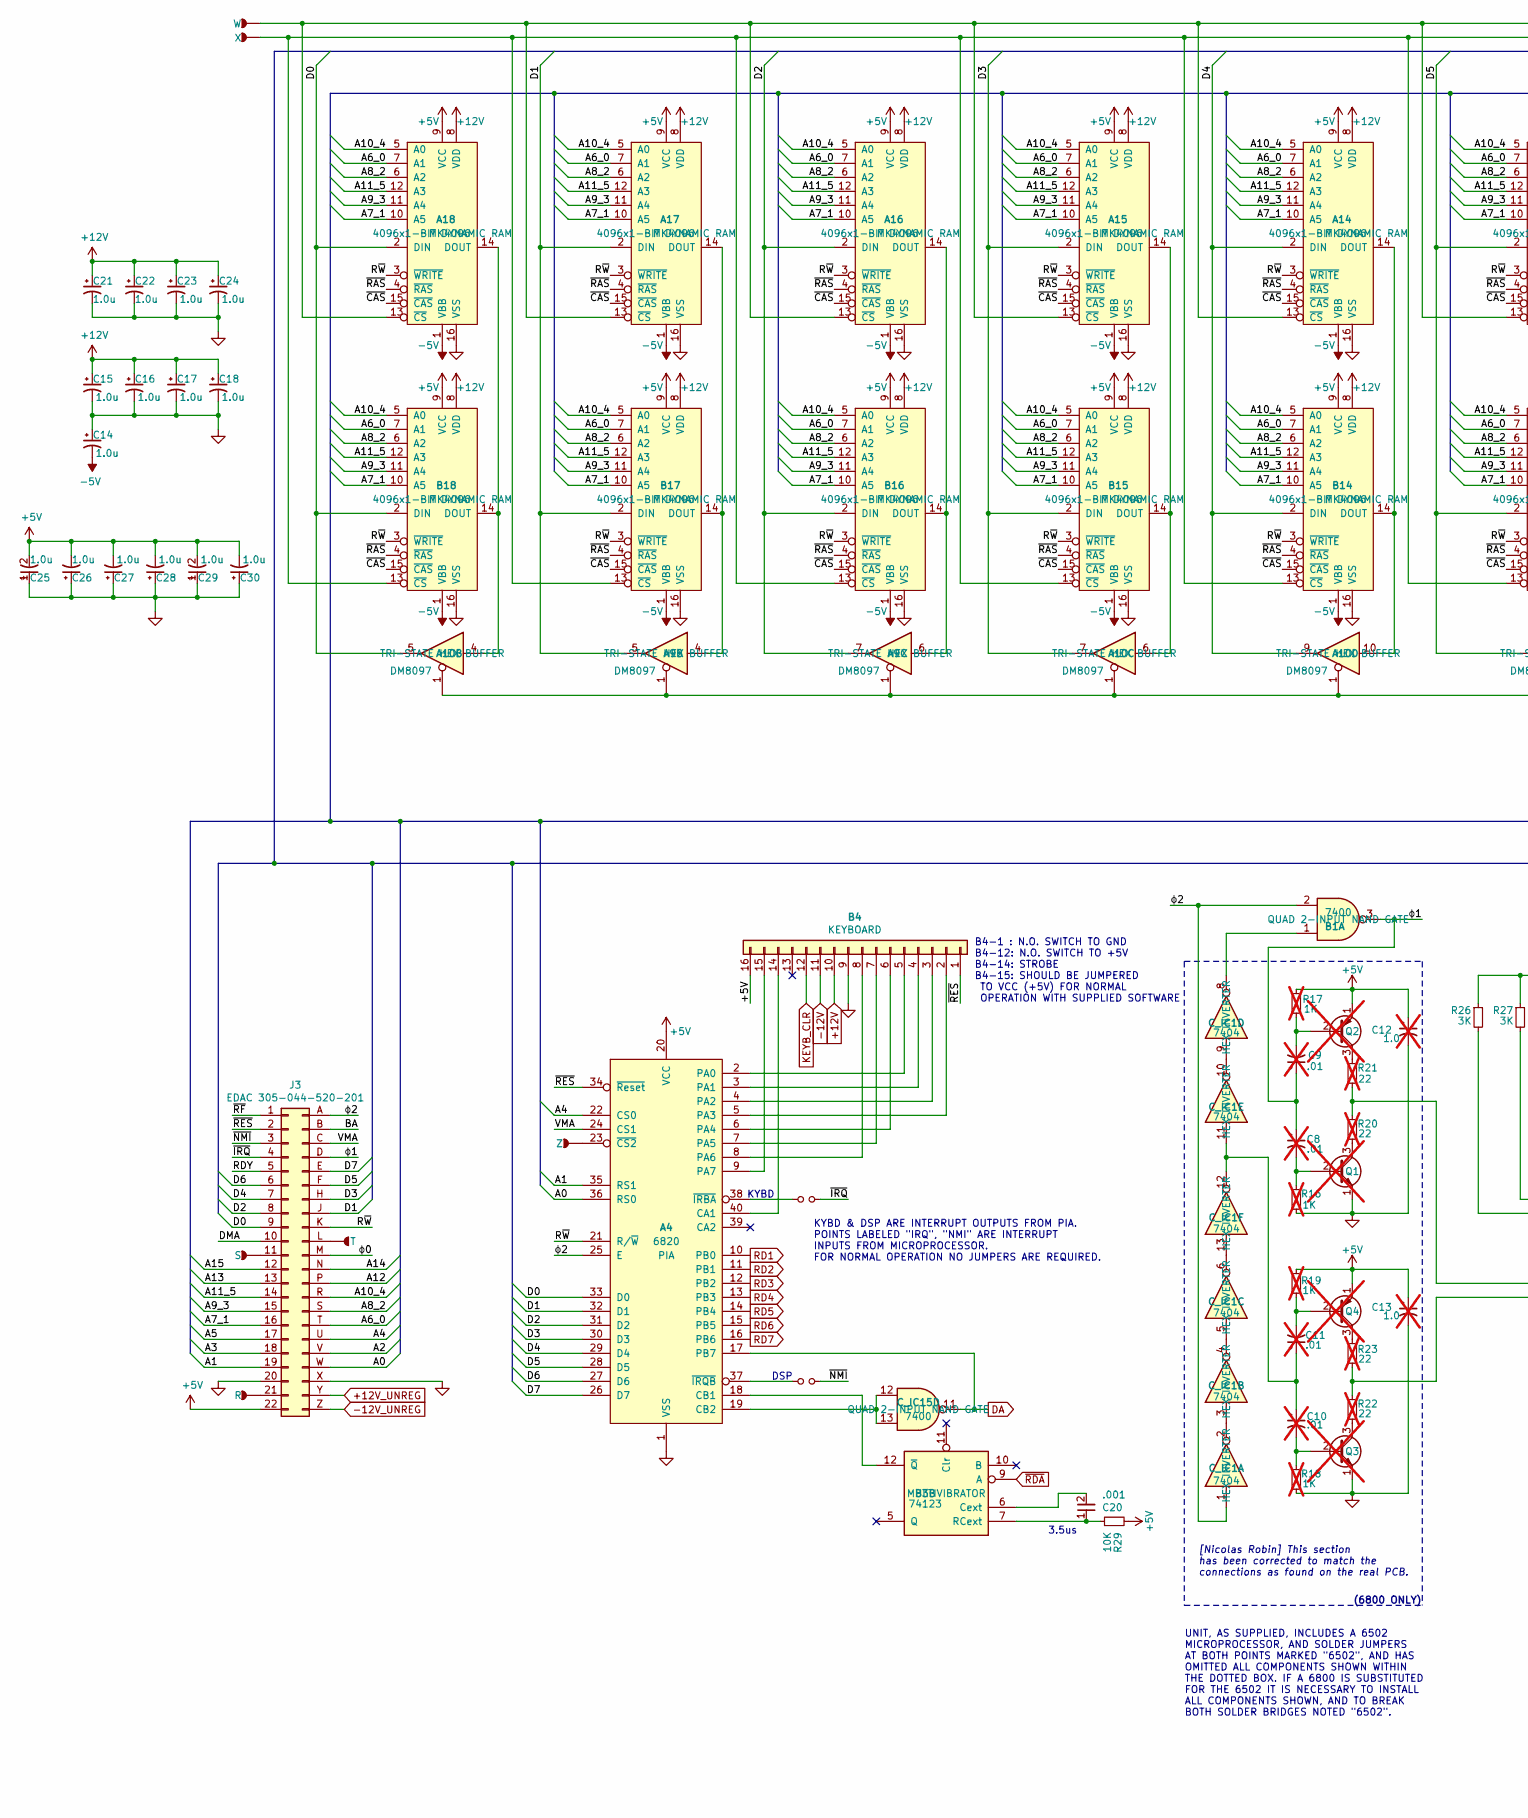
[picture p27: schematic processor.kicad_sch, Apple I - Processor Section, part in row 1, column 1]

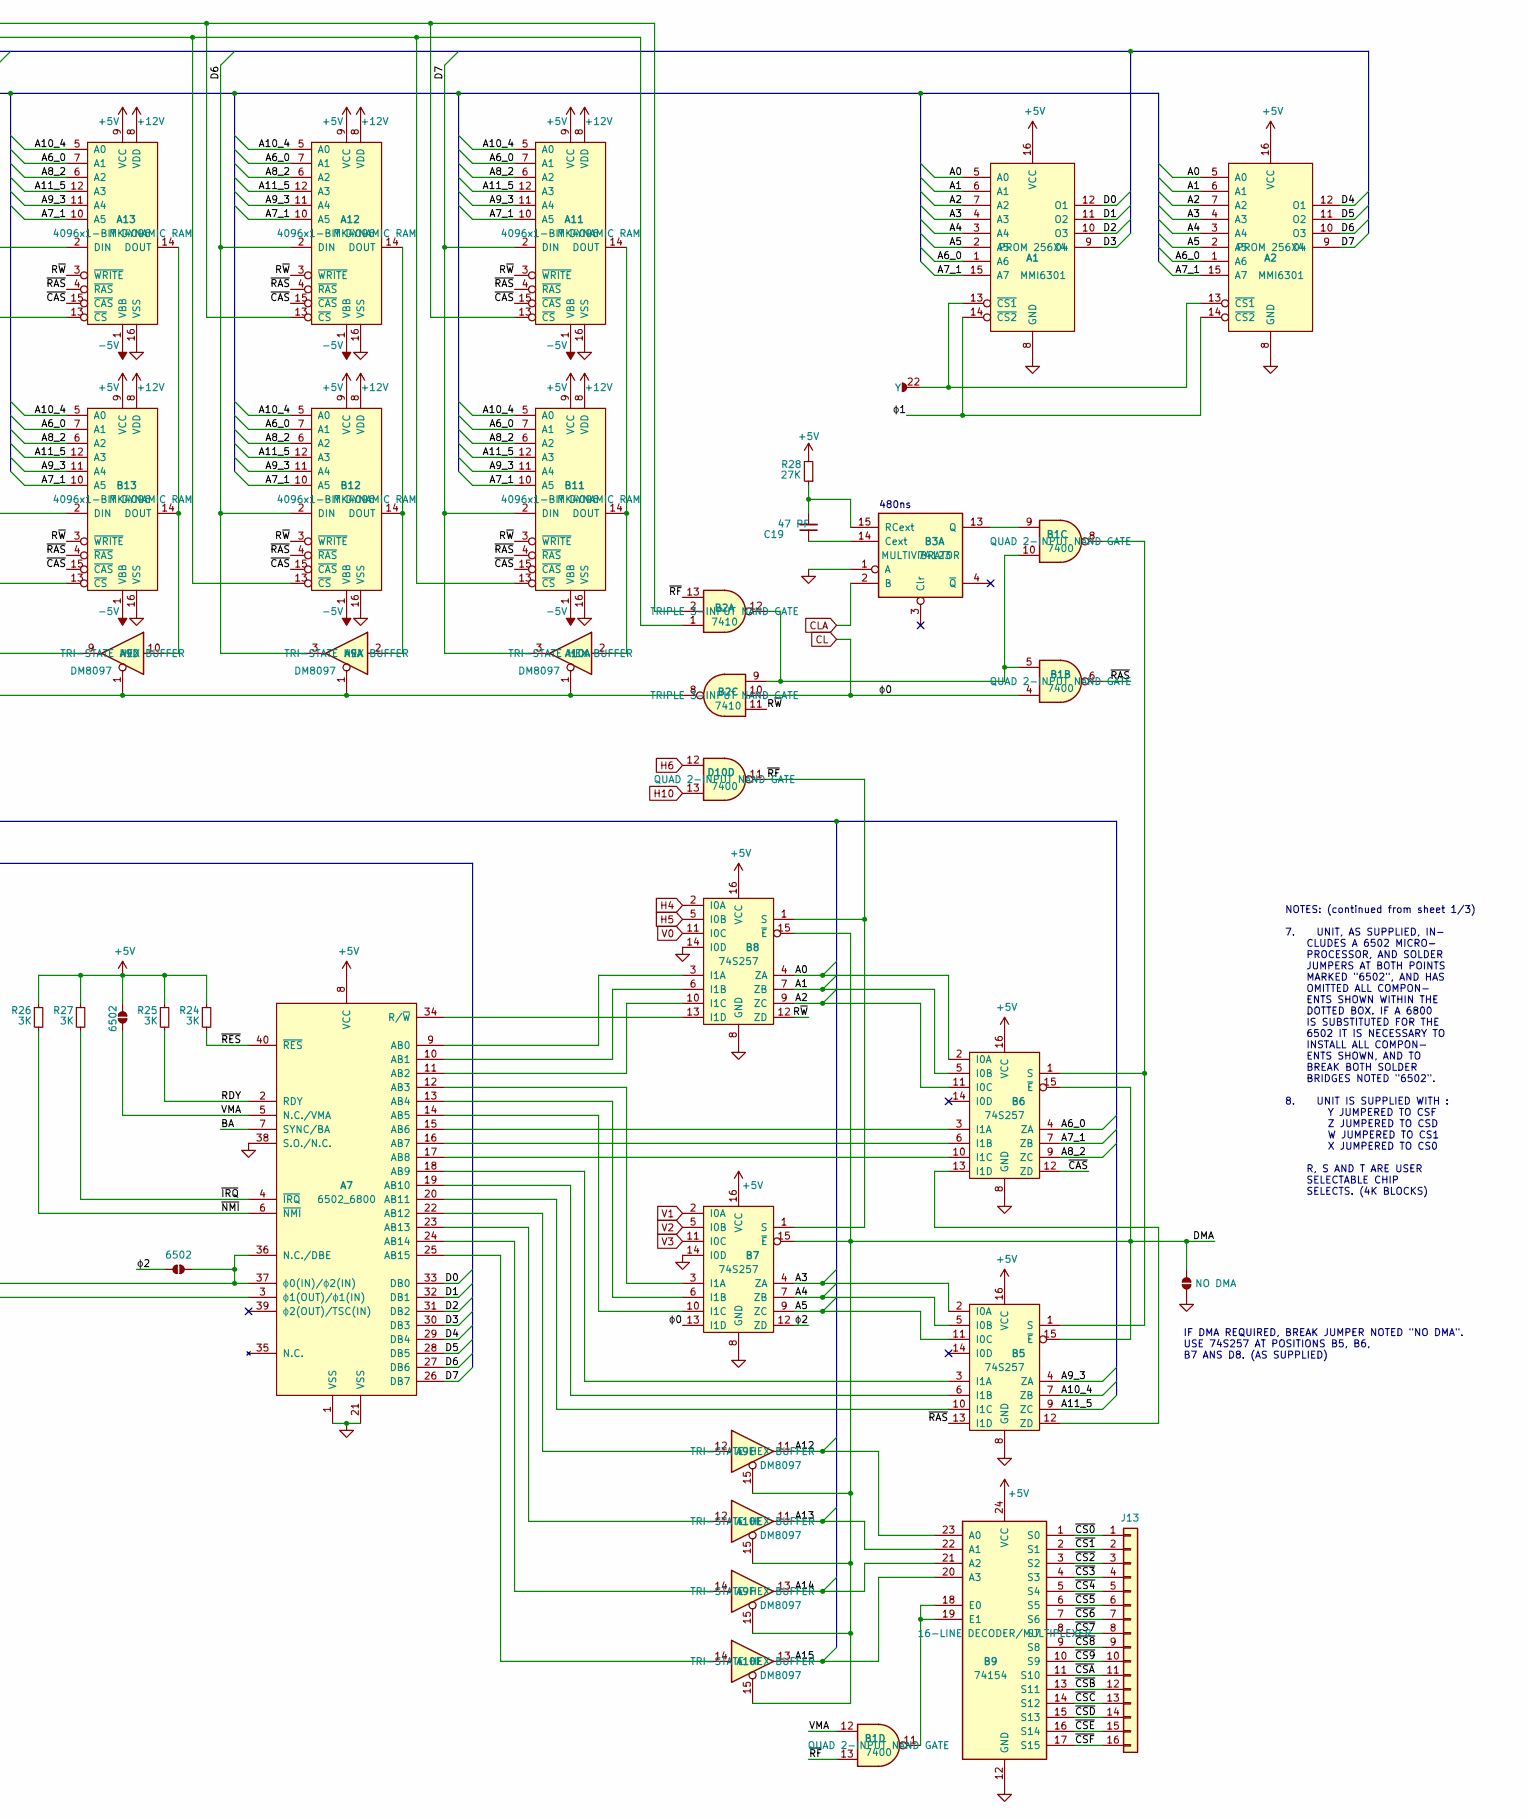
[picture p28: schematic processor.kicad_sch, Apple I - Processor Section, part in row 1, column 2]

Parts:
A1, A2: MMI6301; apple-1_DIP-16_W7.62mm
A4: 6820; apple-1_DIP-40_W15.24mm
A7: 6502_6800; apple-1_DIP-40_W15.24mm
A9, A10: DM8097; apple-1_DIP-16_W7.62mm
A11, A12, A13, A14, A15, A16, A17, A18: MK4096; apple-1_DIP-16_W7.62mm
B1: 7400; apple-1_DIP-14_W7.62mm
B2: 7410; apple-1_DIP-14_W7.62mm
B3: 74123; apple-1_DIP-16_W7.62mm
B4: KEYBOARD; apple-1_DIP-16_W7.62mm
B5, B6, B7, B8: 74S257; apple-1_DIP-16_W7.62mm
B9: 74154; apple-1_DIP-24_18.0mmx34.29mm_W15.24mm
B11, B12, B13, B14, B15, B16, B17, B18: MK4096; apple-1_DIP-16_W7.62mm
C8, C9, C10, C11: .01; apple-1_C_Disc_D16.0mm_W5.0mm_P7.50mm (68000 section); not fitted
C12, C13: 1.0; apple-1_C_Disc_D16.0mm_W5.0mm_P7.50mm (68000 section); not fitted
C14, C25, C26, C27, C28, C29, C30: 1.0u; apple-1_C_Disc_D16.0mm_W5.0mm_P7.50mm
C15, C16, C17, C18, C21, C22, C23, C24: 1.0u; apple-1_C_Disc_D16.0mm_W5.0mm_P275mils
C19: 47 PF; apple-1_C_Disc_D16.0mm_W5.0mm_P7.50mm
C20: .001; apple-1_C_Disc_D16.0mm_W5.0mm_P7.50mm
C_IC1: 7404; apple-1_DIP-14_W7.62mm
C_IC15: 7400; apple-1_DIP-14_W7.62mm
D10: 7400; apple-1_DIP-14_W7.62mm
J3: EDAC 305-044-520-201; 307044520201
J4: W; WJumper
J5: X; XJumper
J6: S; SJumper
J7: R; RJumper
J8: T; TJumper
J9: Z; ZJumper
J10, J11: 6502
J12: Y; YJumper
J13: Conn_01x16; J13
J14: NO DMA
JP1: Jumper_NO_Small; apple-1_KBD-IRQ
JP2: Jumper_NO_Small; apple-1_DSP-NMI
Q1, Q3: Q_NPN_EBC; apple-1_TO-92_HandSolder; not fitted
Q2, Q4: Q_PNP_EBC; apple-1_TO-92_HandSolder; not fitted
R16, R17, R18, R19: 1K; apple-1_R_Axial_DIN0207_L6.3mm_D2.5mm_P10.16mm_Horizontal; not fitted
R20, R21, R22, R23: 22; apple-1_R_Axial_DIN0207_L6.3mm_D2.5mm_P10.16mm_Horizontal; not fitted
R24, R25, R26, R27: 3K; apple-1_R_Axial_DIN0207_L6.3mm_D2.5mm_P10.16mm_Horizontal
R28: 27K; apple-1_R_Axial_DIN0207_L6.3mm_D2.5mm_P10.16mm_Horizontal
R29: 10K; apple-1_R_Axial_DIN0207_L6.3mm_D2.5mm_P10.16mm_Horizontal

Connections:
+5V: A1.16 (VCC), A2.16 (VCC), A4.20 (VCC), A7.8 (VCC), A11.9 (VCC), A12.9 (VCC), A13.9 (VCC), A14.9 (VCC), A15.9 (VCC), A16.9 (VCC), A17.9 (VCC), A18.9 (VCC), B4.16, B5.16 (VCC), B6.16 (VCC), B7.16 (VCC), B8.16 (VCC), B9.24 (VCC), B11.9 (VCC), B12.9 (VCC), B13.9 (VCC), B14.9 (VCC), B15.9 (VCC), B16.9 (VCC), B17.9 (VCC), B18.9 (VCC), C12.1, C13.1, C25.2, C26.2, C27.2, C28.2, C29.2, C30.2, J3.22, J10.1, Q2.1 (E), Q4.1 (E), R17.2, R19.2, R24.1, R25.1, R26.1, R27.1, R28.2, R29.2; also elsewhere on the board
+12V: A11.8 (VDD), A12.8 (VDD), A13.8 (VDD), A14.8 (VDD), A15.8 (VDD), A16.8 (VDD), A17.8 (VDD), A18.8 (VDD), B4.10, B11.8 (VDD), B12.8 (VDD), B13.8 (VDD), B14.8 (VDD), B15.8 (VDD), B16.8 (VDD), B17.8 (VDD), B18.8 (VDD), C15.1, C16.1, C17.1, C18.1, C21.1, C22.1, C23.1, C24.1; also elsewhere on the board
+12V_UNREG: J3.Y; also elsewhere on the board
-5V: A11.1 (VBB), A12.1 (VBB), A13.1 (VBB), A14.1 (VBB), A15.1 (VBB), A16.1 (VBB), A17.1 (VBB), A18.1 (VBB), B11.1 (VBB), B12.1 (VBB), B13.1 (VBB), B14.1 (VBB), B15.1 (VBB), B16.1 (VBB), B17.1 (VBB), B18.1 (VBB), C14.2; also elsewhere on the board
-12V: B4.11; also elsewhere on the board
-12V_UNREG: J3.Z; also elsewhere on the board
/Processor Section/A0: A1.5 (A0), A2.5 (A0), A4.36 (RS0), B6.2 (I0A), B8.4 (ZA), J3.W
/Processor Section/A1: A1.6 (A1), A2.6 (A1), A4.35 (RS1), B6.5 (I0B), B8.7 (ZB), J3.19
/Processor Section/A2: A1.7 (A2), A2.7 (A2), B6.11 (I0C), B8.9 (ZC), J3.V
/Processor Section/A3: A1.4 (A3), A2.4 (A3), B5.2 (I0A), B7.4 (ZA), J3.18
/Processor Section/A4: A1.3 (A4), A2.3 (A4), A4.22 (CS0), B5.5 (I0B), B7.7 (ZB), J3.U
/Processor Section/A5: A1.2 (A5), A2.2 (A5), B5.11 (I0C), B7.9 (ZC), J3.17
/Processor Section/A6_0: A1.1 (A6), A2.1 (A6), A11.7 (A1), A12.7 (A1), A13.7 (A1), A14.7 (A1), A15.7 (A1), A16.7 (A1), A17.7 (A1), A18.7 (A1), B6.4 (ZA), B11.7 (A1), B12.7 (A1), B13.7 (A1), B14.7 (A1), B15.7 (A1), B16.7 (A1), B17.7 (A1), B18.7 (A1), J3.T
/Processor Section/A7_1: A1.15 (A7), A2.15 (A7), A11.10 (A5), A12.10 (A5), A13.10 (A5), A14.10 (A5), A15.10 (A5), A16.10 (A5), A17.10 (A5), A18.10 (A5), B6.7 (ZB), B11.10 (A5), B12.10 (A5), B13.10 (A5), B14.10 (A5), B15.10 (A5), B16.10 (A5), B17.10 (A5), B18.10 (A5), J3.16
/Processor Section/A8_2: A11.6 (A2), A12.6 (A2), A13.6 (A2), A14.6 (A2), A15.6 (A2), A16.6 (A2), A17.6 (A2), A18.6 (A2), B6.9 (ZC), B11.6 (A2), B12.6 (A2), B13.6 (A2), B14.6 (A2), B15.6 (A2), B16.6 (A2), B17.6 (A2), B18.6 (A2), J3.S
/Processor Section/A9_3: A11.11 (A4), A12.11 (A4), A13.11 (A4), A14.11 (A4), A15.11 (A4), A16.11 (A4), A17.11 (A4), A18.11 (A4), B5.4 (ZA), B11.11 (A4), B12.11 (A4), B13.11 (A4), B14.11 (A4), B15.11 (A4), B16.11 (A4), B17.11 (A4), B18.11 (A4), J3.15
/Processor Section/A10_4: A11.5 (A0), A12.5 (A0), A13.5 (A0), A14.5 (A0), A15.5 (A0), A16.5 (A0), A17.5 (A0), A18.5 (A0), B5.7 (ZB), B11.5 (A0), B12.5 (A0), B13.5 (A0), B14.5 (A0), B15.5 (A0), B16.5 (A0), B17.5 (A0), B18.5 (A0), J3.R
/Processor Section/A11_5: A11.12 (A3), A12.12 (A3), A13.12 (A3), A14.12 (A3), A15.12 (A3), A16.12 (A3), A17.12 (A3), A18.12 (A3), B5.9 (ZC), B11.12 (A3), B12.12 (A3), B13.12 (A3), B14.12 (A3), B15.12 (A3), B16.12 (A3), B17.12 (A3), B18.12 (A3), J3.14
/Processor Section/A12: A9.11, B9.23 (A0), J3.P
/Processor Section/A13: A10.11, B9.22 (A1), J3.13
/Processor Section/A14: A9.13, B9.21 (A2), J3.N
/Processor Section/A15: A10.13, B9.20 (A3), J3.12
/Processor Section/BA: A7.7 (SYNC/BA), J3.B
/Processor Section/D0: A1.12 (O1), A4.33 (D0), A7.33 (DB0), A10.5, A18.2 (DIN), B18.2 (DIN), J3.9
/Processor Section/D1: A1.11 (O2), A4.32 (D1), A7.32 (DB1), A9.5, A17.2 (DIN), B17.2 (DIN), J3.J
/Processor Section/D2: A1.10 (O3), A4.31 (D2), A7.31 (DB2), A9.7, A16.2 (DIN), B16.2 (DIN), J3.8
/Processor Section/D3: A1.9 (O4), A4.30 (D3), A7.30 (DB3), A10.7, A15.2 (DIN), B15.2 (DIN), J3.H
/Processor Section/D4: A2.12 (O1), A4.29 (D4), A7.29 (DB4), A10.9, A14.2 (DIN), B14.2 (DIN), J3.7
/Processor Section/D5: A2.11 (O2), A4.28 (D5), A7.28 (DB5), A9.9, A13.2 (DIN), B13.2 (DIN), J3.F
/Processor Section/D6: A2.10 (O3), A4.27 (D6), A7.27 (DB6), A9.3, A12.2 (DIN), B12.2 (DIN), J3.6
/Processor Section/D7: A2.9 (O4), A4.26 (D7), A7.26 (DB7), A10.3, A11.2 (DIN), B11.2 (DIN), J3.E
/Processor Section/DMA: A9.15, A10.15, B5.15 (~E), B6.15 (~E), B7.15 (~E), B8.15 (~E), J3.10, J14.1
/Processor Section/RDY: A7.2 (RDY), J3.5, R25.2
/Processor Section/R~W: A4.21 (R/~W), A11.3 (~WRITE), A12.3 (~WRITE), A13.3 (~WRITE), A14.3 (~WRITE), A15.3 (~WRITE), A16.3 (~WRITE), A17.3 (~WRITE), A18.3 (~WRITE), B2.11, B8.12 (ZD), B11.3 (~WRITE), B12.3 (~WRITE), B13.3 (~WRITE), B14.3 (~WRITE), B15.3 (~WRITE), B16.3 (~WRITE), B17.3 (~WRITE), B18.3 (~WRITE), J3.K
/Processor Section/VMA: A4.24 (CS1), A7.5 (N.C./VMA), B1.12, J3.C, J10.2
/Processor Section/~CAS: A11.15 (~CAS), A12.15 (~CAS), A13.15 (~CAS), A14.15 (~CAS), A15.15 (~CAS), A16.15 (~CAS), A17.15 (~CAS), A18.15 (~CAS), B6.12 (ZD), B11.15 (~CAS), B12.15 (~CAS), B13.15 (~CAS), B14.15 (~CAS), B15.15 (~CAS), B16.15 (~CAS), B17.15 (~CAS), B18.15 (~CAS)
/Processor Section/~CS0: B9.1 (S0), J13.1
/Processor Section/~CS1: B9.2 (S1), J13.2
/Processor Section/~CS2: B9.3 (S2), J13.3
/Processor Section/~CS3: B9.4 (S3), J13.4
/Processor Section/~CS4: B9.5 (S4), J13.5
/Processor Section/~CS5: B9.6 (S5), J13.6
/Processor Section/~CS6: B9.7 (S6), J13.7
/Processor Section/~CS7: B9.8 (S7), J13.8
/Processor Section/~CS8: B9.9 (S8), J13.9
/Processor Section/~CS9: B9.10 (S9), J13.10
/Processor Section/~CSA: B9.11 (S10), J13.11
/Processor Section/~CSB: B9.13 (S11), J13.12
/Processor Section/~CSC: B9.14 (S12), J13.13
/Processor Section/~CSD: B9.15 (S13), J13.14
/Processor Section/~CSE: B9.16 (S14), J13.15
/Processor Section/~CSF: B9.17 (S15), J13.16
/Processor Section/~IRQ: A7.4 (~IRQ), J3.4, JP1.2, R27.2
/Processor Section/~NMI: A7.6 (~NMI), J3.3, JP2.2, R26.2
/Processor Section/~RAS: A11.4 (~RAS), A12.4 (~RAS), A13.4 (~RAS), A14.4 (~RAS), A15.4 (~RAS), A16.4 (~RAS), A17.4 (~RAS), A18.4 (~RAS), B1.6, B5.13 (I1D), B11.4 (~RAS), B12.4 (~RAS), B13.4 (~RAS), B14.4 (~RAS), B15.4 (~RAS), B16.4 (~RAS), B17.4 (~RAS), B18.4 (~RAS)
/Processor Section/~RES: A4.34 (~Reset), A7.40 (~RES), B4.1, J3.2, R24.2
/Processor Section/~RF: B1.13, B2.13, B7.1 (S), B8.1 (S), D10.11, J3.1
/Processor Section/ɸ1: A1.14 (~CS2), A2.14 (~CS2), B1.3, C8.1, C9.1, J3.D
/Processor Section/ɸ2: A4.25 (E), B1.2, B7.12 (ZD), C_IC1.1, J3.A, J11.2
CL: B1.4, B2.10, B7.13 (I1D), J3.M; also elsewhere on the board
CLA: B3.2 (B); also elsewhere on the board
DA: A4.17 (PB7), C_IC15.11; also elsewhere on the board
H4: B8.2 (I0A); also elsewhere on the board
H5: B8.5 (I0B); also elsewhere on the board
H6: D10.12; also elsewhere on the board
H10: D10.13; also elsewhere on the board
KEYB_CLR: B4.12; also elsewhere on the board
unnamed: A1.13 (~CS1), A2.13 (~CS1), J12.22 (~_22)
unnamed: A4.40 (CA1), B4.14
unnamed: A4.18 (CB1), B3.12 (~Q)
unnamed: A4.19 (CB2), C_IC15.12, C_IC15.13
unnamed: A4.2 (PA0), B4.5
unnamed: A4.3 (PA1), B4.4
unnamed: A4.4 (PA2), B4.3
unnamed: A4.5 (PA3), B4.2
unnamed: A4.6 (PA4), B4.6
unnamed: A4.7 (PA5), B4.7
unnamed: A4.8 (PA6), B4.8
unnamed: A4.9 (PA7), B4.15
unnamed: A4.23 (~CS2), J9.23 (~_23)
unnamed: A4.38 (~IRBA), JP1.1
unnamed: A4.37 (~IRQB), JP2.1
unnamed: A7.9 (AB0), B8.3 (I1A)
unnamed: A7.10 (AB1), B8.6 (I1B)
unnamed: A7.11 (AB2), B8.10 (I1C)
unnamed: A7.12 (AB3), B7.3 (I1A)
unnamed: A7.13 (AB4), B7.6 (I1B)
unnamed: A7.14 (AB5), B7.10 (I1C)
unnamed: A7.15 (AB6), B6.3 (I1A)
unnamed: A7.16 (AB7), B6.6 (I1B)
unnamed: A7.17 (AB8), B6.10 (I1C)
unnamed: A7.18 (AB9), B5.3 (I1A)
unnamed: A7.19 (AB10), B5.6 (I1B)
unnamed: A7.20 (AB11), B5.10 (I1C)
unnamed: A7.22 (AB12), A9.12
unnamed: A7.23 (AB13), A10.12
unnamed: A7.24 (AB14), A9.14
unnamed: A7.25 (AB15), A10.14
unnamed: A7.36 (N.C./DBE), A7.37 (ɸ0(IN)/ɸ2(IN)), J11.1, R20.1, R21.2
unnamed: A7.34 (R/~W), B8.13 (I1D)
unnamed: A7.3 (ɸ1(OUT)/ɸ1(IN)), R22.1, R23.2
unnamed: A9.1, A10.1, B2.8
unnamed: A10.2, A11.14 (DOUT), B11.14 (DOUT)
unnamed: A11.13 (~CS), A12.13 (~CS), A13.13 (~CS), A14.13 (~CS), A15.13 (~CS), A16.13 (~CS), A17.13 (~CS), A18.13 (~CS), B2.2, J4.20 (~_20)
unnamed: A9.2, A12.14 (DOUT), B12.14 (DOUT)
unnamed: A9.10, A13.14 (DOUT), B13.14 (DOUT)
unnamed: A10.10, A14.14 (DOUT), B14.14 (DOUT)
unnamed: A10.6, A15.14 (DOUT), B15.14 (DOUT)
unnamed: A9.6, A16.14 (DOUT), B16.14 (DOUT)
unnamed: A9.4, A17.14 (DOUT), B17.14 (DOUT)
unnamed: A10.4, A18.14 (DOUT), B18.14 (DOUT)
unnamed: B1.1, C_IC1.8
unnamed: B1.5, B1.10, B2.9, B2.12
unnamed: B3.14 (Cext), C19.1
unnamed: B1.9, B3.13 (Q)
unnamed: B3.15 (RCext), C19.2, R28.1
unnamed: B3.6 (Cext), C20.2
unnamed: B3.7 (RCext), C20.1, R29.1
unnamed: B1.8, B5.1 (S), B6.1 (S)
unnamed: B5.12 (ZD), B6.13 (I1D)
unnamed: B1.11, B9.18 (E0), B9.19 (E1)
unnamed: B2.1, B11.13 (~CS), B12.13 (~CS), B13.13 (~CS), B14.13 (~CS), B15.13 (~CS), B16.13 (~CS), B17.13 (~CS), B18.13 (~CS), J5.21 (~_21)
unnamed: C10.1, C11.1, C_IC1.11, C_IC1.12
unnamed: C_IC1.2, C_IC1.3
unnamed: C_IC1.4, C_IC1.5
unnamed: C_IC1.9, C_IC1.10
unnamed: C_IC1.6, C_IC1.13
unnamed: J3.11, J6.18 (~_18)
unnamed: J3.21, J7.1 (~_1)
unnamed: J3.L, J8.19 (~_19)
unnamed: C8.2, Q1.2 (B), R16.1
unnamed: Q1.3 (C), R20.2
unnamed: C9.2, Q2.2 (B), R17.1
unnamed: Q2.3 (C), R21.1
unnamed: C10.2, Q3.2 (B), R18.1
unnamed: Q3.3 (C), R22.2
unnamed: C11.2, Q4.2 (B), R19.1
unnamed: Q4.3 (C), R23.1
RD1: A4.10 (PB0); also elsewhere on the board
RD2: A4.11 (PB1); also elsewhere on the board
RD3: A4.12 (PB2); also elsewhere on the board
RD4: A4.13 (PB3); also elsewhere on the board
RD5: A4.14 (PB4); also elsewhere on the board
RD6: A4.15 (PB5); also elsewhere on the board
RD7: A4.16 (PB6); also elsewhere on the board
V0: B8.11 (I0C); also elsewhere on the board
V1: B7.2 (I0A); also elsewhere on the board
V2: B7.5 (I0B); also elsewhere on the board
V3: B7.11 (I0C); also elsewhere on the board
~RDA: B3.9 (A); also elsewhere on the board

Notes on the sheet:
[Nicolas Robin] This section has been corrected to match the connections as found on the real PCB.
UNIT, AS SUPPLIED, INCLUDES A 6502 MICROPROCESSOR, AND SOLDER JUMPERS AT BOTH POINTS MARKED "6502", AND HAS OMITTED ALL COMPONENTS SHOWN WITHIN THE DOTTED BOX. IF A 6800 IS SUBSTITUTED FOR THE 6502 IT IS NECESSARY TO INSTALL ALL COMPONENTS SHOWN, AND TO BREAK BOTH SOLDER BRIDGES NOTED "6502".
DSP
KYBD
KYBD & DSP ARE INTERRUPT OUTPUTS FROM PIA. POINTS LABELED "IRQ", "NMI" ARE INTERRUPT INPUTS FROM MICROPROCESSOR. FOR NORMAL OPERATION NO JUMPERS ARE REQUIRED.
NOTES: (continued from sheet 1/3) 7. UNIT, AS SUPPLIED, IN- CLUDES A 6502 MICRO- PROCESSOR, AND SOLDER JUMPERS AT BOTH POINTS MARKED "6502", AND HAS OMITTED ALL COMPON- ENTS SHOWN WITHIN THE DOTTED BOX. IF A 6800 IS SUBSTITUTED FOR THE 6502 IT IS NECESSARY TO INSTALL ALL COMPON- ENTS SHOWN, AND TO 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
(6800 ONLY)
IF DMA REQUIRED, BREAK JUMPER NOTED "NO DMA". USE 74S257 AT POSITIONS B5, B6, B7 ANS D8. (AS SUPPLIED)
B4-1 : N.O. SWITCH TO GND B4-12: N.O. SWITCH TO +5V B4-14: STROBE B4-15: SHOULD BE JUMPERED TO VCC (+5V) FOR NORMAL OPERATION WITH SUPPLIED SOFTWARE
480ns
3.5us

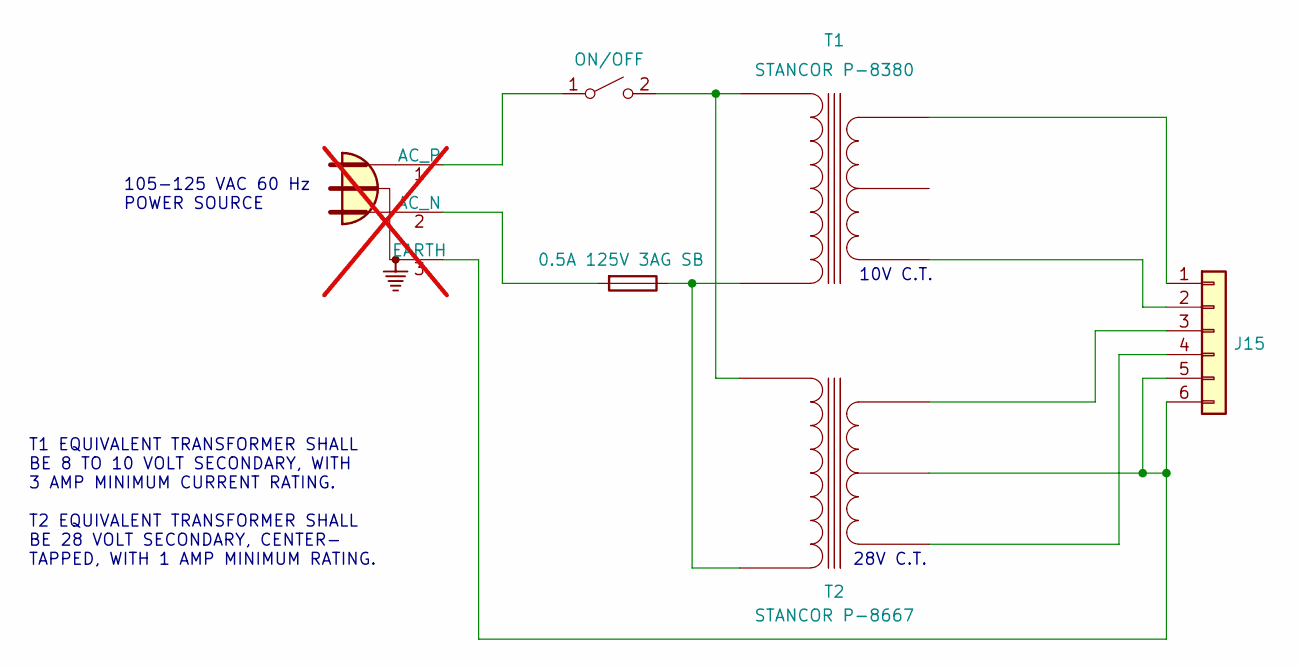
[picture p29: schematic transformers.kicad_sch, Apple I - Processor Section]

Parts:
F1: 0.5A 125V 3AG SB
J15: Conn_01x06
P1: Conn_WallPlug_Earth; not fitted
SW1: ON/OFF
T1: STANCOR P-8380
T2: STANCOR P-8667

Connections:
unnamed 216: T1.~; also elsewhere on the board
unnamed 218: T1.~; also elsewhere on the board
unnamed 219: T2.~; also elsewhere on the board
unnamed 220: T2.~; also elsewhere on the board
unnamed: F1.1, T1.~, T2.~
unnamed: F1.2, P1.2 (AC_N)
unnamed: P1.1 (AC_P), SW1.1 (A)
unnamed: SW1.2 (B), T1.~, T2.~

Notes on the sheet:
10V C.T.
28V C.T.
105-125 VAC 60 Hz POWER SOURCE
T1 EQUIVALENT TRANSFORMER SHALL BE 8 TO 10 VOLT SECONDARY, WITH 3 AMP MINIMUM CURRENT RATING. T2 EQUIVALENT TRANSFORMER SHALL BE 28 VOLT SECONDARY, CENTER- TAPPED, WITH 1 AMP MINIMUM RATING.

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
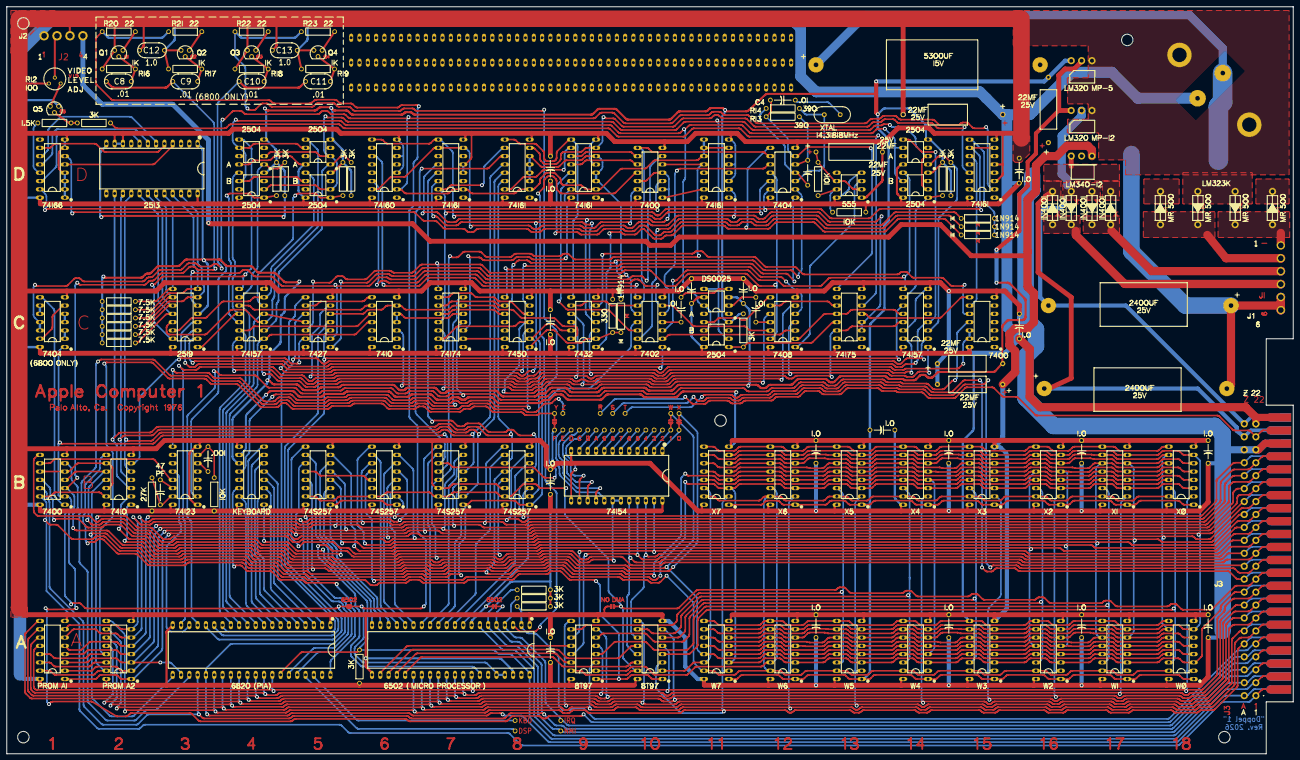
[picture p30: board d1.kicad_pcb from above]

Board: 2 copper layers, 393.7 x 228.6 mm, 170 parts (0 on the bottom side), 248 nets.

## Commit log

2026-09-19 Created edge finger footprint
    [d1.kicad_pcb]
2026-09-19 Clean up unused footprints, added edge finger footprint
